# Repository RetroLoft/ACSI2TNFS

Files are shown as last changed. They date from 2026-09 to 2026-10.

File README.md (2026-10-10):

# ACSI2TNFS

A Raspberry Pi Pico 2 W on the **ACSI** (hard disk) port of an Atari ST, STE, Mega ST
or TT. To the Atari it is a hard disk; behind it is Wi-Fi.

- **Drive C:** a small hard disk (about 1 MB) in the Pico's flash. The Atari can boot
  from it.
- **Network drives:** up to three folders on a **TNFS** server (a PC, a NAS or the
  internet) show up as normal drives, readable and writable.
- **Clock:** the Pico gets the time from the internet and sets the Atari's clock at
  start-up.
- **Internet:** with the STinG TCP/IP stack the Atari gets its own IP address on your
  Wi-Fi network: ping, FTP, web pages.

No software to install for the disk part: the adapter brings its own driver. A GEM
program, **ACSITNFS.PRG**, sets up Wi-Fi, network drives, clock and the ACSI id.

> Status: working on real hardware (ST with TOS 1.02/1.04 and EmuTOS). The network
> function (STinG) is new and still being refined.

## What you need

- The ACSI2TNFS board with a **Raspberry Pi Pico 2 W**: `v2` plugs straight into the
  Atari, `v2-cable` connects with a flat cable to a Lotharek DB19 adapter and has a
  pass-through connector. See [hardware/README.md](hardware/README.md).
- An Atari with an ACSI port and **TOS 1.02 or later**, or EmuTOS. TOS 1.0 does not
  see the adapter.
- A 2.4 GHz Wi-Fi network.
- A USB cable for the Pico: it powers the adapter and gives a console on your PC.

## Getting started

1. **Firmware.** Hold the Pico's BOOTSEL button while you plug it into a PC, and copy
   `acsi2tnfs.uf2` onto the drive that appears (build it yourself: see
   [docs/DEVELOPMENT.md](docs/DEVELOPMENT.md)). The Pico restarts and prepares drive C:.
2. **Connect** the adapter to the Atari's ACSI port and power the Pico over USB.
   Switch the Atari on. You see `ACSI2TNFS v…` and `[OK] Drives installed: C:`.
3. **Show C: on the desktop.** Select the floppy A: icon, *Options → Install Disk Drive*,
   letter `C`, *Install*, then *Options → Save Desktop*. C: holds `README.TXT` and the
   programs below.
4. **Set up Wi-Fi and network drives.** Start `C:\ACSITNFS.PRG`: *Config* for Wi-Fi
   (network name, password, country) with *More* for the clock and the ACSI id, and the
   drive list for the TNFS drives (server, folder, drive letter). *Save*; the Pico
   restarts and the Atari with it.

From then on the Atari boots with C:, the network drives and the right time.

### Good to know

- **ACSI id.** A new adapter uses ACSI id **6**, so it does not clash with a hard disk on
  id 0. Every device on the ACSI bus needs its own id.
- **Drive letters** for network drives: D: to P: (TOS knows 16 drives).
- **TOS 1.x with several drives:** put `FOLDR100.PRG` (from Atari's AHDI) in `C:\AUTO`,
  or TOS runs out of folder memory ("use FOLDR100.PRG").
- **Read-only files on C:** `README.TXT`, `ACSITNFS.PRG` and `ACSI_NET.STX` come with
  the firmware. Your own files (DESKTOP.INF, an AUTO folder, …)
  stay when you update the firmware.

More: [docs/ADAPTER.md](docs/ADAPTER.md) (USB console, ACSI id, hidden mode, C:,
troubleshooting) and [docs/TNFS.md](docs/TNFS.md) (network drives, running a TNFS server).

## Internet on the Atari (STinG)

The adapter passes network traffic between the Atari and your Wi-Fi network. The Atari
runs the [STinG](https://github.com/th-otto/STinG) TCP/IP stack (free, for TOS); the
driver `ACSI_NET.STX` on C: connects STinG to the adapter.

**You need:** STinG 1.26 and XControl 1.31 (both free):

| | Download |
|---|---|
| STinG 1.26 | [sting126.lzh](https://chebucto.ns.ca/Services/PDA/sting126.lzh) ([page](https://chebucto.ns.ca/Services/PDA/AtariSTComm.shtml)) |
| XControl 1.31 (control panel for the CPX modules) | [xctl131.zip](https://chebucto.ns.ca/Services/PDA/xctl131.zip) |
| `ACSI_NET.STX` | on C: of the adapter |

**In short:**

1. Install STinG: `STING.PRG` and `STING.INF` in `C:\AUTO`, the `STING` folder with
   `TCP.STX`, `UDP.STX`, `RESOLVE.STX`, `DEFAULT.CFG` and `ROUTE.TAB`.
2. Copy `C:\ACSI_NET.STX` into the `STING` folder.
3. Install XControl (`XCONTROL.ACC` in the root of C:, the STinG CPX modules in `C:\CPX`)
   and restart.
4. *Desk → Control Panel → STinG Port Setup*: port **ACSI2TNFS**, a **free IP address**
   of your network, the subnet mask, **Active**, *Save*.
5. Tell STinG where packets go and who looks up names. With a home network
   `192.168.178.x` and the router on `192.168.178.1` (use your own numbers; on a PC
   `ipconfig` shows them as *Default Gateway* and *Subnet Mask*):
   - `C:\STING\ROUTE.TAB`, instead of the example line (fields separated by tabs):
     ```text
     192.168.178.0	255.255.255.0	ACSI2TNFS	0.0.0.0
     0.0.0.0		0.0.0.0		ACSI2TNFS	192.168.178.1
     ```
     Line 1: your own network, directly. Line 2: everything else via the router.
   - `C:\STING\DEFAULT.CFG`: `NAMESERVER  = 192.168.178.1` (your router).

Test with `PING.PRG` (STinG tools) to your router. Small STinG programs, e.g. a web
page viewer: [Network tools for the Atari ST](https://github.com/RetroLoft/atari-net-tools).

Step by step, with example files and troubleshooting: [docs/NETWORK.md](docs/NETWORK.md).

## Documentation

| | |
|---|---|
| [docs/NETWORK.md](docs/NETWORK.md) | Internet with STinG: installation, IP address, ROUTE.TAB, programs, limits |
| [docs/TNFS.md](docs/TNFS.md) | Network drives: TNFS servers, writing, what to keep in mind |
| [docs/ADAPTER.md](docs/ADAPTER.md) | ACSI id, USB console, system files on C:, TOS versions, troubleshooting |
| [docs/DEVELOPMENT.md](docs/DEVELOPMENT.md) | Building, repository layout, ACSI protocol, test tools |
| `ACSI_NET-ontwerp.md`, `project-notities.md` | Design and project notes (Dutch) |

## Credits

- Configuration program: the ACSI build of
  [SideTNFS-Config](https://github.com/RetroLoft/SideTNFS-Config).
- `ACSI_NET.STX` follows the structure of
  [USB_NET.STX (usbsting)](https://github.com/czietz/usbsting) by Roger Burrows and
  Christian Zietz (GPL-2+), and the frame bridge follows
  [PicoWifi](https://github.com/czietz/picowifi).
- STinG by Peter Rottengatter and Ronald Andersson.

## License

Copyright (C) 2025-2026 Frank Beentjes.

GNU General Public License, version 3 or (at your option) any later version: see
[LICENSE](LICENSE).

- `atari/sting/` (`ACSI_NET.STX`) contains code after USB_NET.STX and is GPL-2.0-or-later
  (`atari/sting/LICENSE`); `atari/sting/include/` holds headers from the STinG developer kit.
- The firmware is built with the Raspberry Pi Pico SDK (BSD-3-Clause), lwIP (BSD) and the
  `cyw43-driver` for the Wi-Fi chip, which Raspberry Pi licenses for use with its own
  microcontrollers only (`lib/cyw43-driver/LICENSE.RP` in the SDK).

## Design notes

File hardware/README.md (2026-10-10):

# ACSI2TNFS hardware

Two boards with the same circuit, so one firmware fits both. Only the connection to the
Atari's ACSI port differs:

| | `v2` | `v2-cable` |
|---|---|---|
| Connection | the board plugs straight into the ACSI port | a 20-wire flat cable to a Lotharek DB19 adapter in the ACSI port |
| Extra parts | 19 special pins for the DB19 | the Lotharek adapter and a flat cable |
| Pass-through | no | yes: a second header for another ACSI device |

> **Firmware:** the current firmware still uses the pin map of the earlier development
> board. A board setting for `v2` / `v2-cable` (different GPIOs, see the pin map below)
> is still to come.

## v2: straight into the ACSI port

The DB19 is part of the board: 19 loose pins soldered into the board take the place of
a DB19 plug (footprint `ACSI_DB19_Male_WAGO_243-131`). The board sits on the back of the
Atari without a cable.

- **Pro:** no adapter and no cable needed.
- **Con:** you need the special pins, e.g. from RS:
  <https://nl.rs-online.com/web/p/terminal-block-accessories/2885173>

## v2-cable: with a Lotharek adapter

The board lies loose behind the Atari and hangs on a Lotharek DB19 adapter through a
20-wire flat cable. That adapter comes with Lotharek's
[UltraSatan](https://lotharek.pl/products.php?id=15): if you already have one, this is the
easiest way.

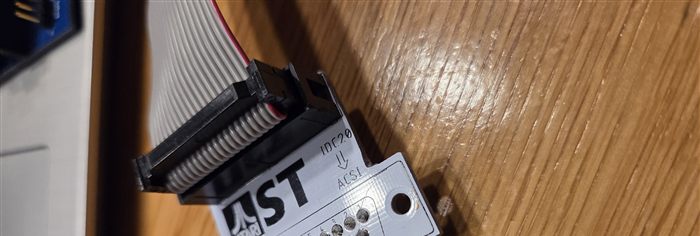
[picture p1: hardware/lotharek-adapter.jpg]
Lotharek DB19 adapter with flat cable


- **J1 "To ACSI"** takes the cable from the adapter. **J2 "ACSI pass-through"** carries
  the same signals on, e.g. to the UltraSatan, which then shares the bus with its own
  ACSI id.
- J1 and J2 are keyed box headers. Their pins are numbered **per row**: 1-10 along the
  row on the side of the key, 11-20 along the other row (footprint
  `IDC-Header_2x10_P2.54mm_Vertical_NR_PER_ROW`).
- So **pin n on the board is ACSI pin n**, because the adapter puts DB19 pins 1-10 on one
  row of its header and 11-19 on the other. This is **not** the usual IDC numbering
  (1 and 2 opposite each other): a standard 2x10 footprint would mix up the signals.
- The cable is a straight 20-wire flat cable with an IDC socket at each end, keyed the
  same way at both ends.

| Pin | Signal | Pin | Signal |
|---|---|---|---|
| 1-8 | DATA0-DATA7 | 11, 13, 15, 17 | GND |
| 9 | /CS | 12 | /RESET |
| 10 | /IRQ | 14 | /ACK |
| | | 16 | A1 |
| | | 18 | R/W |
| | | 19 | /DRQ |
| | | 20 | not used |

## Both boards

- **Raspberry Pi Pico 2 W** on pin headers. The Pico powers the
  board from USB; the ACSI port has no supply pin.
- **U1** 74LVC245: data bus D0-D7, direction (DIR) and enable (/OE) from the Pico.
  **U2** 74LVC245: /CS, /RESET, /ACK, A1 and R/W to the Pico, fixed direction.
  **U3** 74LS07: /IRQ and /DRQ as open-collector outputs.
- **SW1:** button (hidden mode on/off). **J3:** optional micro SD card (3.3 V module).
- **Leds:** D1/D2 are 0805 SMD. `v2-cable` also has D3/D4, the same leds as 3 mm
  through-hole parts on the same resistor: fit **either** D1 **or** D3 (and D2 or D4),
  not both.

### Design rules learnt the hard way

The Atari's floppy controller shares the ACSI data bus and the /IRQ line, so the board
must keep off them when it is not talking:

- **No pull-ups on /IRQ and /DRQ** to the board's own supply: without USB that supply is
  0 V and the resistors pull the lines low, which upsets the floppy drive. The Atari has
  its own pull-ups.
- **10k pull-up on /OE of U1** (R5): the data bus buffer stays off while the Pico is not
  running (power-up, reset, BOOTSEL).
- **10k pull-ups on the 74LS07 inputs** (R6, R7): a Pico in reset pulls its pins low,
  which would otherwise assert /IRQ and /DRQ.

### Pin map (v2 and v2-cable)

| Pico | Signal | Pico | Signal |
|---|---|---|---|
| GP0 | power led | GP16 | /CS |
| GP2-GP5 | SD card: CLK, MOSI, MISO, CS | GP17 | /RESET |
| GP6-GP13 | DATA7 ... DATA0 (reversed order) | GP18 | /ACK |
| GP14 | DIR of U1 | GP19 | A1 |
| GP15 | /OE of U1 | GP20 | R/W |
| GP26 | button | GP21 | /IRQ (via U3, low = active) |
| GP28 | status led | GP22 | /DRQ (via U3, low = active) |

## Files

Each folder is a KiCad 9 project with `schema.pdf`. The project's own footprints are in
`footprints.pretty`; `fp-lib-table` points KiCad to it, so keep it with the project.
There are no Gerber files yet: make them in KiCad (*File > Fabrication Outputs*) from
the version you want to order.

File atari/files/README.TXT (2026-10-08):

ACSI2TNFS - FLASH HARD DISK
===========================

You are reading this file from a Raspberry Pi Pico that acts as
a hard disk on the ACSI port of your Atari.

What is on this disk?
  README.TXT   this file
  ACSITNFS.PRG configuration program (GEM): Wi-Fi, TNFS drives,
               clock and ACSI device ID
  ACSI_NET.STX STinG driver: internet on the Atari (see below)

How does it work?
  - The Pico answers ACSI commands on its own device ID
    (a new adapter: ID 6, see "Changing the ACSI ID").
  - The disk (about 1 MB) lives in the flash memory of the Pico.
  - Sector 0 holds a boot loader. TOS runs it at start-up; it
    loads a small driver that installs the GEM partition as
    drive C: and the TNFS drives after it.
  - Writing works too: the Pico erases and programs flash in
    blocks of 4 KB.

Showing drive C: on the desktop
  Select the icon of floppy A:, choose Options / Install Disk
  Drive, change the letter to C and click Install.
  Then use Options / Save Desktop if you like.

Changing the ACSI ID
  Give every device on the ACSI bus its own ID. If two devices
  share an ID they answer at the same time and neither works;
  ACSITNFS.PRG cannot reach the adapter then either.
  - ACSITNFS.PRG: Config > More > ACSI device ID (after Save
    and a restart).
  - USB console of the Pico: keys 0 to 7. Always works, also
    during a conflict: connect the Pico to a PC over USB and
    open its serial port in a terminal program.

The files above are read-only. Deleted one anyway, or new ones
  missing after a firmware update? Key R on the USB console puts
  them on C:; your own files stay. No reset needed: the driver
  tells TOS that C: changed.

USB console of the Pico (any baud rate, it is USB):
  0-7 = ACSI ID           H = hide/show           K = clock on/off
  R = restore system files on C:                  F = rewrite C:
  i = info                n = network status      B = BOOTSEL

BOOTSEL button on the Pico: short press = hide/show (like H). While
hidden the Pico's led blinks slowly. Reset the Atari after pressing it.

With a Pico W / Pico 2 W: set up Wi-Fi, the TNFS drives and the
clock with ACSITNFS.PRG.

Drive letters and TOS versions
  - TOS knows 16 drives: TNFS drives get a letter from D: to P:.
  - TOS 1.x with several drives: put FOLDR100.PRG (AHDI) in
    C:\AUTO, or GEMDOS runs out of folder memory.
  - EmuTOS mounts the drives itself as C:, D:, E:, ...; the
    chosen letters and the network clock do not apply there.
  - TOS 1.0 does not see the adapter.

Internet with STinG
  ACSI_NET.STX gives the Atari its own IP address on your Wi-Fi
  network, through the Pico. You need STinG 1.26 and a control
  panel (XControl) to set it up:
  1. Copy ACSI_NET.STX into your STING folder.
  2. STNGPORT.CPX: port ACSI2TNFS, a free IP address of your
     network (not one your router hands out), the subnet mask,
     tick Active, Save.
  3. ROUTE.TAB: your network and a default route via your
     router through the port ACSI2TNFS.
  Step by step: docs/NETWORK.md, github.com/RetroLoft/ACSI2TNFS

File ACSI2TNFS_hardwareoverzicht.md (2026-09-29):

# ACSI2TNFS – hardwarebrief voor Claude

**Bron en reikwijdte:** dit overzicht is uit de meegeleverde KiCad 9-bestanden `acsi2tnfs(1).kicad_sch` en `acsi2tnfs.kicad_pcb` afgeleid. Pin-/nettoewijzingen hieronder zijn gecontroleerd op de **PCB-padnetten**. Dit beschrijft de **oorspronkelijke Raspberry Pi Pico W-variant**; niet de afzonderlijk besproken ESP32-S3/FPGA-universele adapter of de floppy-emulator. Er is geen firmware meegeleverd, dus softwaregedrag en werkelijke ACSI-timing mogen niet uit de hardware worden afgeleid. PCB-nettoewijzingen alleen bewijzen evenmin dat elke verbinding fysiek doorgemeten is.

## 1. Wat de hardware moet doen

Een externe Atari ACSI/DMA-peripheral met een Raspberry Pi Pico W als controller, 8-bit bidirectionele ACSI-databus via een SN74LVC245A, vijf host-naar-Pico-controlsignalen via een tweede SN74LVC245A, twee actief-laag interrupt-/DMA-handshake-uitgangen via NPN open-collectorachtige schakelingen, en een SPI-header voor externe 3,3V-SD-kaartmodule. Pico W heeft eigen Wi-Fi en USB. J2 brengt de ACSI-signalen naar een 20-polige header voor een kabel/adapter naar de 19-polige Atari ACSI D-sub. J4 is een tweede parallel aangesloten 20-polige debugheader.

### Spanningsdomeinen
- ACSI-zijde: 5V TTL-compatibel; Pico W GPIO: 3,3V (niet rechtstreeks 5V-tolerant).
- U1 en U2: SN74LVC245A gevoed uit Pico's 3,3V-uitgang. Hun inputs accepteren volgens TI tot 5,5V; 3,3V-uitgangen sturen TTL-compatibele ACSI-ingangen.
- `+5V` is op dit ontwerp gekoppeld aan Pico W pin 40 (`VBUS`) en voedt de lokale pull-ups/C5. **De ACSI-poort levert geen voedingsspanning.** De 5V komen dus niet van J2.
- Pico W pin 36 (`3V3_OUT`) voedt `+3.3V`, de beide transceivers, SD-header en leds.

## 2. Exacte Pico W GPIO-indeling (PCB A1)

| Pico GPIO | Pico fysieke pin | PCB-net | Functie / signaalpad |
|---|---:|---|---|
| GP0 | 1 | `UART0_TX` | Debug-J1 pin 1, UART0 TX |
| GP1 | 2 | `UART0_RX` | Debug-J1 pin 2, UART0 RX |
| GP2 | 4 | `CLK` | SD-J3 pin 4, SPI0 SCK |
| GP3 | 5 | `MOSI` | SD-J3 pin 3, SPI0 TX/MOSI |
| GP4 | 6 | `MISO` | SD-J3 pin 5, SPI0 RX/MISO |
| GP5 | 7 | `CS` | SD-J3 pin 2, SPI0 chip-select |
| GP6 | 9 | `/OE` | U1 pin 19, active-low enable van bidirectionele databuffer |
| GP7 | 10 | `DIR` | U1 pin 1, richting databuffer |
| GP8 | 11 | `DATA0_3V3` | U1 pin 18, ACSI D0 |
| GP9 | 12 | `DATA1_3V3` | U1 pin 17, ACSI D1 |
| GP10 | 14 | `DATA2_3V3` | U1 pin 16, ACSI D2 |
| GP11 | 15 | `DATA3_3V3` | U1 pin 15, ACSI D3 |
| GP12 | 16 | `DATA4_3V3` | U1 pin 14, ACSI D4 |
| GP13 | 17 | `DATA5_3V3` | U1 pin 13, ACSI D5 |
| GP14 | 19 | `DATA6_3V3` | U1 pin 12, ACSI D6 |
| GP15 | 20 | `DATA7_3V3` | U1 pin 11, ACSI D7 |
| GP16 | 21 | `/CS_3V3` | Host `/CS` via U2 |
| GP17 | 22 | `/RESET_3V3` | Host `/RESET` via U2; R7 100k naar GND |
| GP18 | 24 | `/ACK_3V3` | Host ACK via U2 (netnaam op PCB `/ACK`) |
| GP19 | 25 | `A1_3V3` | Host A1 via U2 |
| GP20 | 26 | `R/W_3V3` | Host R/W via U2 |
| GP21 | 27 | `Net-(A1-GPIO21)` | Via R5 4k7 naar basis Q1 (BC547); hoog = `/IRQ` laag |
| GP22 | 29 | `Net-(A1-GPIO22)` | Via R2 4k7 naar basis Q2 (BC547); hoog = `/DRQ` laag |
| GP28 | 34 | `STATUS_LED` | Via R4 330Ω naar D2 led, vervolgens GND; hoog = aan |

**Overige aansluitingen A1:** fysieke pinnen 3/8/13/18/23/28/33/38 = GND; 36 = `+3.3V` (`3V3_OUT`); 40 = `+5V` (`VBUS`). Fysieke pinnen 30 (RUN), 31 (GP26), 32 (GP27), 35 (ADC_VREF), 37 (3V3_EN), 39 (VSYS) zijn in de PCB als niet aangesloten aangegeven. GP23–GP25 van de Pico W zijn geen vrije gewone header-I/O voor dit ontwerp; bouw de firmware op bovenstaande fysieke aansluitingen.

## 3. ACSI D-sub 19 pinout en J2/J4-koppeling

De PCB gebruikt **twee 2x10 headers J2 en J4 met parallelle netten**. Beiden hebben pinnen 1–19 met onderstaande ACSI-pinnummers, en pin 20 = niet aangesloten. J2 heet `To ACSI`, J4 `Debug Header`. De PCB zelf bevat **geen DB-19 D-sub-footprint**. Controleer de fysieke oriëntatie van de custom 2x10-footprint en de kabel naar een Atari-connector: een 1-op-1 genummerde netlijst is NIET hetzelfde als gegarandeerd correcte flatcable-/IDC-oriëntatie.

| ACSI pin = J2/J4 pin | Signaal | Richting t.o.v. Atari host | Betekenis |
|---:|---|---|---|
| 1 | D0 | bidirectioneel | Data bit 0 |
| 2 | D1 | bidirectioneel | Data bit 1 |
| 3 | D2 | bidirectioneel | Data bit 2 |
| 4 | D3 | bidirectioneel | Data bit 3 |
| 5 | D4 | bidirectioneel | Data bit 4 |
| 6 | D5 | bidirectioneel | Data bit 5 |
| 7 | D6 | bidirectioneel | Data bit 6 |
| 8 | D7 | bidirectioneel | Data bit 7 |
| 9 | `/CS` | Atari → device | Active-low chip select / software handshake |
| 10 | `/IRQ` | device → Atari | Active-low interrupt/status request; uitgang Q1 |
| 11 | GND | — | Massa |
| 12 | `/RESET` | Atari → device | Active-low hardware-reset |
| 13 | GND | — | Massa |
| 14 | `ACK` (PCB-net `/ACK`) | Atari → device | DMA acknowledge, handshakesignaal |
| 15 | GND | — | Massa |
| 16 | A1 | Atari → device | Adres-/selectiesignaal |
| 17 | GND | — | Massa |
| 18 | R/W | Atari → device | Transferrichting |
| 19 | `/DRQ` | device → Atari | Active-low DMA data request; uitgang Q2 |
| 20 | NC (alleen header) | — | Niet aanwezig op de 19-polige ACSI-poort |

**Signaalnaam-opmerking:** De PCB heeft `/ACK` als netnaam waar externe documentatie vaak `ACK` schrijft. Gebruik de daadwerkelijke hardware- en timingdefinitie, niet alleen een slash in een KiCad-label, om logische polariteit te bepalen. De pinbenaming `R{slash}W` in KiCad wordt hier als R/W weergegeven.

## 4. Componenten (waardes en footprint uit de meegeleverde KiCad-bestanden)

| Ref. | Component / waarde | Footprint | Aansluiting en bedoeling |
|---|---|---|---|
| A1 | Raspberry Pi Pico W | `Module:RaspberryPi_Pico_Common_THT` | Hoofdcontroller + Wi-Fi + USB |
| U1 | `SN74LVC245APW` *schemawaarde* | `Package_SO:SOIC-20W_7.5x15.4mm_P1.27mm` | Bidirectionele ACSI D0–D7 ↔ GP8–15; VCC 3,3V, DIR=GP7, /OE=GP6 |
| U2 | `SN74LVC245APW` *schemawaarde* | dezelfde SOIC-20W | Vaste A→B-richting: /CS, /RESET, /ACK, A1, R/W → GP16–20. DIR (pin 1) aan 3,3V; /OE (pin 19) aan GND. De drie ongebruikte kanaalparen zijn aan GND geknoopt. |
| Q1 | BC547 NPN | `Package_TO_SOT_THT:TO-92_Inline` | Collector `/IRQ`, basis via R5 vanaf GP21, emitter GND |
| Q2 | BC547 NPN | zelfde TO-92 | Collector `/DRQ`, basis via R2 vanaf GP22, emitter GND |
| R1 | 3k3 | 0805 | `/IRQ` pull-up naar +5V |
| R2 | 4k7 | 0805 | GP22 → Q2-basis |
| R3 | 330Ω | 0805 | +3,3V → D1 (power-led) |
| R4 | 330Ω | 0805 | GP28 → D2 (status-led) |
| R5 | 4k7 | 0805 | GP21 → Q1-basis |
| R6 | 3k3 | 0805 | `/DRQ` pull-up naar +5V |
| R7 | 100k | 0805 | `/RESET_3V3` pulldown naar GND |
| R8 | 100k | 0805 | U1 `/OE` pulldown naar GND |
| R9 | 100k | 0805 | U1 `DIR` pull-up naar +5V (TI bevestigt 5,5V inputtolerantie; blijft een controlepunt) |
| C1 | 10µF | 0805 | +3,3V naar GND |
| C2, C3, C4 | 100nF elk | 0805 | +3,3V naar GND, ontkoppeling |
| C5 | 10µF | 0805 | +5V naar GND |
| D1 | LED | `LED_0805_2012Metric` | 3,3V power-led, via R3 aan +3,3V, kathode GND |
| D2 | LED | `LED_0805_2012Metric` | Status-led via R4/GP28, kathode GND |
| J1 | Debug 1x3 | 2,54mm THT pinheader | Pin 1 TX, pin 2 RX, pin 3 GND |
| J2 | To ACSI 2x10 | custom `Library:PinHeader_2x10_P2.54mm_Vertical_NR_PER_ROW` | ACSI pin 1–19 + NC20 |
| J3 | To SD card 1x6 | 2,54mm THT pinheader | 1=3,3V; 2=CS; 3=MOSI; 4=CLK; 5=MISO; 6=GND |
| J4 | Debug Header 2x10 | zelfde custom footprint als J2 | 100% dezelfde ACSI-signalen als J2 |

**LET OP: U1/U2 partnummer/footprint-inconsistentie:** de schemawaarde eindigt op `PW` (TSSOP-20-variant), maar de werkelijk getekende PCB-footprint is een grote SOIC-20W met 1,27mm pitch. Kies voor assemblage een elektrisch equivalente, bij die SOIC-footprint passende exacte bestelvariant en wijzig de BOM/schemawaarde. Plaats geen PW/TSSOP op deze SOIC-pads. Het is kennelijk een latere aanpassing voor gemakkelijker handsolderen.

### Gedrag van de twee transceivers
- U1 A-kant (pinnen 2–9) = ACSI `DATA0..7` en B-kant (pinnen 18–11) = Pico `DATA0..7_3V3`.
- TI-functietabel: `OE=1` = beide zijden high-Z; bij `OE=0, DIR=1` gaat A→B (Atari→Pico); bij `OE=0, DIR=0` gaat B→A (Pico→Atari).
- U1 `/OE` heeft **R8 pulldown**: standaard enabled, niet automatisch high-Z tijdens de Pico-boot. U1 `DIR` heeft R9 pull-up: standaard A→B. Voor veilig loskoppelen tijdens reset/boot of multi-devicebus, dit expliciet meenemen in de firmware en eventueel hardware aanpassen. TI adviseert /OE normaal pull-up voor high-Z bij power-up/down.
- U2 is permanent enabled A→B: /CS, /RESET, /ACK, A1 en R/W worden als 3,3V-inputsignalen aangeboden aan de Pico. U2 wordt nooit naar B→A geschakeld.
- Q1/Q2 zijn low-side-schakelaars: GP21/22 hoog zet de betreffende `/IRQ`/`/DRQ`-lijn laag, GPIO laag laat de externe pull-up hem hoog maken. Houd deze GPIO's tijdens boot standaard laag/input totdat firmware de bus werkelijk mag bedienen. De pinnen `/IRQ` en `/DRQ` zijn geen 3,3V push-pull-Pico-uitgangen.

## 5. Wat Claude over Atari ACSI moet weten

- **ACSI = Atari Computer System Interface**, de externe 19-polige D-sub DMA-randapparatuurpoort van de Atari ST-familie (ST/STE/Mega/Mega STE/TT met ACSI). De Falcon heeft géén gelijkwaardige externe ACSI-poort; verwar die niet met Falcon SCSI/IDE.
- ACSI is een **8-bit, TTL-signaalbus**, SCSI-/SASI-achtig op commandoniveau, maar geen gewone 50-pins SCSI-bus. De **Atari is de initiator/host** die de transactie bestuurt; een ACSI-doelapparaat reageert. Geen SCSI Message Phase of normale SCSI bus arbitration.
- ACSI heeft twee handshakevarianten: CPU-gestuurde command-/statusbytecommunicatie via host `/CS` en device `/IRQ`, en DMA-dataoverdracht met device `/DRQ` en host `ACK`. Richting en adresselectie via `R/W` en `A1`. Gebruik de officiële timingdiagrammen voor precieze flanken; niet alleen aannames op basis van signaalnamen.
- Een standaard ACSI-commandoblok is historisch **6 bytes**; de hoogste 3 bits van byte 0 bevatten de ACSI controller-ID (0–7). Device-/logical-unit-adressering zit in de overige commandovelden; precieze opcodes/uitbreidingen zijn driverafhankelijk. Dataoverdracht is vaak in blokken van 512 bytes.
- Er zijn maximaal 8 logische controller-ID's; volgens Atari's Integration Guide is maximaal 4 fysieke controllers daisy-chainen aan te houden voor betrouwbaarheid. De ACSI-poort heeft **geen +5V-voedingspin**.
- **ACSI elektrisch niet als SCSI termineren** enkel omdat de namen op elkaar lijken: original ACSI gebruikt TTL-/CMOS-businterfacing, geen standaard passieve SCSI 220/330Ω terminatienetwerken. Houd de kabel kort en controleer grounding.
- Timing is krap. Wi-Fi/TNFS/SD mag real-time DRQ↔ACK-handshake niet blokkeren. Denk aan PIO/DMA/interrupt-architectuur, expliciete direction/OE en een buffer tussen trage backend en timingkritische Atari-interface. Houd multi-target / gedeelde bus in gedachten.
- P. Putnik publiceerde praktijkmetingen: ongeveer 2MB/s piek tijdens sector-DMA mogelijk op geteste Atari's, tegenover de vaak geciteerde 1–1,25MB/s in documentatie; dit is een **ervarings-/meetresultaat**, geen universele garantie. Hij waarschuwt ook voor timingproblemen bij de laatste bytes van een sector bij zijn CF-adapter. Baseer firmware op de officiële timing én metingen aan het eigen board.

## 6. Uitdrukkelijke reviewpunten voor Claude

1. Gebruik de meegeleverde KiCad-schema- en PCB-netten als single source of truth voor dit concrete board; wijzig ze niet stilzwijgend naar een andere GPIO-map uit een ouder Pico-project of naar de ESP32/FPGA-boardarchitectuur.
2. Controleer de echte ACSI D-sub-connectororiëntatie/kabel naar J2, en de custom 'NR_PER_ROW' nummering; pin20 is NC.
3. Verifieer U1/U2 **SOIC-footprint versus `...PW` TSSOP-componentnaam** en selecteer passend bestelnummer.
4. Beoordeel power-up failsafe: U1 `/OE` heeft default LOW, dus geen automatische high-Z; DIR default HIGH. U2 is altijd enabled. Denk na over gelijktijdig actieve ACSI-devices en ongewenst bus-driving.
5. Verifieer polariteit/actieve flank van ACK: KiCad gebruikt `/ACK`, referenties soms `ACK`; volg Atari timinggids en meet.
6. Check BC547 C/B/E in de specifieke gekozen fabrikant/TO-92-montage; gebruik geen ongecontroleerd 'standaard SOT-23'-pinout.
7. ACSI biedt géén voeding: USB/Pico VBUS moet +5V voor pull-ups leveren. Valideer elektrisch gedrag bij Atari aan, Pico uit en omgekeerd.
8. Firmware mag `/IRQ` en `/DRQ` slechts via GP21/GP22 en Q1/Q2 aansturen; maak ze bij init inactief.
9. Bevestig dat SD-module **3,3V** werkt en niet een module met vereist 5V-ingang gebruikt. J3 bevat geen extra SD-levelshifter/regulator.
10. Firmware, timing en ondersteunde commandoset zijn **niet** onderdeel van deze meegeleverde bestanden; speculeer er niet over alsof ze al geïmplementeerd zijn.

## 7. Mee te geven documentatie (directe URLs)

Verplichte gebruikerslinks:

1. Praktijkervaring en correcties, P. Putnik: https://atari.8bitchip.info/AcsiDmaExD.html
2. Atari ACSI/DMA pinout: https://allpinouts.org/pinouts/connectors/parallel/atari-acsi-dma/
3. AtariForumWiki, ACSI en Atari hardware specification: https://temlib.org/AtariForumWiki/index.php/ACSI

Aanvullend teruggevonden originele documenten:

4. **ATARI ACSI/DMA Integration Guide, 28 juni 1991 – originele handleiding, 48 pagina's, timingdiagrammen, software/DMA-handshake en connectoren:** https://archive.org/download/ACSI_DMA_Guide_6-28-1991/ACSI_DMA_Guide_6-28-1991.pdf
5. Internet Archive-item: https://archive.org/details/ACSI_DMA_Guide_6-28-1991
6. **Application Notes on the Atari Computer System Interface (ACSI), 27 september 1985:** https://www.bitsavers.org/pdf/atari/ST/Atari_ST_GEM_Programming_1986/GEM_0942.pdf
7. **Atari ST ProfiBuch** (de uitgave uit 1987 wordt specifiek aangehaald op Putniks pagina; een latere herziene ST/STE/TT-PDF is online): https://julian-reschke.de/ATARI%20Profibuch%20ST-STE-TT.pdf
8. TI SN74LVC245A-datasheet (function table, 5,5V input, power-up high-Z-advies): https://www.ti.com/lit/ds/symlink/sn74lvc245a.pdf

**Verzoek aan Claude:** lees eerst de KiCad-bestanden en de officiële 1991 ACSI/DMA Integration Guide. Geef een ontwerp-/firmwarereview die elektrische veiligheid, hardwarehandshake, direction/high-Z, multi-devicebus en real-time verwerking expliciet afdekt. Scheid geverifieerde boardfeiten van aannames of verbetervoorstellen.

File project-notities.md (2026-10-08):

# ACSI2TNFS – projectnotities

## Hardware: /DRQ (Q2, BC547) laat te traag los

Probleem: na het loslaten blijft /DRQ ongeveer 1 µs laag, omdat de BC547 verzadigd is. De firmware vangt het op, maar elektrisch valt het buiten de specificatie.

Mogelijke wijzigingen, in volgorde van voorkeur:

1. **100 pF parallel aan R2** (4k7 naar de basis van Q2). Eventueel tot 220 pF; een 0805 kan bovenop R2.
2. **Schottky-diode** (BAT85/BAT43): anode aan de basis, kathode aan de collector van Q2. Doet hetzelfde, nog robuuster.
3. **Volgende PCB:** een open-drain buffer (74LVC1G07 / 74LS07) in plaats van de transistoren. **v1 testen?** (v1 heeft al een 74LS07)

Niet doen: de BC547 vervangen door een ander bipolair type (zelfde probleem) of door een 2N7000/BS170 (drempel te hoog voor 3,3 V).

R5 (IRQ) hoeft niet; daar is de timing ruim.

**Controle na de wijziging:** in de Pico-log geeft een read nu `acks=514`. Na een geslaagde wijziging moet dat `acks=512` zijn.

## Hardware: U1 (databus) moet uit staan zolang de Pico niet draait (R7, R8, R9)

In het schema (`hardware/dev`) zitten drie weerstanden van 100 kΩ, die op de huidige print niet geplaatst zijn:

| | Net | Naar | Bedoeling |
|---|---|---|---|
| R7 | /RESET_3V3 (U2 → GP17) | GND | /RESET gedefinieerd houden |
| R8 | /OE van U1, de databus (GP6) | GND | U1 aan tijdens het opstarten van de Pico |
| R9 | DIR van U1 (GP7) | +5V | richting Atari → Pico tijdens het opstarten |

Ze doen ertoe op het moment dat de Pico **niet** onze firmware draait: bij het aanzetten, bij een reset en in BOOTSEL (flashen). Dan zijn GP6/GP7 ingangen.

**Probleem zonder R8/R9:** de RP2040 en RP2350 zetten na een reset een **interne pull-down** (~50 kΩ) op hun GPIO's. Dan is /OE laag (U1 aan) en DIR laag (richting **Pico → Atari**). U1 drijft dan de ACSI-datalijnen van de Atari laag zolang de Pico in reset of BOOTSEL staat. Valt er op dat moment een ACSI-overdracht (de DMA-chip stuurt een commando, een andere schijf antwoordt), dan vechten twee uitgangen tegen elkaar. Dat het bij het vele flashen met de Atari aan goed ging, komt doordat de Atari toen zelden de bus gebruikte.

**R9 naar +5 V is geen goede oplossing:**

1. **Te zwak:** 100 kΩ tegen de interne pull-down van ~50 kΩ geeft ~1,7–2,2 V op DIR, net geen geldige "hoog" voor de LVC245.
2. **Verkeerde spanning:** DIR hangt ook aan GP7. 5 V via een weerstand op een GPIO is op de RP2040 buiten de specificatie (stroom met 100 kΩ heel klein, maar niet netjes), en staat er ook als de Atari aan is en de Pico niet.

**Advies voor de print:**

- **R8 als pull-up van 10 kΩ naar +3,3 V** (in plaats van een pull-down naar GND). Zolang de Pico niet draait staat U1 dan **uit**: de bus van de Atari is niet aangesloten, in welke stand dan ook. De firmware zet U1 bij het opstarten zelf aan (/OE laag, DIR hoog), daar verandert niets aan.
- **R9 vervalt** zodra /OE gegarandeerd uit staat: de richting doet er dan niet toe. Houd je hem toch, dan 10 kΩ naar **+3,3 V**.
- **R7 mag weg:** U2 staat altijd aan en drijft /RESET op GP17 zodra de 3,3 V er is.

**Op de huidige print:** een 10 kΩ van GP6 (/OE, U1 pin 19) naar 3,3 V is de belangrijkste. R7 en R9 leeg laten.

## Hardware: storing op de diskettedrive (8 oktober 2026)

**Klacht:** met de dev-print aan de ST gaat de diskettedrive mis: een lege desktop, of bestandsnamen met vreemde tekens. Het gebeurt ook als de adapter hidden staat, en ook als de print helemaal uit staat (geen USB).

**Waarom de diskette:** in de ST delen de diskettecontroller (WD1772) en de ACSI-poort dezelfde databus D0–D7 aan de DMA-chip. De interrupt van de ACSI-poort (/IRQ, pin 10) en die van de diskettecontroller komen samen op MFP GPIP5; daarmee ziet TOS dat een diskettebewerking klaar is. Wat deze lijnen belast, raakt dus ook de diskette. Hidden helpt niet: dat verandert alleen de firmware, de print blijft elektrisch op de bus. De firmware zet /IRQ alleen bij een commando aan het eigen ID (hidden: alleen $11) en reageert niet op diskettetoegang.

**Hoofdverdachte (print uit):** R1 en R6, de pull-ups van 3k3 op /IRQ en /DRQ, gaan naar de +5V van de print zelf (VBUS van de Pico). Zonder USB is die rail 0 V, en trekken ze de lijnen omlaag in plaats van omhoog. Een lage /IRQ ziet TOS als "diskette klaar". Bovendien kan de ST via deze weerstanden een beetje stroom de print in duwen en de Pico en U1 half voeden.

**Regels voor elke print:**
- **/IRQ en /DRQ:** zonder voeding hoogohmig; met voeding alleen naar massa trekken tijdens ons eigen commando. Geen pull-ups naar de eigen 5V (of 3,3V) van de print.
- **Datalijnen:** naar de ST toe altijd ingang (U1 richting ST → Pico) of hoogohmig (U1 uit). Alleen tijdens de leesdata en de statusbyte van ons eigen commando stuurt U1 de bus.
- **U1:** /OE met een pull-up naar 3,3V, zodat hij uit staat zolang de Pico niet draait. Zonder voeding schakelt de LVC245 zijn uitgangen uit (partial power-down, I_off).

**v2-schema (`hardware/v2`), gecontroleerd met de netlist:**

| Onderdeel | In v2 | Oordeel |
|---|---|---|
| R1 (/IRQ) en R2 (/DRQ) naar +5V | NC, niet geplaatst | goed, niet plaatsen |
| R5 10k, /OE van U1 (GP15) naar 3,3V | geplaatst | goed |
| U3 74LS07 op +5V | open collector op /IRQ en /DRQ; zonder voeding hoogohmig | goed |
| R6/R7 10k naar 3,3V op de LS07-ingangen | geplaatst | nodig: bij v2 betekent een lage GPIO "aan" |
| U1/U2 74LVC245 op 3,3V | zonder voeding uitgangen uit | goed |
| U2 | /OE aan GND, DIR hoog: alleen ST → Pico | goed |
| DIR van U1 (GP14) | geen pull | niet nodig, R5 houdt U1 uit |

Open punt: v2 rekent erop dat de ST zelf pull-ups heeft op /IRQ en /DRQ. Dat bevestigt de meting hieronder.

**Plan voor de dev-print:**
1. **10k van GP6 (U1 pin 19, /OE) naar 3,3V.** Let op: niet op de pads van R8 zelf, die gaan naar GND (pull-down).
2. **Meten op de ST, print los, ST aan,** ten opzichte van GND:
   - pin 10 (/IRQ) en pin 19 (/DRQ): verwacht ongeveer 5 V (pull-ups in de ST);
   - een paar datalijnen (pin 1–8): mogen zweven.
3. Geven pin 10 en 19 ongeveer 5 V: **R1 en R6 (3k3) eraf halen.** Zweven ze of zijn ze laag, dan zijn pull-ups wel nodig, maar niet naar de 5V van de print; dan opnieuw bekijken.
4. Ter controle met de print aangesloten en zonder USB: pin 10 en 19 weer meten, en Pico pin 36 (3V3) moet 0 V zijn (geen terugvoeding).
5. Diskettetest: print los / aangesloten zonder USB / aan / aan en hidden. Voor "aan" ook met een losse USB-lader in plaats van de laptop (massastoring).
6. Stoort hij aan en hidden nog steeds, dan zit de oorzaak ergens anders (massa via USB, bus of kabellengte). Dan kijkt de Pico-console mee (verbose) tijdens een diskettetest.
7. Optioneel: het ST-schema erbij voor de pull-ups op HDINT/HDRQ en GPIP5.

**Uitkomst (8 oktober 2026):** de storing met de print **aan** kwam niet van de hardware maar van ACSI_NET.STX. Zonder STinG (STING.PRG hernoemd) werkte de diskette goed, en met hidden bij het opstarten ook (dan laadt er niets van C:). De Pico-log liet afgebroken NET_RX-commando's zien (`acks=28`, `TIMEOUT`, `PROTOCOL`): de STX nam de DMA-chip over midden in een diskettebewerking. De STX nam flock met `TAS`, en dat test alleen de hoogste bit van het woord. STX 00.07 neemt flock alleen als het hele woord 0 is, met de interrupts uit. Getest: diskette werkt met STinG aan, geen TIMEOUT/PROTOCOL meer, en `URLVIEW -o B:` (300.000 bytes van de laptop naar RadioFloppy op B:, tegelijk diskette en netwerk) gaf een identiek bestand (MD5). Traag, omdat de STX netjes wacht zolang TOS de diskette gebruikt.

De storing met de print **uit** kwam wel van de hardware: R1 en R6 (3k3 naar de eigen 5V) zijn eraf, en daarmee is die weg.

**v1-print testen (met de 74LS07):** v1 heeft al de open-collector LS07 die v2 ook gebruikt, en is dus een goede proef voor de v2-aanpak. Netlist van `hardware/v1`, verschillen met de dev-print en v2:

| | dev-print (huidige firmware) | v1 | v2 |
|---|---|---|---|
| D0..D7 | GP8..GP15 | GP6..GP13 | GP13..GP6 (omgekeerd) |
| DIR / /OE van U1 | GP7 / GP6 | GP14 / GP15 | GP14 / GP15 |
| /CS, /RESET, /ACK, A1, R/W | GP16..GP20 | gelijk | gelijk |
| /IRQ, /DRQ (GP21/22) | BC547: hoog = aan | LS07: **laag = aan** | LS07: laag = aan |
| pull-up op /OE | geen (R8 is pull-down) | **geen** | R5 10k |
| pull-ups op LS07-ingangen | n.v.t. | **geen** | R6/R7 10k |
| R1/R2 pull-ups 3k3 naar eigen +5V | R1/R6 geplaatst | **geplaatst** | NC |

Nodig voor de test:
1. **Firmware met een bordinstelling** (stond al op de lijst): pinmap en polariteit van /IRQ en /DRQ per print. Let op: op v1 en v2 liggen de datalijnen en de stuurlijnen niet aaneengesloten (GP14/15 ertussen), en op v2 is de databus omgekeerd. Dat vraagt aanpassingen in de PIO-programma's (bijvoorbeeld 15 bits samplen; omkeren kan in PIO met `mov` en `::`).
2. **10k pull-ups naar 3,3V op GP21 en GP22** (LS07-ingangen). Zonder die weerstanden zet de interne pull-down van de Pico in reset of BOOTSEL de LS07-ingangen laag, en trekt de LS07 /IRQ en /DRQ laag zolang de print voeding heeft. Dat stoort de diskette ook.
3. **10k van GP15 (/OE, U1 pin 19) naar 3,3V**, net als R5 op v2.
4. **R1 en R2 (3k3) eraf**, als de meting op de ST (stap 2 hierboven) ongeveer 5 V geeft.
5. Dan dezelfde tests als op de dev-print: diskette met de print los / uit / aan / hidden, schijf en netwerk, en de /DRQ-loslaattijd (in de log `acks=512` in plaats van 514).

## ACSI_NET fase 1: testverslag (4 oktober 2026)

Ontwerp: `ACSI_NET-ontwerp.md`. Getest op de ST (TOS 1.04) met `NETTEST.TTP` van een TNFS-drive (log in `NETTEST.LOG`) en de Pico-log, adapter op ACSI-ID 6.

| Test | Resultaat |
|---|---|
| Oude firmware (zonder netwerkfunctie) | NET_INFO → status 2 → "Network function not supported" |
| NET_INFO | protocol 1, MAC, IP/masker/gateway van de Pico, Wi-Fi-status kloppen |
| **Korte DMA-read**: Atari programmeert 3 sectoren, Pico stuurt er 1, 2 of 3 | 2300 rondes per grootte (6900 commando's): 0 fouten, DMA-status steeds ok, niets geschreven voorbij de data |
| Sector 0 lezen tussen elke ronde (diskpad) | 2300 keer, 0 fouten |
| NET_CTRL aan (192.168.178.50/24) | opgeslagen, zichtbaar in NET_INFO en console `w` |
| NET_CTRL met het IP van de Pico | geweigerd (status 2, sense $24, resultaat 4); vorige instelling blijft |
| Onbekende sub $2E | geweigerd (status 2, sense $20) |
| NET_CTRL uit | opgeslagen |

Duur per commando (Atari, inclusief Supexec; Pico-kant tussen haakjes): 1 sector ~0,74 ms (0,50 ms), 2 sectoren ~1,13 ms (0,83 ms), 3 sectoren ~1,50 ms (1,18 ms). De Pico telde steeds 2 /ACK's meer dan bytes (n×512+2), hetzelfde als bij disk-reads (trage /DRQ, BC547).

**Conclusie:** de korte DMA-read is betrouwbaar. NET_RX kan dus zoals ontworpen: de Atari vraagt altijd 3 sectoren, en een lege poll kost 1 sector (~0,75 ms). Een aparte NET_POLL is niet nodig.

## ACSI_NET fase 2: testverslag (4 oktober 2026)

Frame-brug op de Pico (filter op `netif->input`, RX-ring 8, TX-ring 4, TX via een worker in de cyw43-context). Getest met `NETTEST A/L/R/D`, tussendoor steeds 16 KB-reads van `C:\ACSITNFS.PRG` en `F:\GAMES\BIG.BI4` (TNFS), vergeleken met een referentie.

| Test | Resultaat |
|---|---|
| `NETTEST A`: ARP-request vanaf de Atari naar de router | antwoord van 192.168.178.1 na 255 ms; 31 NET_RX-polls, 0 fouten |
| `NETTEST L`: ARP van de laptop voor 192.168.178.50 | 9 requests ontvangen en beantwoord; daarna 14 ICMP-echo's van de laptop ontvangen |
| NET_TX | 18 frames verzonden, 0 BUSY, 0 geweigerd, 0 zendfouten |
| NET_RX | 411 polls, 0 fouten; 0,47–1,1 ms per poll |
| Bestand-reads tijdens A en L | C: 97, F: 96, 0 fouten |
| Brug aan, niemand pollt (kopieertest) | ring vol → 147 frames gecontroleerd gedropt, geen invloed op disk/TNFS |
| `NETTEST D` | brug uit, filter weg, performance-mode uit |

**Gevonden en opgelost tijdens fase 2 (bestaand leespad, niet het netwerk):** de Pico zette na /ACK te snel de volgende byte op de bus; de DMA-chip las dan af en toe die volgende byte. NETTEST zelf laadde zo beschadigd (`LINK A6,#$ffec` → `#$ecec`, bommen). Hold na /ACK van ~50 ns naar ~130 ns (`acsi_bus.pio`). Daarna `NETTEST R`: 5984 KB, 0 fouten; in totaal 1538 reads zonder één /ACK-afwijking; snelheid gelijk (16 KB van C: in 11,4 ms).

**Gevonden, nog open (TNFS-schrijven, niet het netwerk):** bij het kopiëren van GAMES naar `F:\WRITE` duurde de sync van een bestand van 405 KB 9,65 s. Een read van de TNFS-drive die in die tijd binnenkwam, wachtte op core0 en gaf na 9 s een leesfout → het kopiëren brak af (`DATA_002.DEL` e.v. ontbreken). Gekopieerde bestanden zijn wel correct. Oplossing: de sync laat tussendoor wachtende reads voor gaan, of wordt in stukjes gedaan.

## ACSI_NET fase 3: testverslag (4 oktober 2026)

`ACSI_NET.STX` (skelet, 2,9 KB) onder STinG 1.26 met XControl 1.31; STinG-map op de TNFS-drive (`F:\STING`), `STING.PRG`/`STING.INF` in `C:\AUTO`.

| Test | Resultaat |
|---|---|
| Laden | adapter gevonden (sub 8), NET_INFO ok, poort ACSI2TNFS geïnstalleerd |
| Poort actief in STNGPORT.CPX (192.168.178.50/24) | NET_CTRL → Pico: bridge on, filter, performance-mode |
| Pollen vanuit de STinG-thread | duizenden NET_RX-polls, 0 fouten |
| Kopiëren met actieve poort: `C:\AUTO` en `F:\GAMES` naar `F:\WRITE` | alles identiek (16/16 + AUTO); 361 reads, 127 writes, 0 fouten; syncs van 42 s en 28 s ondertussen |
| Crystal Castles starten | drie bommen met STinG + XControl geladen, ook met de poort uit én zonder `ACSI_NET.STX`; zonder STinG/XControl start het. Oorzaak dus STinG/XControl (geheugen of vectoren), niet ACSI_NET |

Opgevallen: STinG roept de receive-routine vaker aan dan verwacht (~80–150×/s in plaats van 20×/s bij THREADING 10). Elke lege poll kost ~0,75 ms. Uitzoeken in fase 4.

## ACSI_NET fase 4: testverslag (4 oktober 2026) - eerste PING

`ACSI_NET.STX` 00.04 (5 KB): ARP-cache, ARP-antwoorden, ARP-vragen voor de next hop (hooguit 1×/s per adres, wachtrij tot het antwoord), IP-datagrammen ↔ Ethernet-frames, maximaal 4 frames in en 4 datagrammen uit per STinG-aanroep.

| Test | Resultaat |
|---|---|
| Laptop pingt de Atari (192.168.178.50) | 10/10 antwoorden, 66–102 ms (eerste 446 ms incl. ARP); ARP-tabel laptop: .50 en .103 beide `2c:cf:67:c8:e6:ba` |
| PING.PRG op de Atari naar de router (192.168.178.1) | 50 verzonden, 50 ontvangen, 0 verloren |
| Pico-teller | 63 frames naar de Atari, 63 verstuurd; 0 gedropt, 0 BUSY, 0 geweigerd, 0 zendfouten |
| Diskverkeer in de tussentijd | 119 reads, 0 fouten |

Let op: `THREADING` in STinGs `DEFAULT.CFG` is in **milliseconden** (STinG deelt door 5). 50 = elke 50 ms pollen (standaard); 10 gaf ~100 polls/s (de "te vaak pollen" uit fase 3). Een lege poll kost ~0,75 ms, bij 50 ms dus ~1,5 % CPU.

Bekende beperking: de Atari kan het eigen IP van de Pico (192.168.178.103) niet pingen; de brug laat zulke frames bewust vallen (zie ontwerp, risico 6). PING.PRG gebruikt standaard 127.0.0.1 (loopback in STinG zelf).

## ACSI_NET fase 5: testverslag (5 oktober 2026) - UDP, TCP, DNS

Client: gapFTP 0.88 (17 KB TTP, commandoregel, STinG). Server: Python `pyftpdlib` op de laptop (poort 2121).

| Test | Resultaat |
|---|---|
| FTP naar de laptop, download naar F: (TNFS) | HELLO.TXT, BIG.BIN (300 KB, 12 s), MEG.BIN (1 MB, 43 s): **alle drie identiek**; ~24 KB/s; ondertussen 954 reads en 2095 writes zonder fout, TNFS-syncs liepen ertussendoor |
| `open ftp.funet.fi` (DNS via de router, internet) | werkt |
| Download BIG.BIN naar C: | 27–30 s (~11 KB/s), identiek |
| Pico-tellers over alle tests | 0 frames gedropt, 0 BUSY, 0 zendfouten |

Wat er misging en waarom (geen netwerkfout):
- Eerste download naar C: liep vast: C: was vol. MEG.BIN (1 MB) paste niet; na de reset bleven ~700 KB aan **verloren clusters** in de FAT staan (bestand nooit gesloten), zodat ook na weggooien 0 bytes vrij bleef en gapFTP bij het eerste stuk data bleef hangen (TCP-venster dicht). Opgelost met console `F` (C: opnieuw) en de backup terugzetten.
- Naar C: is de helft zo snel als naar F:: gapFTP schrijft per 512 bytes, en elke schrijfopdracht naar C: kost een volledige flash-wis van 4 KB (~42 ms). Ook onnodige slijtage.

Verbeterpunten (los van ACSI_NET):
1. Console-commando "C: controleren": verloren clusters vinden en (na bevestiging) vrijgeven, zoals CHKDSK.
2. Schrijven naar C: bufferen: meerdere writes naar hetzelfde 4 KB-blok samen wegschrijven.

## Nog testen: ACSI2SD achter de adapter (doorlusconnector)

De dev-print heeft twee 20-polige connectoren die alle signalen doorverbinden, zoals bij Lotharek's ACSI2SD. Een tweede apparaat hangt dan gewoon parallel op de bus, met een eigen ACSI-ID. Nog niet getest: de ACSI2SD is hier niet aanwezig.

Wat er al voor gedaan is:

- **Bootdrive:** TOS voert de bootsector van elk ACSI-ID uit, van 0 naar 7 (`dmaboot` in `bios/startup.S` van TOS 1.x). Staat de ACSI2SD op een lager ID dan wij, dan heeft zijn driver C: al genomen. Onze driver zet de bootdrive (en de reset-hook) nu alleen nog als onze flash-disk C: krijgt; anders blijft de bootdrive van de andere driver staan. Zonder ACSI2SD getest: de ST start van onze C: zoals voorheen.

Testplan als de ACSI2SD er is:

1. **Pull-up op GP6 eerst** (zie hierboven): anders drijft U1 tijdens reset of BOOTSEL van de Pico de bus, ook voor de ACSI2SD.
2. ACSI2SD op ID 0, wij op 6. Koude start: de ACSI2SD krijgt C: en de ST start daarvan; onze drives krijgen de volgende vrije letters ("[OK] Drives installed: ...").
3. **Dubbel aankoppelen nagaan:**
   - HDDRIVER scant alleen de ID's die in HDDRUTIL aanstaan; ID 6 daar uitzetten.
   - AHDI scant alle ID's en koppelt onze partities dan ook aan, naast onze driver. Dezelfde schijf onder twee letters gaat bij schrijven mis. Oplossing (nog te bouwen): onze driver kijkt via `pun_ptr` of onze partities al aangekoppeld zijn en slaat ze dan over. Tot die tijd: verborgen modus (`H`) of HDDRIVER.
4. Lezen en schrijven op beide apparaten door elkaar, en een Pico-flash terwijl de Atari van de ACSI2SD leest (controle van de pull-up).
5. Kabellengte: de hele keten kort houden; bij haperingen eerst daar kijken.

## Eerst nagaan (voor optie 3: virtuele FAT)

Twee dingen moeten op de echte hardware bevestigd worden voordat hierop gebouwd wordt:

1. **Scant AHDI op de Mega STE ook andere ID's dan 0?** Verwacht: ja, maar niet getest. Test met de sniffer-modus: aanzetten en kijken naar welke ID's AHDI commando's stuurt.
2. **Scant HDDRIVER het ID van de Pico?** HDDRIVER scant alleen de ID's die in de HDDRUTIL-instellingen aanstaan. Het ID van de Pico moet daar dus bij staan.

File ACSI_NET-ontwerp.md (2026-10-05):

# ACSI_NET – STinG-netwerk via ACSI2TNFS (onderzoek en ontwerp)

Status: onderzoek en ontwerp, nog geen code. Datum: 4 oktober 2026.

Doel: een STinG-netwerkinterface via de ACSI-poort, als uitbreiding naast de bestaande disk- en TNFS-functie. Eerste mijlpaal: **PING vanaf een gewone ST via STinG → ACSI_NET.STX → ACSI2TNFS → Wi-Fi.**

```text
Atari-applicatie (PING, Litchi, CAB, ...)
  ↓
STinG (IP, ICMP, UDP, TCP, DNS)
  ↓
ACSI_NET.STX   ← nieuw: Ethernet-frames + ARP, praat ACSI
  ↓  vendor-commando's 0x11 'A' 'T' 0x2x
ACSI2TNFS firmware (core1: ACSI, core0: Wi-Fi/lwIP)   ← nieuw: frame-brug
  ↓
Wi-Fi (CYW43) → LAN / internet
```

Kernbeslissingen in één oogopslag:

1. **Frames, geen sockets.** De Pico doet geen TCP/IP namens de Atari. Hij brugt Ethernet-frames, net als PicoWifi. STinG doet IP, TCP en UDP, en de STX doet ARP, net als bij usbsting en EtherNEA.
2. **Eén MAC, twee IP's.** De Atari gebruikt het MAC-adres van de Pico. De Pico verdeelt binnenkomende frames op IP-adres: frames voor het IP van de Atari gaan naar de Atari, de rest naar lwIP (TNFS, NTP, DHCP).
3. **Transport via het bestaande vendor-commando** `[0x11|id<<5, 'A', 'T', sub, arg, 0]` met nieuwe subs 0x20–0x23. De disk-commando's veranderen niet.
4. **Core1 wacht nooit op core0.** Er komen wachtrijen voor RX en TX. Netwerkcommando's zijn even snel als de bestaande vendor-commando's (~0,5–1,5 ms) en raken het diskpad niet.
5. **De STX polt vanuit de STinG-thread en neemt de bus alleen met `tas flock`.** Is de bus bezet, dan slaat hij die beurt over, net als EtherNEA.

---

## A. Bevindingen over de huidige ACSI2TNFS-code

### A.1 Indeling over de cores

| Waar | Wat | Bestand |
|---|---|---|
| core1 | Realtime ACSI-target: commando ontvangen, uitvoeren, DMA, status | `acsi_core1.c`, `acsi_bus.pio` |
| core0 | USB-console, instellingen, Wi-Fi, lwIP, TNFS, NTP, configuratie-RPC, sysfiles | `acsi2tnfs.c`, `net.c`, `config.c`, `sysfiles.c` |
| Atari | Bootsector, residente driver (hdv_bpb/rw/mediach), ACSITNFS.PRG | `atari/boot.s`, `atari/driver.s`, `atari/acsi.inc` |

lwIP draait als `pico_cyw43_arch_lwip_threadsafe_background`. De cyw43-driver en lwIP worden dus vanuit een async context (IRQ-gestuurd, op core0) bediend, los van de hoofdlus van core0.

### A.2 Afhandeling van ACSI-commando's (core1)

- `target_loop` wacht op /CS met A1=0 (eerste commandobyte) en filtert op het eigen ID. In verborgen modus (`g_cfg.hidden`) en bij `mute_until_reset` gaat **alleen opcode 0x11** door. Netwerkcommando's als 0x11-sub werken dus ook als de adapter verborgen is.
- `handle_command` leest de CDB (6 bytes; ICD-uitgebreid 0x1F → 10/12 bytes). Na elke byte volgt /IRQ, dan `exec_cmd()`, dan `status_phase()`.
- `exec_cmd` verdeelt per opcode: TEST UNIT READY, REQUEST SENSE, INQUIRY, MODE SENSE/SELECT, READ CAPACITY, READ/WRITE(6) en (ICD) READ/WRITE(10), en **0x11 vendor**:

| sub | Richting | Inhoud |
|---|---|---|
| 5 | Atari → Pico, 512 B | configuratieverzoek (ACSITNFS.PRG) |
| 6 | Pico → Atari, 512 B | configuratieantwoord |
| 8 | Pico → Atari, 512 B | `ATL` gewenste driveletters |
| 9 | Pico → Atari, 512 B | `ATC` netwerktijd |
| 10 | Pico → Atari, 512 B | `ATG` media-change-tellers |
| anders | – | status 0x02, sense "invalid command" |

  Een onbekende sub geeft dus netjes CHECK CONDITION. Daarop rust de achterwaartse compatibiliteit (zie D.6).
- **DMA naar de Atari:** `dma_out2(a, alen, b, blen)` stroomt één of twee buffers zonder gat via RP-DMA naar de DOUT-statemachine. Dat is nodig vanwege de trage /DRQ (BC547) en de "volgende byte"-timing, gefikst met 50 ns hold.
- **DMA van de Atari:** `dma_in(buf, len)` start eerst RP-DMA en dan de DIN-SM. De hele overdracht gaat naar RAM.
- **Buffers:** `wbuf` (256 sectoren = 128 KB, voor disk-I/O), `reply[1024]` (vendor- en kleine antwoorden), `rxcopy`.
- **Logging:** elk commando gaat naar `g_cmd_log`. Met `verbose` gaat er ook een regel naar de console. Bij 20 netwerkpolls per seconde zou dat de console overspoelen; zie E.
- **TNFS-lezen en -schrijven** gaan nu via een handshake: core1 zet `vreq_*`, core0 (`net_poll`) doet het netwerkwerk, core1 wacht maximaal 9 s. Netwerkframes moeten **niet** op deze manier, anders wacht core1 op core0, die misschien seconden in een TNFS-sync zit.

### A.3 Netwerk op de Pico (core0)

- `net.c`: Wi-Fi-join (`wifi_connect`), DHCP of statisch, DNS, NTP via een eigen UDP-pcb, TNFS via eigen UDP/TCP-pcb's. De TNFS-requests lopen synchroon in de hoofdlus met `sleep_ms`-polls.
- Het CYW43-MAC is het enige MAC dat de Pico als Wi-Fi-station mag gebruiken (zie B.2).
- lwIP-opties (`lwipopts.h`): `MEM_SIZE 8000`, `PBUF_POOL_SIZE 24`, `LWIP_RAW 1`.
- **RAM:** ~432 KB van de 520 KB in gebruik. Grote debugbuffers: `la_buf` 32 KB, `ackcap` 33 KB, `ev_buf` 32 KB. Ruimte voor netwerkwachtrijen is er (~18 KB nodig), en die debugbuffers kunnen later kleiner.

### A.4 Atari-kant

- `atari/acsi.inc` `acsi_cmd`: zet `flock` (`st`), programmeert de DMA, stuurt 6 CDB-bytes met /IRQ-wacht (100 ms per byte, 10 s na de laatste) en leest de status. Daarna DMA-mode `$80` en `flock` vrij. Draait in supervisor-modus en gebruikt `_hz_200` voor timeouts.
- `driver.s` gebruikt dit voor disk-I/O en voor sub 8/9/10. `flock` wordt dus netjes gezet tijdens elk ACSI-commando. Precies wat een netwerkdriver nodig heeft om de bus veilig te delen.

---

## B. Bevindingen uit de referentieprojecten

### B.1 STinG 1.26 (th-otto/STinG)

- **Portdrivers werken op IP-niveau.** STinG zet uitgaande `IP_DGRAM`'s in `port->send` en roept `driver->send(port)` aan. De driver zet ontvangen datagrammen in `port->receive` (via `KRmalloc`). Een Ethernet-driver moet zelf **ARP** en de Ethernet-header doen. `IP_DGRAM` levert `hdr`, `options` en `pkt_data` los aan, plus `ip_gateway` (next hop).
- **Polling vanuit een interrupt.** `my_200_Hz` (`sting/thread.s`) telt `fraction` ticks af (standaard 10 → **elke 50 ms**; DEFAULT.CFG `THREADING` in milliseconden, STinG deelt door 5). Daarna draait `poll_ports` **in supervisor-modus, op het interruptniveau van de onderbroken code**, en alleen als die onder IPL 4 zat. `poll_ports` roept per poort `driver->receive` en daarna het verzenden aan. Gevolgen:
  - De STX kan midden in een diskcommando van GEMDOS terechtkomen. Hij **moet** `flock` controleren.
  - Tijdens de poll loopt `_hz_200` door (Timer C, IPL 6), dus timeouts op `_hz_200` werken.
  - Elke milliseconde in de poll is CPU-tijd die de voorgrond mist. Werk per poll begrenzen.
- Er is geen DHCP. IP, masker, gateway (ROUTE.TAB) en DNS stel je zelf in (STNGPORT.CPX, STNGPROT.CPX).

### B.2 PicoWifi (czietz/picowifi) – Pico-kant

- **Geen lwIP op de Pico.** De firmware overschrijft `cyw43_cb_process_ethernet` en zet elk binnenkomend frame in een wachtrij naar USB (16 × 1600 B). Uitgaande frames gaan rechtstreeks via `cyw43_send_ethernet()`.
- **De Atari gebruikt het MAC-adres van de Pico** (doorgegeven als USB-serienummer). Een Wi-Fi-station kan geen vreemde MAC's versturen (3-adresmodus). MAC-delen is dus de enige brug zonder NAT, en het werkt.
- `cyw43_wifi_pm(CYW43_PERFORMANCE_PM)`: geen energiebesparing, dus lage latentie. Dat is belangrijk voor ping en TCP.
- Wachtrijen tussen de cores met `pico/util/queue`; frame-overloop wordt stil gedropt.
- **Verschil met ons:** bij PicoWifi is de Atari de enige IP-gebruiker van het MAC. Bij ons heeft de Pico zelf ook een IP (TNFS/NTP). Daarom is er een **IP-filter** nodig (C.3).

### B.3 USBSTinG (czietz/usbsting, `USB_NET.STX`) – Atari-kant

- Een nette, moderne Ethernet-portdriver in C (m68k-atari-mint-gcc, `-mshort`, `-nostartfiles`). Hij stamt af van Roger Burrows' SCSILINK-driver (DaynaPort). **GPL-2 of later.**
- **Lagen:** `usbsting.c` (STinG-koppeling, `send_dgrams`/`receive_dgrams`, ARP, opbouw van `IP_DGRAM`) + `arpcache.c`. Alle hardware zit achter **twee functies**: `write_device(buf, len)` en `read_device(ENET_PACKET*)`. Dat is precies het punt waar ACSI in kan.
- `send_dgrams`: bouwt per datagram een volledig Ethernet-frame in een statische buffer (`ENET_PACKET op`) en verstuurt. Zonder ARP-antwoord komt het datagram in een `arpwait`-rij.
- `receive_dgrams`: `while (read_device() > 0)`, dan IP → `process_ip` (KRmalloc + kopie), ARP → `process_arp`. IP-broadcastframes worden genegeerd.
- Grootte: `USB_NET.STX` ≈ 12,7 KB.
- Let op: `allocmem` gebruikt `Mxalloc(…, 3)` (bij voorkeur TT-RAM). Voor ACSI-DMA moet het **ST-RAM** zijn (modus 0).

### B.4 EtherNEA / EtherNEC (Thomas Redelberger)

- Een NE2000 aan de ACSI-bus, maar **zonder DMA**: registertoegang via losse ACSI-bytes. Ook polling, ook vanuit de STinG-thread.
- **Busarbitrage (BUSENEAF.I):** `tas flock` en `tas flock+1`; is de bus bezet, dan **doet de driver deze beurt niets** en probeert het bij de volgende poll opnieuw. Na afloop `clr.w flock` en DMA-mode `$80`. Het advies uit ARCHITEC.TXT geldt ook voor ons: de harddiskdriver moet `flock` netjes gebruiken, anders dreigt dataverlies.
- Geen interrupt: de MFP-ingang voor ACSI-/IRQ is flankgevoelig en wordt gedeeld met de disk, dus interrupts zijn onpraktisch. Polling is de juiste keus.
- Over DMA: "transfers in veelvouden van 512 bytes (512/1024/1536)". Dat bevestigt de keuze voor 3 sectoren per frame. Bij STinG is dubbel bufferen nodig, omdat het datagram niet aaneengesloten is (header, options en data los).
- ARP in de STX (`ENESTNG.C`), cache van 32 entries; dezelfde opzet als bij usbsting.
- ENEAF.STX ≈ 6 KB (assembler). Een C-STX op basis van usbsting wordt ~10–12 KB.

### B.5 DaynaPort SCSI/Link (commandoset)

- Read(08): het antwoord begint met **lengte (2 B) + vlag (4 B, "meer pakketten")**, daarna het frame. Write(0A): één frame. Aparte commando's voor MAC, statistieken en aan/uit.
- Dit model nemen we over: **één frame per commando, met een "er wacht nog meer"-teller in de header**, zodat de driver in één poll kan doorlezen.

### B.6 Nieuwere TCP.STX en de 1040STf

- PicoWifi raadt het bijgewerkte `TCP.STX` van chzsoft aan (compatibiliteitsprobleem met sommige hosts). Dat geldt voor ons net zo.
- Op een 1 MB 1040STf werkt STinG 1.26 als je ongebruikte STX'en weglaat en `ALLOCMEM` verlaagt (50–60 KB). Onze STX kost ~12 KB code + ~4 KB buffers, en dat past.

---

## C. Voorgestelde architectuur

### C.1 Vergelijking van de opties voor de Pico-kant

| Optie | Hoe | Plus | Min |
|---|---|---|---|
| **1. Frame-brug, gedeeld MAC, IP-filter** (voorstel) | Atari krijgt eigen IP op het Pico-MAC; Pico verdeelt frames op IP | Atari volwaardig in het LAN (inkomende verbindingen, FTP-server); STX = beproefd usbsting-model; Pico doet weinig | Twee IP's op één MAC; IP van de Atari vast instellen (later DHCP) |
| 2. NAT/router op de Pico | Atari in een virtueel subnet, Pico routeert/NAT | Geen IP in het LAN nodig | lwIP heeft geen NAT; inkomend verkeer vraagt portforwarding; veel code |
| 3. Socket-proxy (Pico doet TCP) | STX vertaalt STinG-calls naar Pico-sockets | Atari ontlast | Gaat tegen de eis in (STinG doet TCP/IP); grote, foutgevoelige laag |
| 4. IP-niveau (Pico doet ARP) | STX stuurt kale IP-datagrammen; Pico maakt Ethernet | Kleinere STX | Pico moet proxy-ARP en next-hop doen; afwijkend van alle referenties |

**Keuze: optie 1.** Die sluit aan bij PicoWifi (Pico) en usbsting/EtherNEA (Atari), en de Pico hoeft niets van TCP/IP te weten behalve een filter.

### C.2 Datastromen

```text
Wi-Fi RX:  CYW43 → cyw43_cb_process_ethernet → pbuf → netif->input
                                                         │
                                         net_input_filter (nieuw)
                         ┌───────────────┬───────────────┴──────────────┐
                    voor Atari      voor beide (ARP-reply,        voor Pico
                         │           ARP-broadcast?)                    │
                  RX-ring (core0 → core1)                       ethernet_input (lwIP)
                         │
            core1: NET_RX → DMA → Atari → ACSI_NET.STX → STinG

Atari TX:  STinG → ACSI_NET.STX → NET_TX → core1: DMA in → TX-ring (core1 → core0)
                         │
          async-worker op core0 (lwIP-context) → cyw43_send_ethernet()
```

### C.3 Filterregels (Pico, `net_input_filter`)

Alleen actief als de Atari het netwerk heeft aangezet (NET_CTRL enable, met zijn IP). Anders gaat alles ongewijzigd naar lwIP: **zonder STX is er geen gedragsverandering.**

| Binnenkomend frame | Naar |
|---|---|
| IPv4, doel-IP = IP van de Atari | Atari |
| ARP, doel-IP (TPA) = IP van de Atari | Atari |
| ARP-reply aan ons MAC, TPA = IP van de Pico | lwIP |
| ARP-request (broadcast) voor een ander IP | lwIP (de Atari hoeft dat niet te weten) |
| IPv4-broadcast/multicast | lwIP (usbsting negeert IP-broadcast toch) |
| Overig (IPv6, …) | lwIP |

**Uitgaand van de Atari:** het bron-MAC moet ons MAC zijn (de Pico controleert dat). Frames naar het **eigen IP van de Pico** kunnen niet via Wi-Fi terugkomen. In fase 1 worden ze genegeerd; later eventueel via een lokale lus naar lwIP (zie E).

### C.4 Pico: wachtrijen en threads

- **RX-ring** (core0 vult, core1 leegt): 8 × 1536 B = 12 KB, lock-free single-producer/single-consumer met geheugenbarrières. Vol → frame droppen, teller ophogen.
- **TX-ring** (core1 vult, core0 leegt): 4 × 1536 B = 6 KB. Vol → NET_TX geeft status BUSY (0x08), de STX houdt het datagram vast.
- **TX-verzending** door een `async_when_pending_worker` in de cyw43-async context: core1 roept `async_context_set_work_pending()` aan. De worker draait in de lwIP/cyw43-context (lock wordt vastgehouden) en roept `cyw43_send_ethernet()`. Daardoor gaat TX ook door als de hoofdlus van core0 seconden in een TNFS-sync zit.
- **core1** handelt NET_RX/NET_TX volledig zelf af: geen `vreq`-handshake, geen wachten op core0. De duur van het commando is alleen de ACSI-overdracht.
- **Bij /RESET** (bestaande handler op core1): netwerkbrug uit, ringen leeg. De Atari is weg, dus frames voor zijn IP worden niet meer opgespaard; lwIP krijgt weer alles.
- `cyw43_wifi_pm(CYW43_PERFORMANCE_PM)` zodra de brug aanstaat (of altijd), voor lage latentie.

### C.5 Atari: ACSI_NET.STX

- Gebaseerd op **usbsting** (`usbsting.c`, `arpcache.c`, STinG-headers), met de USB-laag vervangen door `acsinet.c` / `acsinet.S`:
  - `write_device(buf,len)` → NET_TX
  - `read_device(pkt)` → NET_RX
  - `open_device` → NET_INFO + NET_CTRL enable (IP en masker van de poort)
  - `close_device` → NET_CTRL disable
- **Busarbitrage per poll:** `tas flock` (en `flock+1`, zoals EtherNEA). Bezet → deze poll niets doen. Na afloop DMA-mode `$80` en `flock` vrij, net als `acsi_cmd`.
- **Werk per poll begrensd:** maximaal bijvoorbeeld 4 frames RX en 4 TX, en stoppen als de pending-teller 0 is.
- **Korte timeouts** (bijv. 20 ms per commandobyte, 100 ms totaal). Bij een timeout: poort-statistiek ophogen, deze poll stoppen, `flock` vrijgeven.
- **Buffers in ST-RAM** (`Mxalloc(…, 0)`, of BSS op een ST): TX-frame 1536 B, RX-frame 1536 B, op een even adres.
- MAC = MAC van de Pico (uit NET_INFO). `CTL_ETHER_SET_MAC` wordt geweigerd.
- Poortnaam bijvoorbeeld **"ACSI2TNFS"**. Detectie: zoek het ACSI-ID via de `_bootdev`/driver-data of probeer ID 0–7 met NET_INFO.

---

## D. Voorgesteld ACSI-netwerkprotocol (versie 1)

### D.1 Waarom het bestaande vendor-commando

- Opcode 0x11 met `'A' 'T'` is al ons herkenbare "protocol-ID". Het komt door de verborgen modus heen, en een onbekende sub geeft netjes CHECK CONDITION.
- De disk-opcodes (READ/WRITE(6/10)) blijven onaangeroerd: geen kans dat een netwerkframe als sector wordt gezien.
- Een uitgebreid ICD-commando (0x1F) is niet nodig: 6 bytes CDB is genoeg, en niet elke host-DMA-routine kan ICD.
- Versie en capabilities staan in het NET_INFO-antwoord (magic `ATN` + versie). Zo kunnen STX en firmware los van elkaar evolueren.

### D.2 CDB

```text
byte 0: 0x11 | (id << 5)
byte 1: 'A'
byte 2: 'T'
byte 3: sub            0x20..0x2F = netwerk
byte 4: arg            aantal sectoren (TX), maximum aantal sectoren (RX)
byte 5: 0              (gereserveerd, later vlaggen)
```

### D.3 Commando's

| sub | Naam | Richting, sectoren | Inhoud |
|---|---|---|---|
| 0x20 | NET_INFO | Pico → Atari, 1 | `"ATN"`, protocolversie (1), capabilities, toestand (Wi-Fi, brug aan), MAC[6], IP Pico, IP/masker van de Atari (zoals ingesteld), MTU (1500), maximaal aantal sectoren RX/TX, ringgroottes, tellers (rx/tx/drop), firmwareversie-string |
| 0x21 | NET_CTRL | Atari → Pico, 1 | `"ATN"`, versie, opdracht: 1 = brug aan (IP, masker), 0 = uit. Status 0 = ok; 0x02 + sense bij een fout (bijv. IP gelijk aan dat van de Pico, geen Wi-Fi) |
| 0x22 | NET_TX | Atari → Pico, `arg` = 1..3 | Header + frame (D.4). Status 0 = aangenomen, **0x08 BUSY** = TX-ring vol (later opnieuw), 0x02 = fout (lengte) |
| 0x23 | NET_RX | Pico → Atari, `arg` = maximum (3) | Header + 0 of 1 frame. **De Pico stuurt zo weinig sectoren als nodig:** 1 als er niets is, anders ⌈(8+len)/512⌉ |

### D.4 Frameformaat (in de DMA-buffer, big-endian zoals de 68000)

```text
offset 0  u16  frame_len       0 = geen frame (alleen bij RX)
offset 2  u16  pending         RX: frames die daarna nog wachten; TX: 0
offset 4  u16  dropped         RX: teller (laagste 16 bits) gedropte frames
offset 6  u16  flags           0 (gereserveerd: checksum, batch)
offset 8  ..   Ethernet-frame  dest MAC, src MAC, type, payload (zonder FCS)
```

8 + 1514 = 1522 B past in **3 sectoren (1536 B)**. De rest van de laatste sector is opvulling. Altijd hele sectoren: de DMA-chip van de ST werkt met een FIFO van 16 bytes, dus een halve sector kan in de FIFO blijven hangen.

### D.5 Ruimte voor later (capabilities)

- **Batching:** meerdere kleine frames (ARP, TCP-ACK) in één NET_RX/NET_TX van 1–N sectoren. Header per frame, een `nframes`-veld in `flags`. Dat scheelt commando-overhead bij veel kleine pakketten.
- **Checksum** over header en frame (16 bit) als vlag. IP/ICMP/UDP/TCP hebben al end-to-end-checksums, dus voor fase 1 niet nodig.
- **DHCP namens de Atari** (NET_INFO levert dan IP, masker, gateway en DNS).

### D.6 Achterwaartse compatibiliteit

| Combinatie | Gedrag |
|---|---|
| Nieuwe firmware, geen STX | Brug staat uit; filter geeft alles aan lwIP; er verandert niets |
| Nieuwe firmware, oude driver/ACSITNFS.PRG | Die kennen sub 0x2x niet en gebruiken ze ook niet; er verandert niets |
| Oude firmware, nieuwe STX | NET_INFO → status 0x02 → STX meldt "ACSI2TNFS zonder netwerkfunctie" en installeert zich niet |
| Andere protocolversie | STX controleert versie en capabilities in NET_INFO; onbekende hogere versie: alleen v1-functies gebruiken |

---

## E. Risico's en mogelijke problemen

| # | Risico | Gevolg | Aanpak |
|---|---|---|---|
| 1 | **flock-discipline van andere drivers** | Een driver die `flock` niet zet, kan midden in een STX-poll de DMA overnemen → corrupte disk-I/O | Onze driver, AHDI en HDDRIVER zetten `flock`. Documenteren (zoals EtherNEA). STX alleen met `tas` |
| 2 | **Poll in interruptcontext** | Lange ACSI-commando's houden de voorgrond vast | Werk per poll begrenzen; korte timeouts; geen BIOS/GEMDOS in de poll |
| 3 | **Korte DMA-read** (1 sector sturen terwijl de Atari er 3 programmeerde) | Werkt naar verwachting (hele sectoren, status beëindigt), maar **nog niet getest** | Als eerste testen in fase 1. Valt het tegen: NET_RX altijd 3 sectoren, of eerst een statusvraag |
| 4 | **Twee IP's op één MAC** | Sommige routers/AP's (ARP-spoofing-bescherming, mesh, client isolation) vinden dat raar | Gebruikelijke en legitieme situatie (IP-aliassen). Testen op het eigen netwerk; documenteren |
| 5 | **DHCP voor de Atari** | STinG heeft geen DHCP; IP handmatig, conflict met het DHCP-bereik mogelijk | Fase 1: vast IP buiten het DHCP-bereik. Later: Pico vraagt een lease aan met een eigen client-ID |
| 6 | **Atari → IP van de Pico** | Komt niet terug via Wi-Fi | Fase 1: niet ondersteund (gedocumenteerd). Later: lokale lus in het filter |
| 7 | **Wi-Fi-energiebesparing** | Ping-RTT 100+ ms, trage TCP | `CYW43_PERFORMANCE_PM` |
| 8 | **Console-logging** | 20 polls/s overspoelen USB en `ev_buf` | Net-subs niet loggen in verbose; aparte teller en console-toets voor netstatistiek |
| 9 | **RAM op de Pico** | ~88 KB vrij; ringen ~18 KB | Past. Eventueel `la_buf`/`ackcap`/`ev_buf` verkleinen (stond al op de lijst) |
| 10 | **TNFS-verkeer en netwerk tegelijk** | Wi-Fi-airtime wordt gedeeld; een TNFS-sync blokkeert de hoofdlus van core0 | RX/TX via de async context, los van de hoofdlus. Netwerkthroughput daalt tijdens een grote sync, maar loopt niet vast |
| 11 | **ACSI-datafouten** | Geen FCS over ACSI | IP-/ICMP-/UDP-/TCP-checksums vangen het op; later optionele checksum (D.5) |
| 12 | **TT (68030-cache, TT-RAM)** | DMA-buffer in TT-RAM onmogelijk; verouderde cache na DMA-read | Buffers met `Mxalloc(…, 0)`; op de TT cache leegmaken na NET_RX. Doel is eerst de gewone ST |
| 13 | **Licentie** | usbsting en EtherNEA zijn GPL | ACSI_NET.STX als GPL-2+-programma (eigen map, eigen LICENSE). De firmware blijft los |
| 14 | **TCP.STX-bug** | Sommige servers geven problemen | Bijgewerkte TCP.STX van chzsoft aanbevelen |
| 15 | **Atari-reset met STinG actief** | Ringen houden oude frames | Brug uit en ringen leeg bij /RESET (core1) |

Throughput, ruwe schatting: een NET_RX/NET_TX van 3 sectoren kost ~1,2–1,5 ms ACSI (gemeten: 4 KB in 2,8 ms). Het plafond is ruim 500 KB/s, maar in de praktijk begrenst STinG op een 8 MHz 68000 het tot enkele tientallen KB/s, en de pollinterval (50 ms standaard, 10 ms met THREADING = 10) bepaalt de latentie. Elke lege poll kost ~0,5 ms, dus ~1 % CPU bij 50 ms.

---

## F. Gefaseerd implementatieplan

Aangepast ten opzichte van het voorstel: RX en TX worden samen getest (een frame versturen zonder iets terug te ontvangen is lastig te controleren), en er komt een klein testprogramma **vóór** STinG, zodat transportproblemen niet verward raken met STinG-configuratie.

| Fase | Inhoud | Klaar als |
|---|---|---|
| **1. Transport en detectie** | Firmware: NET_INFO + NET_CTRL (alleen opslaan, nog geen filter), netstatistiek op de console, net-subs niet in verbose. Atari: `NETTEST.TTP` (C, m68k-atari-mint-gcc) die het adapter-ID vindt, NET_INFO toont en de korte DMA-read test (risico 3) | NETTEST toont MAC, IP van de Pico en versie; oude firmware geeft een nette melding |
| **2. Frame-brug op de Pico** | Filter in `netif->input`, RX- en TX-ring, async-worker voor TX, NET_TX/NET_RX op core1, reset-afhandeling, `PERFORMANCE_PM`. NETTEST: ARP-request naar de router sturen en het ARP-antwoord ontvangen; een ARP-request van de laptop (`arping`) zien binnenkomen | ARP heen en terug; TNFS-drives werken ongestoord (kopieertest zoals eerder) |
| **3. ACSI_NET.STX-skelet** | usbsting-structuur overnemen, USB eruit, `acsinet.S` (ACSI met `tas flock`, korte timeouts), installeren in STinG, poort "ACSI2TNFS" zichtbaar in STNGPORT.CPX, aan/uit → NET_CTRL | Poort zichtbaar en activeerbaar; geen invloed op disk-I/O (kopiëren tijdens actieve STinG) |
| **4. ARP en ICMP: eerste PING** | `send_dgrams`/`receive_dgrams` + ARP-cache actief; ROUTE.TAB | `ping <atari-ip>` vanaf de laptop werkt; PING.PRG op de Atari naar de router werkt |
| **5. UDP en TCP** | DNS via RESOLVE.STX, een FTP-client (Litchi) of CAB; bijgewerkte TCP.STX; stresstest met gelijktijdige disk- en TNFS-I/O | Bestand downloaden en tegelijk van C: en een TNFS-drive lezen zonder fouten |
| **6. Verfijning** | Batching (D.5), THREADING-advies, gebruik op een 1 MB 1040STf, IP van de Atari instellen via ACSITNFS.PRG of DHCP namens de Atari, ACSI_NET.STX als systeembestand, documentatie | Gebruiksklaar voor anderen |

Elke fase laat de bestaande functie intact: zonder actieve STX is alleen de netstatistiek op de console nieuw.

---

## G. Bestanden die er uiteindelijk bij komen of veranderen

### Firmware (Pico)

| Bestand | Wijziging |
|---|---|
| `netbridge.c` (nieuw) | RX/TX-ringen, `net_input_filter`, TX-worker, enable/disable, statistiek |
| `acsi_core1.c` | `case 0x20..0x23` in de bestaande `0x11`-switch; ring legen bij /RESET; net-subs niet in verbose-log |
| `net.c` | Na de Wi-Fi-join het filter installeren (`netif->input` omleiden), MAC/IP beschikbaar maken voor NET_INFO, eventueel `cyw43_wifi_pm` |
| `acsi.h` | Prototypes en statistiekstruct |
| `acsi2tnfs.c` | Console-toets voor netstatistiek (bijv. `w`) |
| `CMakeLists.txt` | `netbridge.c` toevoegen |
| `lwipopts.h` | Waarschijnlijk niets; eventueel `PBUF_POOL_SIZE` |
| `config.c` | Pas in fase 6: IP van de Atari instelbaar via ACSITNFS.PRG |

### Atari

| Bestand | Inhoud |
|---|---|
| `atari/sting/` (nieuw, GPL-2+) | `acsi_net.c` (op basis van `usbsting.c`), `arpcache.c/.h` (usbsting), `acsinet.S` (ACSI-commando met `tas flock`, afgeleid van `atari/acsi.inc`), `include/port.h`, `include/transprt.h`, `Makefile` (m68k-atari-mint-gcc `-mshort`), `LICENSE` |
| `atari/tools/nettest.c` (nieuw) | Testprogramma voor fase 1–2 |
| `atari/files/` | Later `ACSI_NET.STX` als systeembestand op C: (fase 6) |
| `atari/driver.s`, `atari/acsi.inc` | Geen wijziging nodig: zetten `flock` al |

### Documentatie

| Bestand | Wijziging |
|---|---|
| `README.md`, `atari/files/README.TXT` | Netwerkfunctie, STinG-installatie, ROUTE.TAB-voorbeeld, beperkingen |
| `project-notities.md` | Testresultaten per fase |
| Dit document | Bijwerken als ontwerpkeuzes veranderen |

---

## Referenties

- STinG 1.26: https://github.com/th-otto/STinG (`sting/thread.s`: 200 Hz-thread; `sting/kernel.c`: `poll_ports`)
- PicoWifi: https://github.com/czietz/picowifi (`picowifi.c`)
- USBSTinG: https://github.com/czietz/usbsting (`driver/usbsting.c`, `driver/arpcache.c`)
- EtherNEA/EtherNEC: https://web222.webclient5.de/prj/atari/etherne/index.htm (`SRC/ARCHITEC.TXT`, `SRC/ENESTNG.C`, `SRC/BUSENEAF.I`)
- DaynaPort SCSI/Link: https://github.com/piscsi/piscsi/wiki/Dayna-Port-Command-Set
- Bijgewerkte TCP.STX: https://www.chzsoft.de/storage/TCP.STX
- STinG op een 1040STf: https://chebucto.ns.ca/Services/PDA/stfsting.txt

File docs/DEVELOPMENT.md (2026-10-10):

# Development

## Building

**Firmware:** Pico SDK 2.2.0, CMake and Ninja, board `pico2_w` (the tested board).

```text
cmake -G Ninja -B build-pico2w -DPICO_BOARD=pico2_w
ninja -C build-pico2w            # build-pico2w/acsi2tnfs.uf2
```

The version number lives in `version.txt` only. CMake passes it to the firmware, and
`ninja` runs `atari/mkdisk.py` whenever `version.txt`, an Atari source or a file in
`atari/files/` changes (after adding a file to `atari/files/`, run `cmake` once more).
`mkdisk.py` writes `atari/version.inc`, assembles the boot code and the driver with
[vasm](http://sun.hasenbraten.de/vasm/) (`vasmm68k_mot`, or set `VASM`) and writes the
disk image and `disk_seed.h`:

```text
cd atari
python mkdisk.py          # out/BOOT.BIN, DRV.BIN, disk.img, ../disk_seed.h
```

**Atari programs** (m68k-atari-mint-gcc, e.g. in WSL):

| | |
|---|---|
| `atari/sting/` | `make`: `ACSI_NET.STX` (STinG driver); `-mshort`, no C library |
| `atari/tools/` | `make`: `NETTEST.TTP`, the test tool for the network protocol |
| `ACSITNFS.PRG` | [SideTNFS-Config](https://github.com/RetroLoft/SideTNFS-Config), branch `acsi-transport`, `make acsi` |

Copy new builds of `ACSI_NET.STX` and `ACSITNFS.PRG` into `atari/files/`:
everything there becomes a read-only system file on C:.

## Repository layout

| Path | Contents |
|---|---|
| `acsi2tnfs.c` | core0: USB console, sniffer decoder, settings, disk seeding |
| `acsi_core1.c` | core1: real-time ACSI target, flash disk, command dispatch |
| `acsi_bus.pio` | PIO programs: /CS and /ACK capture, DMA in/out, logic analyser |
| `net.c` | Wi-Fi, NTP clock, TNFS drives (virtual FAT, writing and sync) |
| `netbridge.c` | network function for STinG: frame bridge between ACSI and Wi-Fi |
| `config.c` | configuration protocol for ACSITNFS.PRG |
| `sysfiles.c` | keeps the system files on C: up to date |
| `acsi.h`, `settings.h` | pin map, flash layout, shared types |
| `atari/` | boot code, resident driver (68000 assembler), `mkdisk.py`, `files/` for C: |
| `atari/sting/`, `atari/tools/` | STinG driver, NETTEST |
| `hardware/` | KiCad projects: `v2` (DB19 on the board), `v2-cable` (flat cable, pass-through); see its README |

## ACSI vendor commands

The adapter answers the standard commands (TEST UNIT READY, INQUIRY, READ/WRITE(6),
ICD READ/WRITE(10), …) and one vendor command:

```text
$11|id<<5, 'A', 'T', sub, arg, 0
```

| sub | Direction | |
|---|---|---|
| 5 / 6 | to / from the adapter, 512 bytes | configuration protocol (ACSITNFS.PRG) |
| 8 | from, 512 | drive letters for the driver (`ATL`) |
| 9 | from, 512 | network time (`ATC`) |
| 10 | from, 512 | media change counters (`ATG`) |
| `$20` NET_INFO | from, 512 | network function: version, MAC, IP addresses, counters (`ATN`) |
| `$21` NET_CTRL | to, 512 | bridge on (Atari IP and mask) / off |
| `$22` NET_TX | to, `arg` = 1–3 sectors | one Ethernet frame (8-byte header + frame); status 8 = busy |
| `$23` NET_RX | from, up to `arg` sectors | the next frame for the Atari; one sector when empty |
| `$2F` NET_TEST | from, `arg` sectors | test pattern (short DMA read test) |

An unknown sub gives CHECK CONDITION; that is how programs recognise older firmware. The
design of the network function, with the reasoning and the test reports, is in
`ACSI_NET-ontwerp.md` and `project-notities.md` (Dutch).

## Test and debug tools

- **NETTEST.TTP** (`atari/tools`): finds the adapter, `NET_INFO`, short DMA read test
  (`S`), bridge tests with ARP (`A`, `L`), read test of C: and a network drive (`R`).
  Writes everything also to `NETTEST.LOG` in its folder.
- **USB console:** `v` logs every command with a byte-by-byte /ACK cross-check on reads;
  `L`/`l` arm and dump the built-in PIO logic analyser (16 ns); `s` is a passive ACSI
  bus monitor (sniffer).

## Hardware notes

- The design rules for the boards (no pull-ups on /IRQ and /DRQ, pull-up on /OE, pull-ups
  on the 74LS07 inputs) are in [hardware/README.md](../hardware/README.md).
- The firmware still uses the pin map of the earlier development board (no longer in the
  repo: data on GP8-GP15, /OE GP6, DIR GP7, /IRQ and /DRQ through BC547s, high = active).
  Its BC547 releases /DRQ about 1 µs late; the firmware copes with it, `v2` and `v2-cable`
  use a 74LS07.
- Reads hold each byte about 130 ns after /ACK rises; with less the DMA chip now and then
  latched the next byte.

## References

- Atari ACSI/DMA Integration Guide, 28 June 1991
- P. Putnik, ACSI/DMA experiences: https://atari.8bitchip.info/AcsiDmaExD.html
- TOS 1.x source: https://github.com/th-otto/tos1x
- STinG source: https://github.com/th-otto/STinG

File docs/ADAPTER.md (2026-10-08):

# The adapter in detail

## ACSI id

Every device on the ACSI bus needs its own id (0–7); two devices on one id answer at the
same time and neither works. A new adapter uses **id 6**, as an internal Mega ST disk, a
Megafile or an UltraSatan usually sits on 0.

To change it:

- `ACSITNFS.PRG` → *Config → More → ACSI device ID*, then *Save* and restart.
- USB console: keys `0`–`7`. This always works, also during an id clash when the Atari
  cannot reach the adapter.

## Booting

The adapter's boot sector loads a small resident driver. It installs C: and the network
drives, sets the clock and makes C: the boot drive, so the AUTO folder and the desktop
come from C:.

- Another hard disk on a **lower** ACSI id boots first and keeps C: and the boot drive;
  the adapter's drives get the next free letters.
- **AHDI** scans every id and would also mount the adapter's partitions; use the adapter
  next to HDDRIVER with the adapter's id switched off in HDDRUTIL, or hide the adapter
  (below).
- **EmuTOS** mounts the partitions with its own ACSI driver as C:, D:, E:, …; the chosen
  letters and the network clock do not apply there.
- **TOS 1.0** does not see the adapter; TOS 1.02 and later do.

## USB console

Connect the Pico to a PC and open its serial port in a terminal program (any speed).

| Key | |
|---|---|
| `i` | information: mode, id, command counters |
| `n` / `N` | network status / reconnect and re-read the TNFS drives |
| `w` | Atari network (STinG bridge): state, IP address, frame counters |
| `0`–`7` | ACSI id |
| `H` | hide / show the adapter (see below) |
| `K` | network clock on / off |
| `R` | put the system files back on C: (also new ones after a firmware update) |
| `F` | write C: anew: **all your files on C: are lost** |
| `B` | restart the Pico in BOOTSEL mode (for a firmware update) |
| `v` | verbose: log every ACSI command |
| `s` / `t` | sniffer mode (passive bus monitor) / target mode (normal) |
| `h` | help |

After `R` or `F` the driver tells GEMDOS that C: changed; no Atari reset needed.

## Hidden mode

With `H` the adapter ignores everything except its own configuration commands until it is
switched on again. The Atari then boots as if there were no adapter (e.g. a game that
must boot from floppy, or another hard disk driver). `ACSITNFS.PRG` still works.

Without a PC: a short press on the Pico's **BOOTSEL** button switches hidden mode on or
off. While the adapter is hidden, the Pico's own led blinks slowly (once Wi-Fi has
started). The change counts from the next Atari reset: press the button, reset the
Atari, and the game on the floppy starts by itself.

## System files on C:

`README.TXT`, `ACSITNFS.PRG` and `ACSI_NET.STX` come with the firmware and are
read-only. A new firmware updates them at start-up and keeps every other file on C:.
A system file that was deleted, or one that is new in the firmware, comes on C: with `R`.

## Troubleshooting

| Symptom | What to do |
|---|---|
| Atari does not see the adapter | ACSI cable, Pico powered, id clash (console `0`–`7`), TOS 1.0 |
| *Disk not usable, driver not loaded* | Console `R`; if C: is damaged, back up and `F` |
| C: full although files were deleted | A reset during a write can leave lost clusters on C:. Copy your files elsewhere, `F`, copy them back |
| "use FOLDR100.PRG" / folders do not open | TOS 1.x: `FOLDR100.PRG` in `C:\AUTO` |
| Drive letter not as configured | Letters above P: are not possible; a taken letter gives the next free one |
| Clock not set | Network clock on (`K`, ACSITNFS.PRG), Wi-Fi connected; ESC skips the wait at start-up |
| Network drive shows only `NET_ERR.TXT` | The reason is in the file (Show). Fix it, then console `N` or restart |
| Network drive empty | Still connecting at start-up, or console `n`: server reachable? folder correct? |

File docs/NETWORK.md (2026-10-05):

# Internet on the Atari with STinG

The adapter's Pico is on your Wi-Fi network. With the STinG TCP/IP stack and the driver
`ACSI_NET.STX` the Atari gets its own IP address there: it can ping, use FTP, fetch web
pages and be reached from other computers.

```text
program (PING, gapFTP, CAB, ...)
  -> STinG (IP, TCP, UDP, DNS)
  -> ACSI_NET.STX (Ethernet frames, ARP)
  -> ACSI -> Pico -> Wi-Fi -> your router -> internet
```

The disk functions keep working at the same time: C: and the network drives.

## 1. What you need

| | Where |
|---|---|
| STinG 1.26 | [sting126.lzh](https://chebucto.ns.ca/Services/PDA/sting126.lzh) from the [Chebucto Atari page](https://chebucto.ns.ca/Services/PDA/AtariSTComm.shtml) |
| XControl 1.31 | [xctl131.zip](https://chebucto.ns.ca/Services/PDA/xctl131.zip) (same page) |
| `ACSI_NET.STX` | on drive C: of the adapter (read-only system file) |
| Firmware with the network function | 0.4.0 or later from the `acsi-net` branch |

`.lzh` archives can be unpacked on the Atari with LHarc, or on a PC with 7-Zip.

Older firmware: `ACSI_NET.STX` says *firmware without network function, not installed*
at start-up. After a firmware update the new files may be missing on C:: press `R` on
the USB console (see [ADAPTER.md](ADAPTER.md)).

## 2. Choose an IP address for the Atari

The Atari uses the **same MAC address as the Pico** but its **own IP address**. STinG has
no DHCP, so you pick one yourself:

- It must be **free**: no other device may use it.
- Take one **outside the range your router hands out** (DHCP). A FRITZ!Box hands out
  `.20`–`.200` by default, so for `192.168.178.x` pick e.g. `192.168.178.210`.
- Not the Pico's own address (the USB console shows it with `n`).

### The four addresses you need

| | What it is | Example | Where to find it |
|---|---|---|---|
| **Atari IP address** | the Atari's own address | `192.168.178.210` | you choose it (above) |
| **Subnet mask** | which part of an address says "same network" | `255.255.255.0` | PC: `ipconfig` (Windows) or the network settings, *Subnet Mask* |
| **Router** (gateway) | the way to the internet; also your name server | `192.168.178.1` | PC: `ipconfig`, *Default Gateway* |
| **Network address** | the name of your whole network, not a device | `192.168.178.0` | your IP address with the last number set to `0` (with mask `255.255.255.0`) |

Most home networks use mask `255.255.255.0`: all devices share the first three numbers
(`192.168.178.`), only the last one differs. The network address is then those three
numbers with `.0`: for `192.168.1.x` it is `192.168.1.0`, for `10.0.0.x` it is `10.0.0.0`.

The examples below use these values. Use your own.

## 3. Install STinG

From the STinG archive:

| File | Goes to |
|---|---|
| `AUTO\STING.PRG`, `AUTO\STING.INF` | `C:\AUTO` |
| `STING\TCP.STX`, `UDP.STX`, `RESOLVE.STX`, `DEFAULT.CFG`, `ROUTE.TAB`, `CACHE.DNS` | a folder `C:\STING` |
| `C:\ACSI_NET.STX` (from the adapter) | `C:\STING` as well |
| `TOOLS\PING.PRG`, `PING.RSC` | anywhere, e.g. `C:\STING\TOOLS` |

`STING.INF` contains the path of the STING folder (`C:\STING\`). The folder may also be
on a network drive (e.g. `F:\STING\`): the adapter's drives are there before the AUTO
folder runs. Leave out `SERIAL.STX` unless you use a modem.

## 4. Install XControl

- `XCONTROL.ACC` in the **root** of C: (accessories load from there only).
- The CPX modules in `C:\CPX`: from XControl at least `CONFIG.CPX`, from STinG
  `STING.CPX`, `STNGPORT.CPX` and `STNGPROT.CPX`.

Restart. At start-up STinG loads its modules; you should see

```text
ACSI_NET.STX 00.04: port ACSI2TNFS installed
```

## 5. Configure

**Port.** *Desk → Control Panel → STinG Port Setup*:

- port **ACSI2TNFS**
- IP address: your free address (`192.168.178.210`)
- subnet mask: `255.255.255.0`
- **Active** ticked, *Save*

When the port becomes active, the Pico switches its bridge on (USB console `w`:
*bridge on*).

**Routes.** `C:\STING\ROUTE.TAB` is STinG's signpost: for every packet it looks up
which way it has to go. Each line is *network, mask, port, gateway*, separated by tabs;
lines starting with `#` are comments. Replace the example line from the archive
(`... Modem 1 ...`) by these two:

```text
192.168.178.0	255.255.255.0	ACSI2TNFS	0.0.0.0
0.0.0.0		0.0.0.0		ACSI2TNFS	192.168.178.1
```

- **Line 1, your own network:** every address that starts with `192.168.178.` (your PC,
  the router, a NAS) is sent **directly**; gateway `0.0.0.0` means "no stop in between".
  Fill in your network address and subnet mask.
- **Line 2, everything else** (the internet): network `0.0.0.0` with mask `0.0.0.0`
  matches any address. It goes **via your router**: fill in the router's address as
  the gateway.

The order matters: STinG takes the first line that matches, so the general line comes
last.

**Name server.** The name server turns names like `info.cern.ch` into IP addresses
(DNS). At home that is almost always your router. In `C:\STING\DEFAULT.CFG`:

```text
NAMESERVER  = 192.168.178.1
THREADING   = 50
```

`THREADING` is in milliseconds: how often STinG polls the adapter. 50 is STinG's default
and costs about 1.5 % of the CPU; smaller values give a quicker response and cost more.

Restart once more, or use *STinG Port Setup* to activate the port.

## 6. Try it

- **Ping the router:** `PING.PRG`, host `192.168.178.1` (the default `127.0.0.1` is the
  Atari itself and does not use the network).
- **Ping the Atari from a PC:** `ping 192.168.178.210`. STinG answers by itself.
- **A web page:** URLVIEW from [Network tools for the Atari ST](https://github.com/RetroLoft/atari-net-tools).
- **FTP:** e.g. [gapFTP](https://atariuptodate.de/en/905/gapftp) (17 KB, command line):
  `GAPFTP.TTP ftp.funet.fi`.

## Speed and limits

- Measured over the local network: about **57 KB/s** with STinG's own `TCP.STX` 1.35
  and **69 KB/s** with the newer `TCP.STX` 1.41 by chzsoft
  ([github.com/chzsoft/sting](https://github.com/chzsoft/sting)); just replace
  `C:\STING\TCP.STX` with it. Recommended. The limit is how often STinG fetches the
  frames (every 50 ms), not the adapter.
- Saving is slower: with FTP about **24 KB/s** into a network drive and **11 KB/s**
  onto C: (C: is flash: every small write erases a 4 KB block).
- The Atari **cannot reach the Pico's own IP address** (the bridge drops such frames:
  they could not come back over Wi-Fi). Everything else on the network and the internet
  works.
- Some routers or mesh systems may not like two IP addresses on one MAC address. Home
  routers normally have no problem with it.
- STinG and XControl take memory and a timer interrupt. Some games do not start with
  them loaded (seen with Crystal Castles, also without `ACSI_NET.STX`): start those
  without STinG.

## Troubleshooting

| Symptom | Check |
|---|---|
| *no ACSI2TNFS found* at start-up | Adapter on, ACSI cable, ACSI id clash (see [ADAPTER.md](ADAPTER.md)) |
| *firmware without network function* | Firmware too old |
| *cannot pass frames (no Wi-Fi?)* | Wi-Fi not set up or not connected: `ACSITNFS.PRG`, console `n` |
| Port cannot be activated | IP address equal to the Pico's, or not a valid address/mask |
| Ping to the router fails | `ROUTE.TAB`, port active, console `w` (frames counted?) |
| Names do not resolve | `NAMESERVER` in `DEFAULT.CFG`, ping the router first |
| Download hangs at once | The target drive is full (Show Info on the drive) |

The USB console key `w` shows the bridge: on/off, the Atari's IP address and counters of
frames to and from the Atari (dropped, busy, errors).

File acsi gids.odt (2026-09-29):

ACSI-bussignalen en -beschrijvingen

Data (D0-D7)

Deze 8 actieve hoge signalen zijn de databits.

Data Request (_DRQ)

Wordt door het randapparaat gebruikt om een DMA-datatransfer aan te vragen. Deze lijn wordt gebruikt om een byte aan data aan te vragen tijdens de DMA-datatransfer. De richting van de transfer wordt

geïdentificeerd door het R/_W-signaal, dat wordt aangestuurd door de

DMA Read/Write-bit in het DMA Mode Control

Register. _DRQ wordt aangestuurd door het randapparaat met een

open collector-uitgang. Alleen randapparaten die

door het host-randapparaat zijn aangestuurd, mogen _IRQ, _DRQ of de databus aansturen. Een randapparaat mag niet

spontaan de aandacht van de host trekken.

Chip Select (_CS)

De Atari ST schrijft een commando- of databyte naar het

randapparaat, of leest een handshake- of statusbyte

van het randapparaat. Wanneer A1 en R/_W laag zijn,

waarschuwt het activeren van CS (laag) alle ACSI-randapparaten

dat de eerste byte van een commandopakket naar

de bus wordt gestuurd. De eerste byte bevat de bedieningscode van het apparaat

en het ACSI-apparaatnummer. _CS (laag),

R/_W (laag) met A1 hoog, wordt vervolgens geactiveerd voor elk van

de resterende commandobytes. Na voltooiing van een

commando (meestal gesignaleerd door ontvangst van een andere

interrupt van het apparaat) wordt de apparaatstatus (meestal

1 byte) door de Atari ST gelezen door _CS te activeren terwijl A1 hoog is. De meeste standaardcommando's zijn zes

bytes lang, maar alleen de commando's Inquiry, Read en Test Unit Ready hoeven zes bytes te zijn,

om consistentie te behouden bij de identificatie van

en het "opstarten" van verschillende typen apparaten.

Perifere bevestiging (_IRQ)

Dit actieve-lage signaal wordt door het doelperifere apparaat aangestuurd

om aan te geven of (a) het klaar is om een volgende

commandobyte te accepteren, of (b) er een byte beschikbaar is om te worden

gelezen. Alle perifere apparaten moeten _IRQ zo snel mogelijk deactiveren

binnen maximaal 20 microseconden

na de volgende dalende flank van _CS (en idealiter binnen 500 ns).

Adres 1 (A1)

Wanneer dit signaal laag is tijdens een _CS-schrijfbewerking, geeft dit aan dat

de eerste byte van een nieuw commando (dat de

apparaatselectie-ID bevat) door de Atari ST wordt aangeboden.

Bij alle andere lees- en schrijfbewerkingen in de stijl van _CS moet A1

hoog zijn.

Lezen/_Schrijven (R/_W)

Wordt gebruikt om de richting van de gegevensoverdracht over de

ACSI-bus te bepalen. Laag betekent dat de gegevensstroom van de Atari ST naar het

perifere apparaat gaat, d.w.z. schrijven. Hoog betekent dat er gegevens van het randapparaat naar de Atari ST worden verzonden, oftewel gelezen.

Host Acknowledge (_ACK)

De Atari ST gebruikt dit signaal om het randapparaat te laten weten

dat de Atari ST een DMA-databyte heeft ontvangen, of

dat er gegevens voor het randapparaat worden aangeboden. Dit is

een door de host aangestuurde reactie op het _DRQ-signaal dat door het randapparaat wordt gegenereerd.

Het signaal wordt door de Atari ST gebruikt om (a) aan een randapparaat te laten weten dat er een byte

DMA-data is ontvangen, of (b) om te reageren

op de _DRQ van het apparaat, waarmee wordt aangegeven dat de hostcomputer

DMA-data aanbiedt.

Reset (_RST)

Reset alle randapparaten. Reset de ACSI-bus en wist

alle lopende of in behandeling zijnde bewerkingen. Dit signaal heeft de

hoogste busprioriteit (heeft voorrang op alle andere

bussignalen) en is het systeemwijde resetsignaal.

Het resetsignaal mag alleen als ingang voor randapparaten worden gebruikt.

Opmerking:
Alleen randapparatuur die door de host is geselecteerd en een commando heeft verzonden, mag _IRQ, _DRQ of de databus aansturen. Een randapparaat mag niet spontaan de aandacht van de host trekken.

ACSI en SCSI - De verschillen

Enkele belangrijke verschillen tussen ACSI en SCSI:

Fysieke kabelverbinding - ACSI gebruikt een afgeschermde kabel met 19 pinnen, in tegenstelling tot de platte lintkabel met 50 pinnen die door SCSI wordt gebruikt.

De master/slave-relatie - Deze definieert wie de controle heeft over de busbewerkingen tussen de computer en de randapparatuur. De ACSI-bus specificeert dat de hostcomputer altijd de controle over de bus heeft, in tegenstelling tot SCSI, waarbij zowel computers als randapparatuur de controle over de bus kunnen initiëren.

Maximale kabellengte - ACSI staat een maximale afstand van 60 cm tussen apparaten toe, met een

totale toegestane lengte van 223 cm. De totale kabellengte moet echter tot een minimum beperkt worden in het belang van de signaalbetrouwbaarheid. SCSI heeft een totale toegestane lengte van ongeveer 5,5 meter.

Maximaal aantal apparaten - Voor de betrouwbaarheid van het systeem mogen niet meer dan vier

ACSI-perifere controllers in serie geschakeld worden op een Atari ST.

Gebruik van de SCSI-berichtfase (uitgebreide status) - SCSI staat dit toe, ACSI niet.

Verbinden en loskoppelen - de mogelijkheid voor een apparaat om los te koppelen na ontvangst van een

commando en alleen verbinding te maken wanneer er gegevens moeten worden overgedragen. ACSI maakt hier geen gebruik van, SCSI wel.

Busafsluiting - SCSI gebruikt open-collector busdrivers met afsluitweerstanden van 220/330 ohm. ACSI gebruikt CMOS- of LSTTL-interface zonder afsluitweerstanden.

Verzoek/Bevestiging - Er is een belangrijk conceptueel verschil tussen ACSI

en SCSI met betrekking tot het verzoek/de bevestiging. Handshaking. SCSI gebruikt een eenvoudige

REQ/ACK-procedure, terwijl ACSI CS/IRQ- en DRQ/ACK-procedures heeft. Zie "Command/Status/Data Transfers" hieronder voor een gedetailleerde uitleg van dit verschil.

Maximaal aantal commando's - Omdat het ACSI-controllerapparaatnummer

gecodeerd is in de drie meest significante bits van de commandobyte, kan het apparaat alleen commando's gebruiken in het bereik $00-$1F.

Command/Status/Data Transfers - SCSI draagt alle commando's, status- of data-informatie

over met behulp van de REQ/ACK (Request/Acknowledge) handshake. Of dit

in een "DMA"-modus gebeurt of met byte-voor-byte-overdrachten via de controllerprocessor,

is afhankelijk van de gebruikte SCSI-controller. ACSI biedt twee methoden voor het overdragen van informatie tussen de hostprocessor en het randapparaat:

1. Software-handshake-methode waarbij elke byte onder processorcontrole wordt overgedragen.

Deze methode gebruikt de CS- en IRQ-signalen. De processor activeert

CS om een byte over te dragen en Het randapparaat activeert _IRQ om de processor te laten weten dat het klaar is om de byte te ontvangen of te verzenden. De richting van de overdracht wordt

bepaald door het R/_W-signaal. Deze handshake-sequentie wordt altijd gebruikt voor

het verzenden van commando's en het ontvangen van de enkele statusbyte die wordt uitgegeven bij een fout of

voltooiing van een commando. Deze methode mag niet worden gebruikt voor gegevensoverdracht.

2. DMA-methode waarbij de processor een commando geeft (met behulp van de hierboven beschreven software-handshake-methode) waarin het randapparaat dat bij de gegevensoverdracht betrokken is, het type commando en het maximale aantal over te dragen blokken (512 bytes) worden gespecificeerd. Merk op dat DMA de bus deelt met de processor - de bus wordt alleen gebruikt wanneer de FIFO's gevuld/geleegd moeten worden. De FIFO's minimaliseren de overhead die gepaard gaat met het verkrijgen en vrijgeven van de bus. De overdracht wordt als voltooid beschouwd wanneer alle bytes zijn overgedragen (d.w.z. het DMA-tellerregister == 0) of wanneer er een fout optreedt. Deze methode maakt gebruik van de DRQ/ACK-handshake voor elke byte die onder DMA-controle wordt overgedragen. Dit is een zeer snelle hardware-handshake die plaatsvindt zonder enige tussenkomst van de processor. ACK is een reactie op het door het randapparaat gegenereerde DRQ-signaal en geeft aan dat de host een byte heeft ontvangen of klaar heeft om te verzenden. DRQ wordt geactiveerd door het randapparaat wanneer het klaar is om een byte te verzenden of te ontvangen.

Hardwareoverzicht - DMA

Er is een direct hoofdgeheugentoegangskanaal beschikbaar ter ondersteuning van 8-bits apparaatcontrollers. Het basisadres voor de DMA-lees- of -schrijfoperatie wordt geladen in de DMA-basisadresregisters.

Er is slechts één kanaal beschikbaar, waardoor er slechts één DMA-bewerking tegelijk kan worden uitgevoerd.

De daadwerkelijke DMA-bewerking wordt uitgevoerd via twee FIFO-buffers van 16 bytes. De DMA-controller wordt geprogrammeerd via het DMA-moduscontroleregister (16-bits woordbreed, alleen schrijven, niet gereset door systeemreset) en het DMA-sectortellerregister (16-bits woordbreed, waarvan momenteel alleen de minst significante byte is geïmplementeerd). Het succes of falen van een DMA-bewerking kan worden gerapporteerd via het DMA-statusregister (16-bits woordbreed, alleen lezen). (Dit register wordt echter zelden gebruikt; meestal geeft een perifeer apparaat een interrupt om de voltooiing aan te geven.) Het wijzigen van de status van DMAOUT in het DMA-moduscontroleregister reset de DMA-controller.

Hardwareoverzicht - ACSI

De ACSI-commando's lijken sterk op de SCSI-commando's. Elk commando wordt verzonden

als een commandopakket en is doorgaans 6 tot 10 bytes lang. De lengte van het commandopakket

wordt bepaald door de vereisten van de perifere controller. Voor programmeerdoeleinden

in dit document wordt ervan uitgegaan dat ACSI-commando's een lengte hebben van

zes bytes.

OPMERKING: In de praktijk kunnen commando's, met uitzondering van het Inquiry-, Read- of Test Unit Ready-commando

(voor opstartbare apparaten), meer of minder dan zes bytes lang zijn.

Het Inquiry-commando moet altijd zes bytes lang zijn voor consistentie.

Het Read-commando moet, bij gebruik met opstartbare apparaten, zes bytes lang zijn om

compatibel te zijn met de Atari-opstartroutines.

De eerste byte bevat de commando-opcode in de onderste vijf bits en het ACSI-eenheidsnummer

in de bovenste drie bits. Elk van de acht mogelijke apparaten op de ACSI-bus

heeft een eigen uniek apparaatnummer (0-7) dat meestal wordt ingesteld met een dip-schakelaar op de

controllerkaart. Een apparaat mag alleen reageren op commando's die met zijn controllernummer worden verzonden. Om ACSI-protocolschendingen (bijv. het gebruik van gedeeltelijke commando's) te voorkomen, moet een controller een commando herkennen dat naar een ander apparaat wordt verzonden en de bus onmiddellijk vrijgeven en terugkeren naar de inactieve toestand, d.w.z. wachten op een nieuw commando.

De eerste byte van een commandopakket wordt herkend wanneer A1 laag is, R/_W laag is en

_CS laag wordt. CS wordt (automatisch) gegenereerd wanneer de DMA-datapoort wordt gelezen of

beschreven door de Atari ST. A1 is alleen relevant wanneer een _CS optreedt. Alle randapparatuur

moet de bus gedurende deze tijd bewaken. Wanneer een apparaat zijn apparaatnummer herkent

en een geldig commando ontvangt, moet het zijn businterface inschakelen en het interruptsignaal activeren

om aan te geven dat het het commando heeft geaccepteerd en klaar is voor de volgende byte (of een

statusbyte beschikbaar heeft).

De resterende bytes van het commandopakket worden verzonden met A1 hoog, waarbij de Atari ST opnieuw _CS activeert voor elke byte. De gereedheid om de volgende byte te accepteren (en dus

de ontvangst van de vorige byte) wordt bevestigd door het perifere apparaat dat de IRQ activeert.

De interrupt wordt door de Atari ST gewist bij het schrijven van de volgende byte. Dit is de Command-fase.

Nadat het perifere apparaat de laatste byte heeft ontvangen, gaat het verder met de datafase (indien aanwezig) van de opdracht. Na voltooiing van de datafase wordt een statusbyte beschikbaar gesteld en vervolgens wordt de interrupt geactiveerd. Dit is de Statusfase. De Atari ST

wacht op de interrupt en leest vervolgens de statusbyte door CS te activeren (met A1 hoog).

Wanneer de statusbyte is gelezen, moet het perifere apparaat de interrupt wissen en de bus verlaten.

Opmerking:
Bij sommige ACSI-randapparatuur is een vertraging van 20 microseconden vereist tussen

het verzenden van elke commandobyte en het controleren van bit 5 van het GPIP-register

op een interrupt. Houd altijd rekening met een vertraging van 20 microseconden.

Tijdens de data-invoerfase (DMA naar het Atari ST-geheugen) moet het randapparaat

aangeven dat er een byte beschikbaar is door _DRQ te activeren. De Atari ST bevestigt de

acceptatie van een byte door _ACK te activeren. Dit wist de vorige _DRQ, wat op zijn beurt

logisch gezien _ACK wist. In de praktijk wordt _ACK altijd 250 ns geactiveerd.

De Atari ST kan tot 127,5 KB (d.w.z. 255 blokken van 512 bytes) in één bewerking via DMA verwerken. Het is het beste als de DMA-invoer van een randapparaat in veelvouden van zestien bytes plaatsvindt.

Als dat niet het geval is, moeten meerdere commando's worden gegeven (zonder de DMA-controller te resetten) om ervoor te zorgen dat het randapparaat voldoende invoerbytes genereert, zodat ze de

volgende grens van 16 bytes overschrijden, waardoor de FIFO wordt geleegd en naar het Atari ST-geheugen worden geschreven.

Sample bit | GPIO | Signaal | Opmerking
bit0 | 6 | DATA0 | databus
bit1 | 7 | DATA1 | databus
bit2 | 8 | DATA2 | databus
bit3 | 9 | DATA3 | databus
bit4 | 10 | DATA4 | databus
bit5 | 11 | DATA5 | databus
bit6 | 12 | DATA6 | databus
bit7 | 13 | DATA7 | databus
bit8 | 14 | DIR | 245 richting
bit9 | 15 | OE | 245 enable (actief laag)
bit10 | 16 | CS | ACSI /CS
bit11 | 17 | RESET | /RESET
bit12 | 18 | ACK | ACSI ACK
bit13 | 19 | A1 | A1 lijn
bit14 | 20 | R/W | read/write

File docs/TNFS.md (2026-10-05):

# Network drives (TNFS)

[TNFS](https://github.com/spectrumero/tnfsd/blob/master/tnfs-protocol.md) is a small file
protocol made for retro computers. The adapter connects to up to three TNFS folders and
shows each as a normal drive on the Atari.

## Setting up a drive

In `ACSITNFS.PRG` → *Config*, per drive:

- **Server:** host name or IP address of the TNFS server (port 16384 unless set otherwise).
- **Folder:** the folder on the server, e.g. `/` or `/ATARI.ST`.
- **Letter:** D: to P: (TOS knows 16 drives). If the letter is taken, the next free one
  is used and the start-up screen says so.

*Save*; after the restart the drives appear. Install them on the desktop like C:
(*Options → Install Disk Drive*).

## Running a TNFS server

Any TNFS server works. The reference server is
[tnfsd](https://github.com/spectrumero/tnfsd) (Linux, macOS, Windows):

```text
tnfsd /path/to/atari/files          read and write
tnfsd -r /path/to/atari/files       read-only
```

On Windows, build it with MinGW (`make OS=Windows_NT`). Allow it through the firewall for
the private network (UDP and TCP port 16384).

Keep the server folder **out of cloud sync folders** (OneDrive, Dropbox): they may lock
or move files while the adapter writes.

## How it works

The Atari only knows hard disks with sectors and a FAT. The Pico reads the whole folder
tree from the server at start-up and makes a FAT16 partition out of it (up to 16 MB per
drive); file data is fetched from the server when the Atari reads it.

**Writing.** GEMDOS writes sectors: first the data, then the FAT and the directory entry
when the file is closed. The Pico keeps every written sector in a hidden file
`.A2T.TMP` on the server and reads it back from there. About a second after the Atari
stopped writing, the Pico compares the drive with the server and applies new, changed,
renamed and deleted files and folders. A large file can take a while to reach the
server; reads and writes of the Atari go on in between.

## When a drive cannot be used

If there is no Wi-Fi, the server does not answer, its name cannot be found or it refuses
the folder, the drive holds one read-only file, **`NET_ERR.TXT`**. Show it on the
desktop: it gives the reason, the server and the folder. Once the server can be reached,
press `N` on the USB console or restart the adapter: the drive then reads its folders
and the Atari sees them right away.

If the server forgets the adapter's session (tnfsd does that after 10 minutes without
contact, and on a restart), the adapter logs in again by itself.

## What to keep in mind

- **Files added on the server** are seen after the Pico re-reads the tree: at start-up,
  or USB console `N`. Changes made by the Atari itself are seen at once.
- **Names** are shown in 8.3 form: long names on the server are shortened
  (`LONGFILENAME.TXT` → `LONGFILE.TXT`, on a clash `LONGFI~1.TXT`). Names starting with a
  dot are hidden.
- **Size:** at most 16 MB per drive and about 1000 files and folders for all drives
  together; what does not fit is left out (console `n` says "some skipped").
- **Read-only files:** files without write permission on the server show as read-only.
- **`.A2T.TMP`** grows until the Pico restarts. Delete it on the server only while the
  Pico is off.
- **Speed:** writing to the server is slower than reading (every written sector makes two
  trips over the network); copying 300 KB into a network drive takes a few seconds, the
  sync to the server about 7 s more.
- TNFS drives and C: both work while the network function (STinG) is in use.

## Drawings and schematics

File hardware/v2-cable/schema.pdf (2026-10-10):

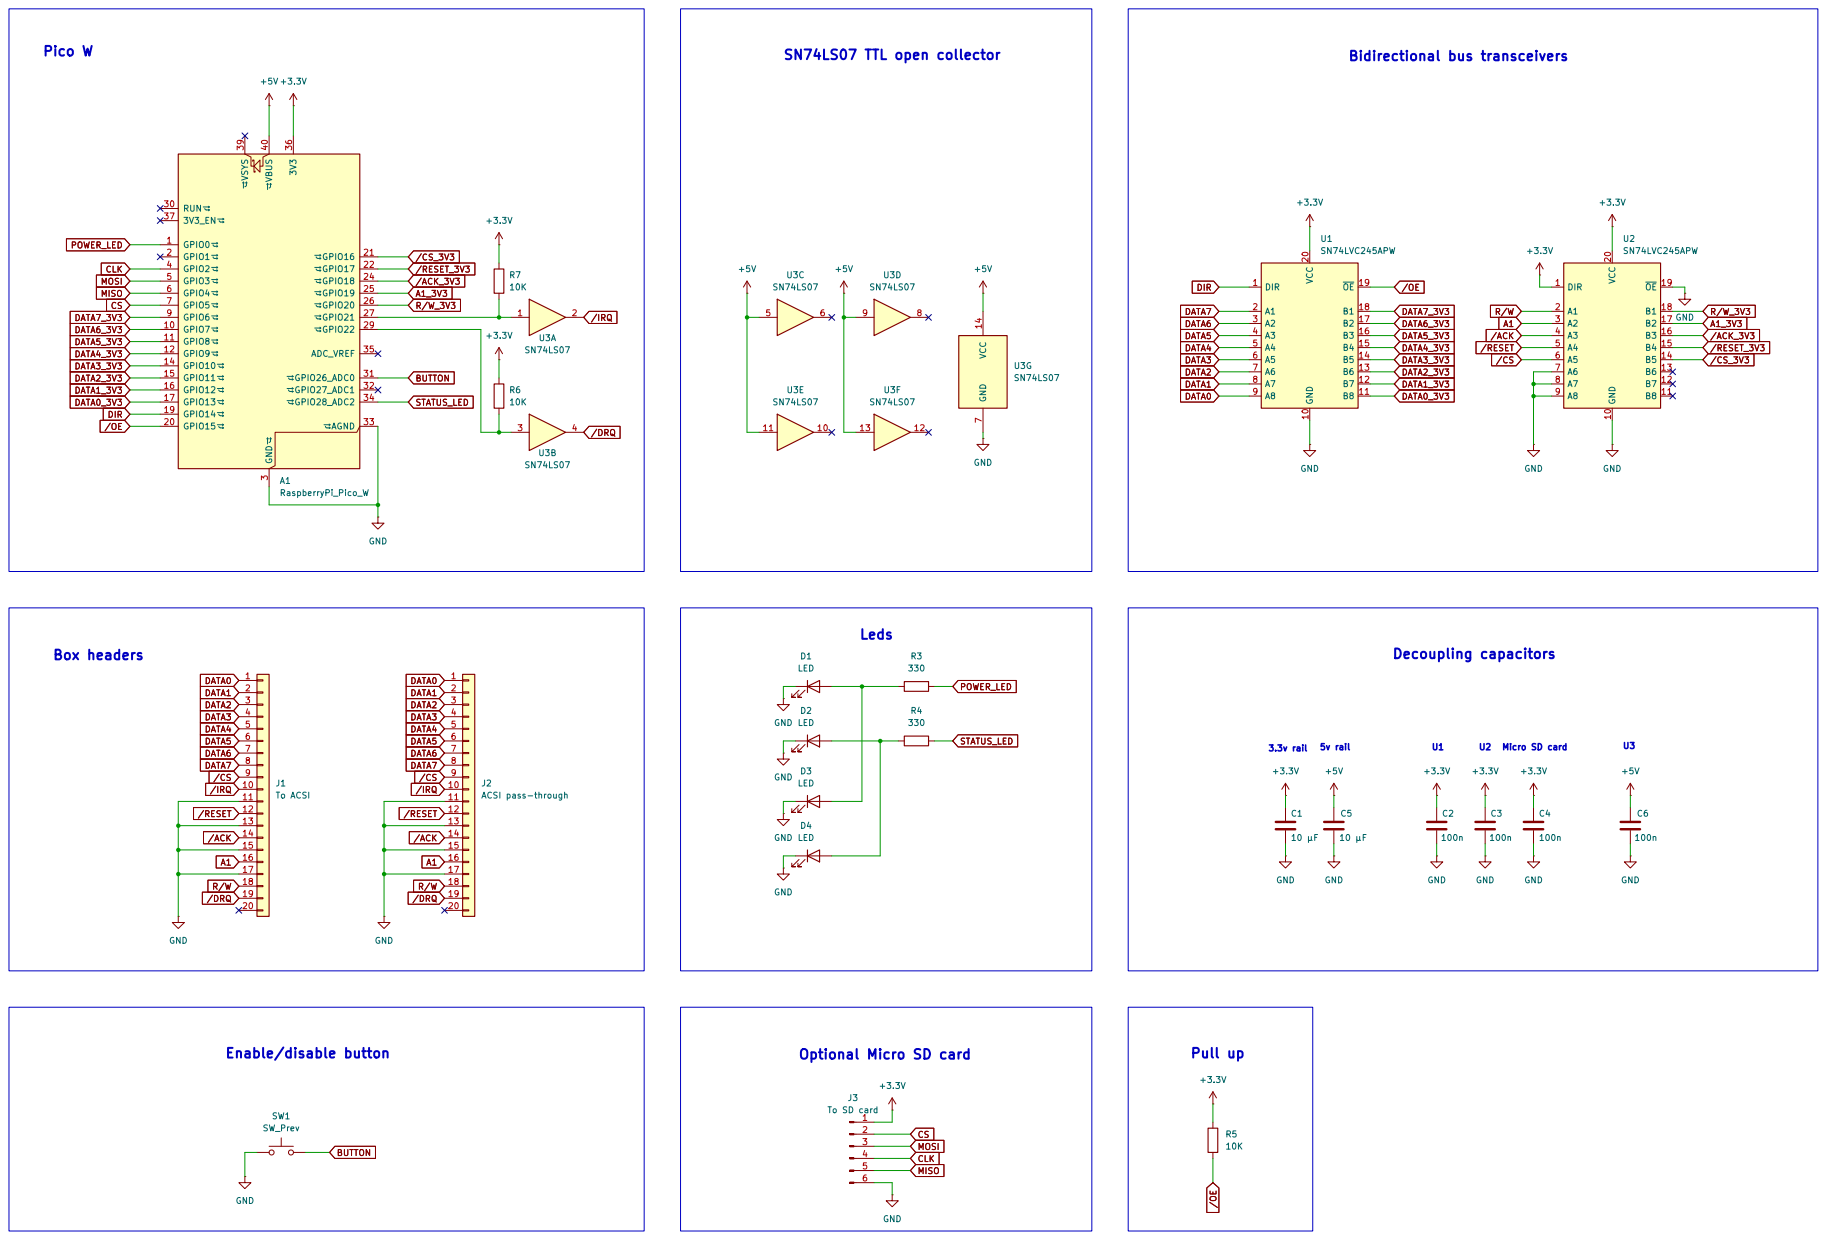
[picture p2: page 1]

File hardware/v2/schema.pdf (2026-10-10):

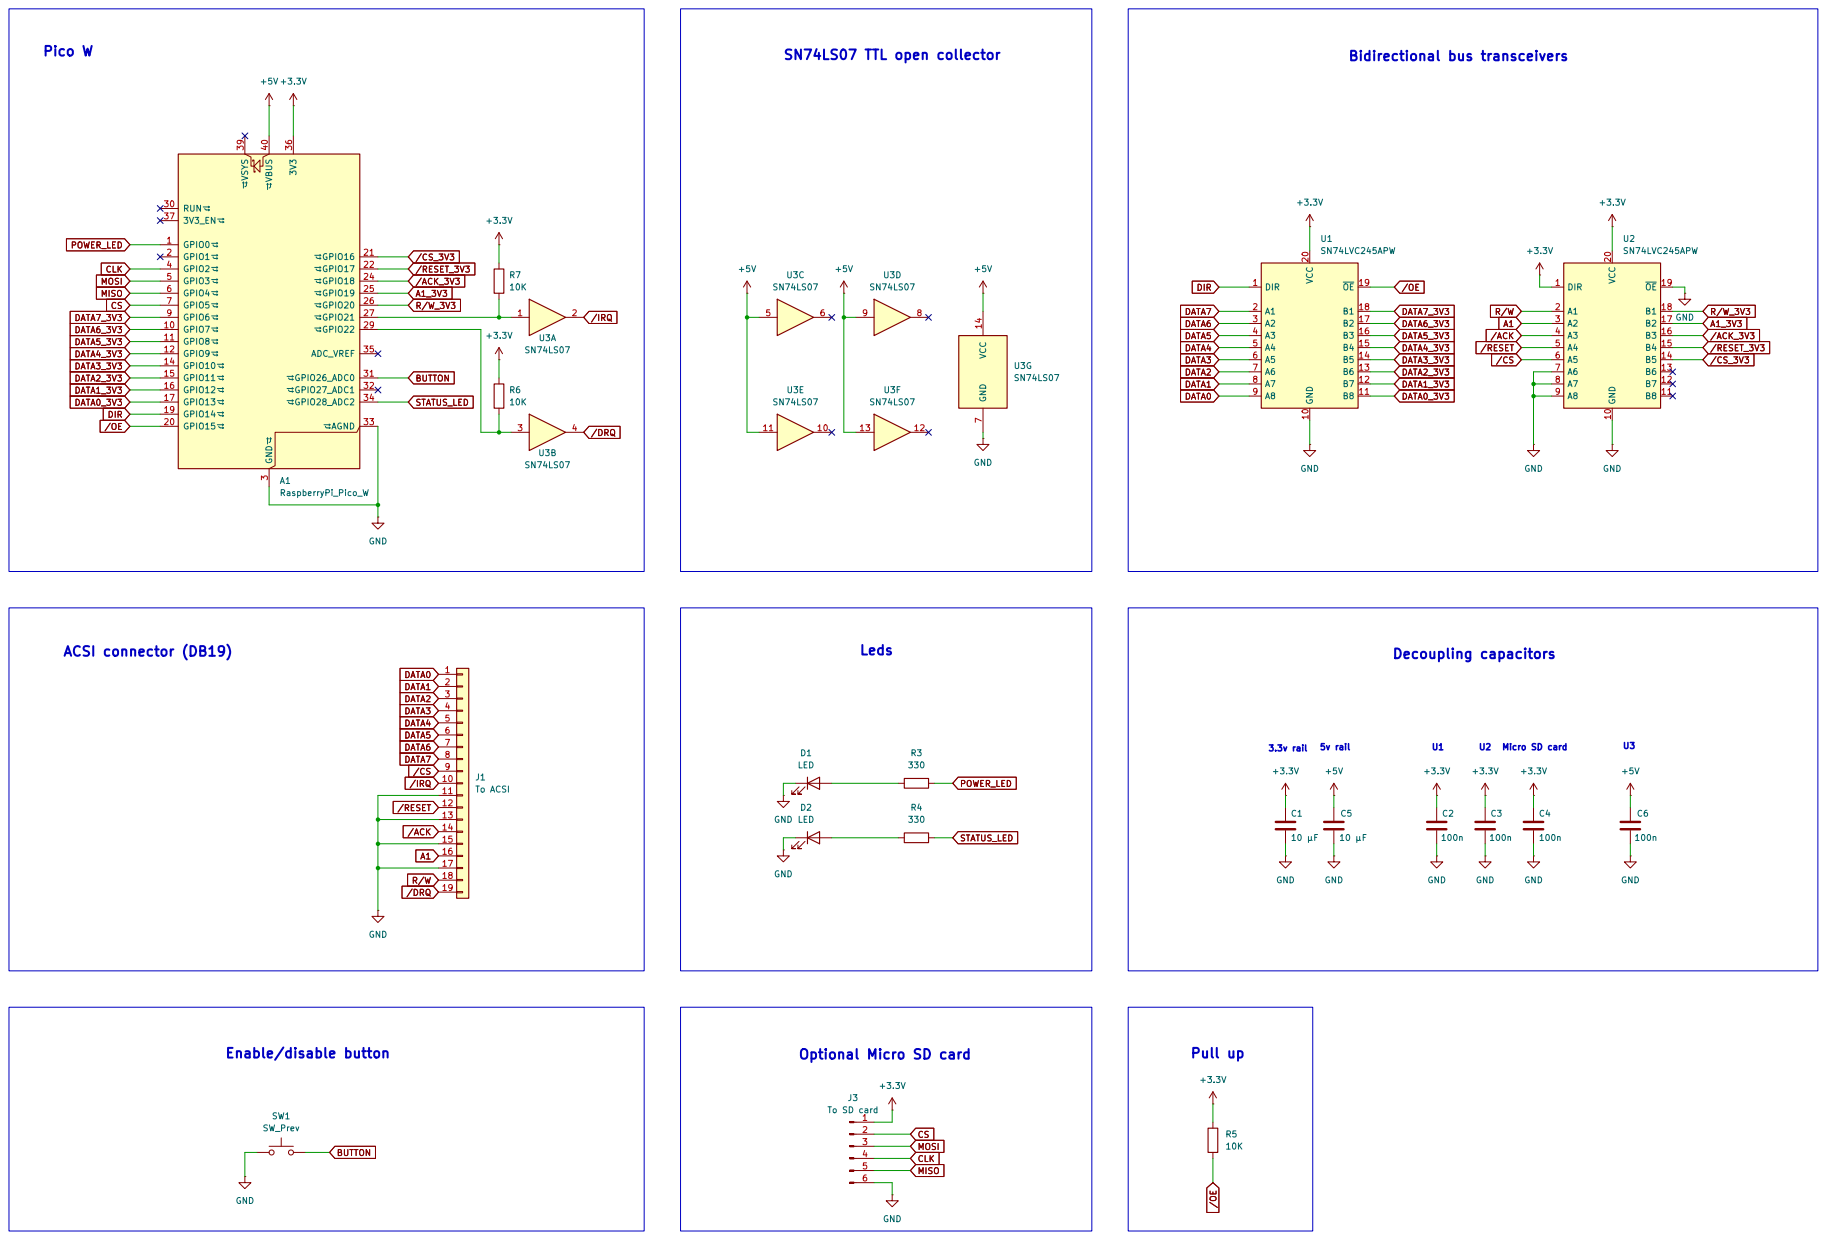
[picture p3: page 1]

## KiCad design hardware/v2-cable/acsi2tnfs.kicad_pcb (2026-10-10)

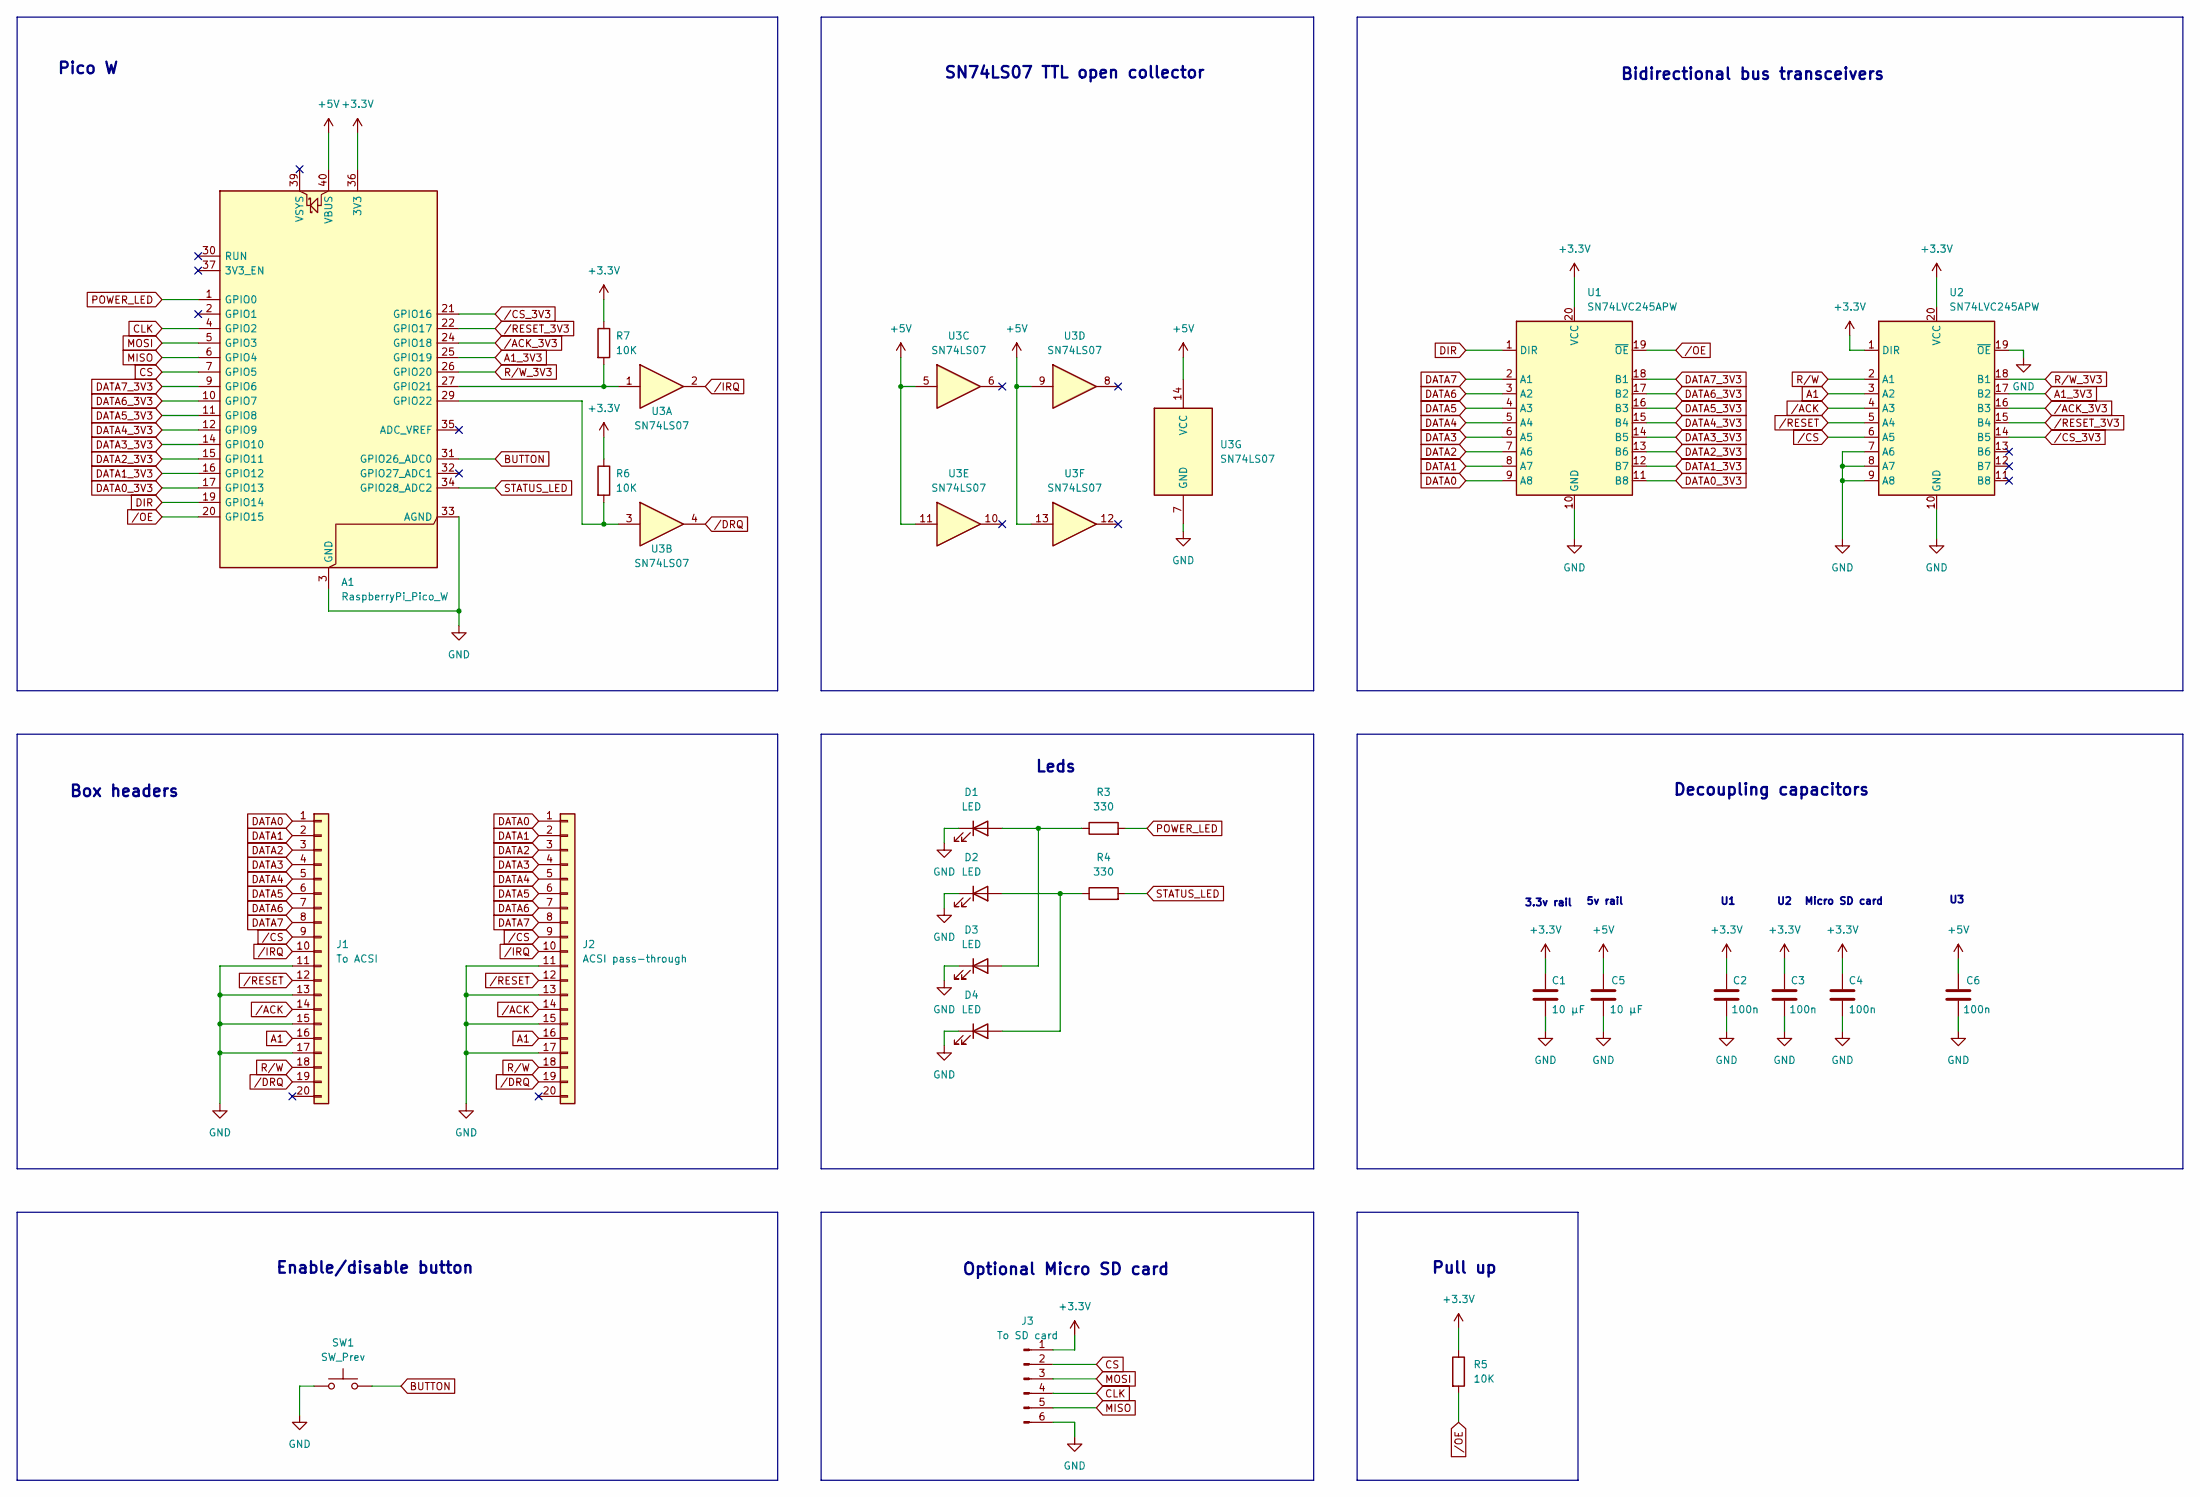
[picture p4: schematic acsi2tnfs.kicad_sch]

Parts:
A1: RaspberryPi_Pico_W; RaspberryPi_Pico_Common_THT
C1, C5: 10 µF; C_0805_2012Metric
C2, C3, C4, C6: 100n; C_0805_2012Metric
D1, D2: LED; LED_0805_2012Metric
D3, D4: LED; LED_D3.0mm
J1: To ACSI; IDC-Header_2x10_P2.54mm_Vertical_NR_PER_ROW
J2: ACSI pass-through; IDC-Header_2x10_P2.54mm_Vertical_NR_PER_ROW
J3: To SD card; PinHeader_1x06_P2.54mm_Vertical
R3, R4: 330; R_0805_2012Metric
R5, R6, R7: 10K; R_0805_2012Metric
SW1: SW_Prev; SW_Tactile_SKHH_Angled
U1, U2: SN74LVC245APW; SOIC-20W_7.5x15.4mm_P1.27mm
U3: SN74LS07; SOIC-14_3.9x8.7mm_P1.27mm

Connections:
+3.3V: A1.36 (3V3), C1.1, C2.1, C3.1, C4.1, J3.1, R5.1, R6.1, R7.1, U1.20 (VCC), U2.1 (DIR), U2.20 (VCC)
+5V: A1.40 (VBUS), C5.1, C6.1, U3.5, U3.9, U3.11, U3.13, U3.14 (VCC)
A1: J1.16, J2.16, U2.3 (A2)
A1_3V3: A1.25 (GPIO19), U2.17 (B2)
BUTTON: A1.31 (GPIO26_ADC0), SW1.2
CLK: A1.4 (GPIO2), J3.4
CS: A1.7 (GPIO5), J3.2
DATA0: J1.1, J2.1, U1.9 (A8)
DATA0_3V3: A1.17 (GPIO13), U1.11 (B8)
DATA1: J1.2, J2.2, U1.8 (A7)
DATA1_3V3: A1.16 (GPIO12), U1.12 (B7)
DATA2: J1.3, J2.3, U1.7 (A6)
DATA2_3V3: A1.15 (GPIO11), U1.13 (B6)
DATA3: J1.4, J2.4, U1.6 (A5)
DATA3_3V3: A1.14 (GPIO10), U1.14 (B5)
DATA4: J1.5, J2.5, U1.5 (A4)
DATA4_3V3: A1.12 (GPIO9), U1.15 (B4)
DATA5: J1.6, J2.6, U1.4 (A3)
DATA5_3V3: A1.11 (GPIO8), U1.16 (B3)
DATA6: J1.7, J2.7, U1.3 (A2)
DATA6_3V3: A1.10 (GPIO7), U1.17 (B2)
DATA7: J1.8, J2.8, U1.2 (A1)
DATA7_3V3: A1.9 (GPIO6), U1.18 (B1)
DIR: A1.19 (GPIO14), U1.1 (DIR)
GND: A1.3 (GND), A1.8 (GND), A1.13 (GND), A1.18 (GND), A1.23 (GND), A1.28 (GND), A1.33 (AGND), A1.38 (GND), C1.2, C2.2, C3.2, C4.2, C5.2, C6.2, D1.1 (K), D2.1 (K), D3.1 (K), D4.1 (K), J1.11, J1.13, J1.15, J1.17, J2.11, J2.13, J2.15, J2.17, J3.6, SW1.1, U1.10 (GND), U2.7 (A6), U2.8 (A7), U2.9 (A8), U2.10 (GND), U2.19 (~OE), U3.7 (GND)
MISO: A1.6 (GPIO4), J3.5
MOSI: A1.5 (GPIO3), J3.3
unnamed: A1.27 (GPIO21), R7.2, U3.1
unnamed: A1.29 (GPIO22), R6.2, U3.3
unnamed: D1.2 (A), D3.2 (A), R3.1
unnamed: D2.2 (A), D4.2 (A), R4.1
POWER_LED: A1.1 (GPIO0), R3.2
R/W: J1.18, J2.18, U2.2 (A1)
R/W_3V3: A1.26 (GPIO20), U2.18 (B1)
STATUS_LED: A1.34 (GPIO28_ADC2), R4.2
/ACK: J1.14, J2.14, U2.4 (A3)
/ACK_3V3: A1.24 (GPIO18), U2.16 (B3)
/CS: J1.9, J2.9, U2.6 (A5)
/CS_3V3: A1.21 (GPIO16), U2.14 (B5)
/DRQ: J1.19, J2.19, U3.4
/IRQ: J1.10, J2.10, U3.2
/OE: A1.20 (GPIO15), R5.2, U1.19 (~OE)
/RESET: J1.12, J2.12, U2.5 (A4)
/RESET_3V3: A1.22 (GPIO17), U2.15 (B4)

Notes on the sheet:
Leds
Decoupling capacitors
Micro SD card
Enable/disable button
Bidirectional bus transceivers
SN74LS07 TTL open collector
Box headers
Pull up
5v rail
3.3v rail
Optional Micro SD card
Pico W

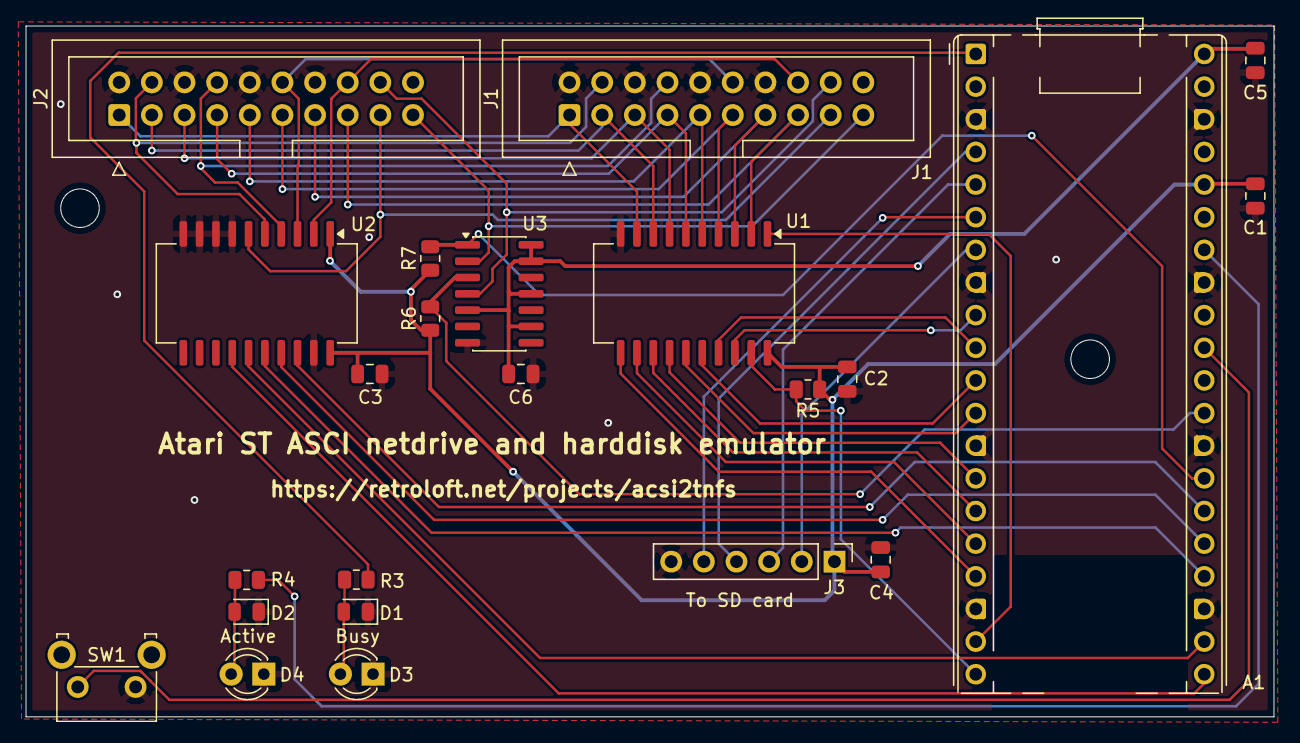
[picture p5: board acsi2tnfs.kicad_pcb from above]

Board: 2 copper layers, 97.1 x 53.8 mm, 23 parts (0 on the bottom side), 44 nets.

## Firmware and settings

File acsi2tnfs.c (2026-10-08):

/*
 * ACSI2TNFS - core0: USB console, sniffer decoder, settings
 *
 * USB serial commands:
 *   s  sniffer mode (passive)        t  target mode (flash hard disk)
 *   0..7 ACSI id                     v  verbose command log on/off
 *   i  info / statistics             B  reboot into BOOTSEL (flashing)
 *   h  help
 */
#include <stdio.h>
#include <string.h>
#include "pico/stdlib.h"
#include "pico/multicore.h"
#include "pico/flash.h"
#include "pico/bootrom.h"
#include "pico/rand.h"
#include "hardware/flash.h"
#include "hardware/watchdog.h"
#include "hardware/clocks.h"
#include "hardware/sync.h"
#include "hardware/structs/ioqspi.h"
#include "hardware/structs/sio.h"
#include "acsi.h"
#include "disk_seed.h"

extern uint32_t la_buf[];
extern volatile bool la_armed, la_done;
#define LA_WORDS 8192

/* defaults for a new adapter (nothing in flash yet): hard disk on ACSI id 6.
   Not 0: an internal Mega ST disk, a Megafile or an UltraSatan usually sits
   there, and two devices on one id answer at the same time. */
acsi_cfg_t g_cfg = { .mode = MODE_TARGET, .acsi_id = ACSI_DEFAULT_ID, .verbose = true };

/* media change counters (see acsi.h); random at start-up, so after a Pico
   restart the driver always sees a change and GEMDOS re-reads everything */
volatile uint8_t g_part_gen[4];

void disk_changed(int part)
{
    g_part_gen[part]++;
    /* C: is writable: keep GEMDOS off it until the driver has seen the
       change. The TNFS drives are read-only: a stale cache cannot hurt them */
    if (part == 0) g_cfg.mute_until_reset = true;
}

/* ---------------------------------------------------------------------------
   Settings in the last flash sector
--------------------------------------------------------------------------- */
#define CFG_MAGIC 0x41435349u   /* "ACSI" */
typedef struct { uint32_t magic; uint8_t mode, id, verbose, hidden; } cfg_flash_t;

/* settings sector layout: [0] cfg_flash_t, [256] network settings (net.c) */
#define CFG_NET_OFFSET 256
#define CFG_BYTES      4096   /* whole settings sector */
const void *net_settings_blob(uint32_t *len);
void net_settings_load(const void *blob);

static void cfg_load(void)
{
    const cfg_flash_t *f = (const cfg_flash_t *)(XIP_BASE + CFG_FLASH_OFFSET);
    net_settings_load((const uint8_t *)f + CFG_NET_OFFSET);   /* defaults when blank */
    if (f->magic != CFG_MAGIC) return;
    if (f->mode <= MODE_TARGET) g_cfg.mode = f->mode;
    if (f->id <= 7) g_cfg.acsi_id = f->id;
    g_cfg.verbose = f->verbose != 0;
    g_cfg.hidden = f->hidden == 1;      /* was padding (0) before */
}

static void cfg_write_cb(void *p)
{
    flash_range_erase(CFG_FLASH_OFFSET, FLASH_SECTOR_SIZE);
    flash_range_program(CFG_FLASH_OFFSET, (const uint8_t *)p, CFG_BYTES);
}

void cfg_save(void)
{
    static uint8_t page[CFG_BYTES];        /* RAM: XIP is off while programming */
    /* the id of the next boot: a change asked for by the configuration
       program is stored now but used only from the next reset */
    cfg_flash_t f = { CFG_MAGIC, g_cfg.mode, (uint8_t)acsi_next_id(), g_cfg.verbose, g_cfg.hidden };
    uint32_t nlen;
    const void *net = net_settings_blob(&nlen);
    memset(page, 0xff, sizeof page);
    memcpy(page, &f, sizeof f);
    memcpy(page + CFG_NET_OFFSET, net, nlen);
    int r = flash_safe_execute(cfg_write_cb, page, 1000);
    if (r != PICO_OK) printf("!! settings not saved (%d)\n", r);
}

/* ---------------------------------------------------------------------------
   Disk seeding: write the built-in disk image (disk_seed.h) into flash
--------------------------------------------------------------------------- */
/* the source must be in RAM: XIP is off while the flash is programmed */
static uint8_t seed_buf[FLASH_SECTOR_SIZE];

static void seed_cb(void *p)
{
    uint32_t blk = (uint32_t)(uintptr_t)p;
    flash_range_erase(DISK_FLASH_OFFSET + blk * FLASH_SECTOR_SIZE, FLASH_SECTOR_SIZE);
    flash_range_program(DISK_FLASH_OFFSET + blk * FLASH_SECTOR_SIZE, seed_buf, FLASH_SECTOR_SIZE);
}

static bool disk_seeded(void)
{
    return memcmp((const void *)(XIP_BASE + DISK_FLASH_OFFSET), disk_seed, 16 * 512) == 0;  /* boot + driver */
}

/* Same partition layout as the built-in image (root sector partition table
   and the C: boot sector's BPB)? Then only boot code and driver changed and
   the files on C: can stay. */
static bool disk_same_layout(void)
{
    const uint8_t *f = (const uint8_t *)(XIP_BASE + DISK_FLASH_OFFSET);
    return memcmp(f + 0x1c2, disk_seed + 0x1c2, 0x1fe - 0x1c2) == 0 &&
           memcmp(f + 16 * 512 + 11, disk_seed + 16 * 512 + 11, 0x3e - 11) == 0;
}

/* all = false: only sectors 0-15 (root sector and driver, flash blocks 0-1) */
static void disk_seed_write_part(bool all)
{
    uint32_t nblk = all ? DISK_SEED_BLOCKS : 2;
    if (all) printf("writing built-in disk image (%lu KB)...\n", (unsigned long)nblk * 4);
    else     printf("updating boot code and driver, files on C: are kept...\n");
    for (uint32_t b = 0; b < nblk; b++) {
        memcpy(seed_buf, disk_seed + b * FLASH_SECTOR_SIZE, FLASH_SECTOR_SIZE);
        int r = flash_safe_execute(seed_cb, (void *)(uintptr_t)b, 1000);
        if (r != PICO_OK) { printf("!! flash write failed at block %lu (%d)\n", (unsigned long)b, r); return; }
    }
    int bad = memcmp((const void *)(XIP_BASE + DISK_FLASH_OFFSET), disk_seed, nblk * FLASH_SECTOR_SIZE);
    printf("disk image %s\n", bad ? "VERIFY FAILED" : "written and verified");
}

static void disk_seed_write(void) { disk_seed_write_part(true); }

/* ---------------------------------------------------------------------------
   Sniffer decoder
--------------------------------------------------------------------------- */
static uint32_t t_origin;
static uint8_t  cmd[16];
static int      cmd_n;
static uint32_t cmd_t;
static uint32_t ack_n, ack_rw;
static uint8_t  ack_first[16];
static uint32_t last_ev_t;

static void ts(uint32_t t)
{
    uint32_t d = t - t_origin;
    printf("[%4lu.%06lu] ", (unsigned long)(d / 1000000), (unsigned long)(d % 1000000));
}

static void flush_acks(void)
{
    if (!ack_n) return;
    printf("               DMA %s %lu bytes:", ack_rw ? "device->ST" : "ST->device",
           (unsigned long)ack_n);
    for (uint32_t i = 0; i < ack_n && i < 16; i++) printf(" %02x", ack_first[i]);
    if (ack_n > 16) printf(" ...");
    printf("\n");
    ack_n = 0;
}

static void flush_cmd(void)
{
    if (!cmd_n) return;
    uint8_t op = cmd[0] & 0x1f;
    ts(cmd_t);
    printf("ID%u %-17s CDB:", cmd[0] >> 5,
           op == 0x1f && cmd_n > 1 ? scsi_opname(cmd[1]) : scsi_opname(op));
    for (int i = 0; i < cmd_n; i++) printf(" %02x", cmd[i]);
    if (op == 0x08 || op == 0x0a) {
        if (cmd_n >= 5)
            printf("  lba=%lu n=%u", (unsigned long)(((cmd[1] & 0x1f) << 16) | (cmd[2] << 8) | cmd[3]), cmd[4]);
    }
    if (cmd_n == 1) printf("  (only 1st byte: no device answered)");
    printf("\n");
    cmd_n = 0;
}

static void sniff_event(const acsi_event_t *e)
{
    uint16_t s = e->sample;
    switch (e->type) {
    case EV_CS:
        if (!(s & S_RW) && !(s & S_A1)) {           /* command start */
            flush_acks();
            flush_cmd();
            cmd[0] = S_DATA(s);
            cmd_n = 1;
            cmd_t = e->t_us;
        } else if (!(s & S_RW)) {                  /* further command byte */
            if (cmd_n && cmd_n < (int)sizeof cmd) cmd[cmd_n++] = S_DATA(s);
            else { ts(e->t_us); printf("CS write A1=1 %02x (no command start)\n", S_DATA(s)); }
        } else {                                   /* status read */
            flush_cmd();
            flush_acks();
            ts(e->t_us);
            printf("               STATUS read: %02x\n", S_DATA(s));
        }
        break;
    case EV_ACK:
        flush_cmd();
        if (ack_n < 16) ack_first[ack_n] = S_DATA(s);
        ack_rw = (s & S_RW) != 0;
        ack_n++;
        break;
    case EV_RESET:
        flush_cmd(); flush_acks();
        ts(e->t_us);
        printf("/RESET %s\n", s ? "released (high)" : "ASSERTED (low)");
        break;
    }
}

/* ---------------------------------------------------------------------------
   Target log
--------------------------------------------------------------------------- */
static void target_event(const acsi_event_t *e)
{
    static const char *resname[] = { "ok", "TIMEOUT", "RESET", "PROTOCOL" };
    if (e->type == EV_RESET) {
        ts(e->t_us);
        printf("/RESET %s\n", e->sample ? "released" : "asserted");
        return;
    }
    if (e->type != EV_CMD) return;
    const cmd_log_t *L = &g_cmd_log[e->idx];
    uint8_t op = L->cdb[0] & 0x1f;
    ts(e->t_us);
    printf("ID%u %-15s", L->cdb[0] >> 5, op == 0x1f ? scsi_opname(L->cdb[1]) : scsi_opname(op));
    for (int i = 0; i < L->cdb_len; i++) printf(" %02x", L->cdb[i]);
    printf(" | st=%02x", L->status);
    if (L->status) printf(" sense=%02x", L->sense);
    if (L->bytes) printf(" data=%lu acks=%lu", (unsigned long)L->bytes, (unsigned long)L->acks);
    printf(" %s %luus\n", resname[L->result & 3], (unsigned long)L->us);
    if (L->bytes && L->cap_n) {
        if (L->mism == 0xffff) printf("      ACK data matches (%u samples); tail got", L->cap_n);
        else printf("      ACK data MISMATCH at byte %u (%u samples); got", L->mism, L->cap_n);
        for (int i = 0; i < 8; i++) printf(" %02x", L->got[i]);
        printf(" exp");
        for (int i = 0; i < 8; i++) printf(" %02x", L->exp[i]);
        printf("\n");
    }
}

/* ---------------------------------------------------------------------------
   Console
--------------------------------------------------------------------------- */
static void help(void)
{
    printf("\nACSI2TNFS console. mode=%s id=%u verbose=%s%s\n",
           g_cfg.mode == MODE_SNIFF ? "SNIFF" : "TARGET", g_cfg.acsi_id, g_cfg.verbose ? "on" : "off",
           g_cfg.hidden ? "  ** HIDDEN from the Atari **" : "");
    printf("  s=sniffer  t=target  0-7=ACSI id  v=verbose  H=hide/show  K=clock  R=restore C: files  w=Atari net  i=info  B=bootsel  h=help\n\n");
}

static void info(void)
{
    printf("mode=%s id=%u cmds=%lu rd=%lu wr=%lu err=%lu resets=%lu ackmismatch=%lu\n",
           g_cfg.mode == MODE_SNIFF ? "SNIFF" : "TARGET", g_cfg.acsi_id,
           (unsigned long)g_stats.commands, (unsigned long)g_stats.sectors_read,
           (unsigned long)g_stats.sectors_written, (unsigned long)g_stats.errors,
           (unsigned long)g_stats.resets, (unsigned long)g_stats.ack_mismatch);
    printf("pins now: CS=%d RST=%d ACK=%d A1=%d RW=%d data=%02lx\n",
           gpio_get(PIN_CS), gpio_get(PIN_RST), gpio_get(PIN_ACK), gpio_get(PIN_A1),
           gpio_get(PIN_RW), (unsigned long)((gpio_get_all() >> PIN_D0) & 0xff));
}

/* console H or the BOOTSEL button */
static void toggle_hidden(void)
{
    g_cfg.hidden = !g_cfg.hidden;
    cfg_save();
    printf(g_cfg.hidden ? "-> HIDDEN: the Atari sees no device on id %u from its next boot, reset it now\n"
                        : "-> VISIBLE again on id %u, reset the Atari to boot from it\n", g_cfg.acsi_id);
}

/* The BOOTSEL button pulls the flash chip select low; it can only be read
   with that pin's output switched off for a moment (pico-examples
   picoboard/button). No code may run from flash meanwhile: core1 is held
   off through flash_safe_execute, interrupts are off here. */
static void __no_inline_not_in_flash_func(bootsel_cb)(void *param)
{
    const uint CS_PIN_INDEX = 1;
    hw_write_masked(&ioqspi_hw->io[CS_PIN_INDEX].ctrl,
                    GPIO_OVERRIDE_LOW << IO_QSPI_GPIO_QSPI_SS_CTRL_OEOVER_LSB,
                    IO_QSPI_GPIO_QSPI_SS_CTRL_OEOVER_BITS);
    for (volatile int i = 0; i < 1000; ++i) ;
#if PICO_RP2040
    *(bool *)param = !(sio_hw->gpio_hi_in & (1u << CS_PIN_INDEX));
#else
    *(bool *)param = !(sio_hw->gpio_hi_in & SIO_GPIO_HI_IN_QSPI_CSN_BITS);
#endif
    hw_write_masked(&ioqspi_hw->io[CS_PIN_INDEX].ctrl,
                    GPIO_OVERRIDE_NORMAL << IO_QSPI_GPIO_QSPI_SS_CTRL_OEOVER_LSB,
                    IO_QSPI_GPIO_QSPI_SS_CTRL_OEOVER_BITS);
}

/* every 100 ms; a press counts once, after two readings in a row */
static void bootsel_poll(uint32_t now)
{
    static uint32_t last;
    static int down;
    bool pressed = false;
    if (now - last < 100000) return;
    last = now;
    if (flash_safe_execute(bootsel_cb, &pressed, 10) != PICO_OK) return;   /* core1 busy: next time */
    if (!pressed) { down = 0; return; }
    if (++down == 2) toggle_hidden();
}

static void console(int ch)
{
    switch (ch) {
    case 's': g_cfg.mode = MODE_SNIFF;  cfg_save(); printf("-> SNIFF mode\n"); break;
    case 't': g_cfg.mode = MODE_TARGET; cfg_save(); printf("-> TARGET mode, id %u\n", g_cfg.acsi_id); break;
    case 'v': g_cfg.verbose = !g_cfg.verbose; cfg_save(); printf("verbose %s\n", g_cfg.verbose ? "on" : "off"); break;
    case 'H': toggle_hidden(); break;
    case 'K':
        net_clock_toggle();
        break;
    case 'i': info(); break;
    case 'n': net_console_status(); break;
    case 'w': net_bridge_console(); break;
    case 'W': net_bridge_trace(); break;
    case 'N': printf("network test requested\n"); net_request_test(); break;
    case 'R':
        /* restore the system files without touching the user's files; the
           Atari must not use C: meanwhile and has the old FAT cached */
        g_cfg.mute_until_reset = true;
        sleep_ms(100);                      /* a running command finishes */
        acsi_stage_invalidate();
        {
            int n = sysfiles_sync(disk_seed, true);
            if (n < 0) printf("!! restoring the system files failed\n");
            else printf("%d system file(s) restored or updated\n", n);
        }
        disk_changed(0);
        printf("C: changed: the driver reports a media change to GEMDOS\n");
        break;
    case 'F':
        /* the Atari still has the old FAT and directories cached: keep it
           off the bus until it resets, or its next write corrupts C: */
        g_cfg.mute_until_reset = true;
        sleep_ms(100);                      /* a running command finishes */
        acsi_stage_invalidate();
        disk_seed_write();
        disk_changed(0);
        printf("C: changed: the driver reports a media change to GEMDOS\n");
        break;
    case 'L': la_done = false; la_armed = true; printf("logic analyser armed (next WRITE)\n"); break;
    case 'l': {
        if (!la_done) { printf("no capture\n"); break; }
        const uint16_t *smp = (const uint16_t *)la_buf;
        uint16_t prev = 0xffff;
        int lines = 0;
        printf("LA t(16ns) D7-0 CS RST ACK A1 RW IRQo DRQo\n");
        for (uint32_t i = 0; i < LA_WORDS * 2 && lines < 4000; i++) {
            uint16_t v = smp[i] & 0x7fff;
            if (v != prev) {
                printf("LA %5lu %02x %d %d %d %d %d %d %d\n", (unsigned long)i, v & 0xff,
                       (v >> 8) & 1, (v >> 9) & 1, (v >> 10) & 1, (v >> 11) & 1, (v >> 12) & 1,
                       (v >> 13) & 1, (v >> 14) & 1);
                prev = v;
                lines++;
            }
        }
        printf("LA end\n");
        break;
    }
    case 'x': {
        static const uint32_t secs[] = { 17, 23, 29, 51, 52 };
        for (int k = 0; k < 5; k++) {
            const uint8_t *p = (const uint8_t *)(XIP_BASE + DISK_FLASH_OFFSET + secs[k] * 512u);
            printf("== sector %lu", (unsigned long)secs[k]);
            for (int i = 0; i < 512; i++) {
                if (i % 32 == 0) printf("\n%03x:", i);
                printf(" %02x", p[i]);
            }
            printf("\n");
        }
        break;
    }
    case 'd': {
        static const uint32_t secs[] = { 0, 1, 16 };
        for (int k = 0; k < 3; k++) {
            const uint8_t *p = (const uint8_t *)(XIP_BASE + DISK_FLASH_OFFSET + secs[k] * 512u);
            printf("sector %lu @%08lx:", (unsigned long)secs[k], (unsigned long)(uintptr_t)p);
            for (int i = 0; i < 16; i++) printf(" %02x", p[i]);
            printf(" ...");
            for (int i = 496; i < 512; i++) printf(" %02x", p[i]);
            printf("\n");
        }
        break;
    }
    case 'B': printf("rebooting to BOOTSEL\n"); sleep_ms(100); reset_usb_boot(0, 0); break;
    case 'h': case '?': help(); break;
    default:
        if (ch >= '0' && ch <= '7') {
            g_cfg.acsi_id = (uint8_t)(ch - '0');
            cfg_save();
            printf("ACSI id = %u\n", g_cfg.acsi_id);
        }
    }
}

int main(void)
{
#if PICO_RP2350
    /* the PIO timing was validated on the Atari at 125 MHz (RP2040 default) */
    set_sys_clock_khz(125000, true);
#endif
    stdio_init_all();
    cfg_load();
    acsi_hw_init();
    net_init();

    gpio_init(PIN_LED_PICO);
    gpio_set_dir(PIN_LED_PICO, GPIO_OUT);

    flash_safe_execute_core_init();
    multicore_launch_core1(core1_main);
    t_origin = time_us_32();
    sleep_ms(50);                       /* core1 registers as flash lockout victim */
    uint32_t r = get_rand_32();
    for (int k = 0; k < 4; k++) g_part_gen[k] = (uint8_t)(r >> (8 * k));
    bool need_seed = !disk_seeded();
    bool full_seed = need_seed && !disk_same_layout();
    if (need_seed) disk_seed_write_part(full_seed);
    /* new firmware: bring README.TXT / ACSITNFS.PRG on C: up to date, keep
       the user's own files (a deleted system file is only restored with R) */
    if (!full_seed && sysfiles_sync(disk_seed, false) > 0)
        disk_changed(0);                    /* a running Atari has the old FAT cached */

    uint32_t last_hb = 0;
    bool was_connected = false;
    for (;;) {
        acsi_event_t e;
        int budget = 256;
        while (budget-- && ev_pop(&e)) {
            last_ev_t = time_us_32();
            if (e.type == EV_DROP) { printf("!! %u events dropped\n", e.sample); continue; }
            if (e.type == EV_MODE) {
                flush_cmd(); flush_acks();
                printf("== mode %s, ACSI id %u ==\n", e.sample ? "TARGET" : "SNIFF", g_cfg.acsi_id);
                continue;
            }
            if (g_cfg.mode == MODE_SNIFF) sniff_event(&e);
            else target_event(&e);
        }
        uint32_t now = time_us_32();
        if ((cmd_n || ack_n) && now - last_ev_t > 20000) { flush_cmd(); flush_acks(); }

        bool conn = stdio_usb_connected();
        if (conn && !was_connected) {
            sleep_ms(50);
            help();
            if (need_seed) { printf("(disk image was missing and has been written at startup)\n"); need_seed = false; }
        }
        was_connected = conn;

        net_poll();
        cfgrpc_poll();

        int ch = getchar_timeout_us(0);
        if (ch >= 0) console(ch);

        if (g_cfg.save_req) { g_cfg.save_req = false; cfg_save(); }
        if (!BOARD_HAS_WIFI && now - last_hb > 500000) {  /* W: led shared with core1 */
            last_hb = now;
            gpio_put(PIN_LED_PICO, g_cfg.mode == MODE_TARGET ? 1 : !gpio_get(PIN_LED_PICO));
        }
        bootsel_poll(now);
        if (BOARD_HAS_WIFI) {               /* hidden: the Pico's own led blinks slowly */
            static int led = -1;
            int want = g_cfg.hidden && (now / 1000000) % 2;
            if (want != led) { led = want; net_led(want); }
        }
    }
}

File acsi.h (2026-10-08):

#pragma once
#include <stdint.h>
#include <stdbool.h>
#include "hardware/pio.h"

/* ---------------------------------------------------------------------------
   Pin map: verified PCB nets (ACSI2TNFS_hardwareoverzicht.md, section 2)
--------------------------------------------------------------------------- */
#define PIN_OE      6   /* U1 /OE, low = databuffer enabled                  */
#define PIN_DIR     7   /* U1 DIR, 1 = Atari -> Pico, 0 = Pico -> Atari      */
#define PIN_D0      8   /* D0..D7 = GP8..GP15                                */
#define PIN_CS      16
#define PIN_RST     17
#define PIN_ACK     18
#define PIN_A1      19
#define PIN_RW      20
#define PIN_IRQ     21  /* high = /IRQ asserted (Q1)                          */
#define PIN_DRQ     22  /* high = /DRQ asserted (Q2)                          */
#define PIN_LED     28  /* PCB status led                                     */
#ifdef CYW43_WL_GPIO_LED_PIN
/* Pico W / Pico 2 W: the onboard led hangs on the Wi-Fi chip and GP25 is its
   SPI chip select, so never touch GP25 there; use the PCB status led. */
#define PIN_LED_PICO PIN_LED
#define BOARD_HAS_WIFI 1
#else
#define PIN_LED_PICO 25 /* onboard led of the Pico (non-W)                    */
#define BOARD_HAS_WIFI 0
#endif

/* bits in a 13-bit PIO sample (GP8..GP20) */
#define S_DATA(s)   ((uint8_t)((s) & 0xff))
#define S_CS        (1u << 8)
#define S_RST       (1u << 9)
#define S_ACK       (1u << 10)
#define S_A1        (1u << 11)
#define S_RW        (1u << 12)

#define ACSI_PIO    pio0
#define SM_CS       0
#define SM_ACK      1
#define SM_DOUT     2
#define SM_DIN      3

/* ---------------------------------------------------------------------------
   Flash layout (Pico: 2 MB)
     0x000000 .. 0x0FFFFF  firmware (incl. the built-in disk image)
     0x100000 .. 0x1FEFFF  disk image (512-byte sectors)
     0x1FF000 .. 0x1FFFFF  settings
--------------------------------------------------------------------------- */
#define DISK_FLASH_OFFSET   0x100000u
#define DISK_SECTORS        2040u
#define CFG_FLASH_OFFSET    0x1FF000u

/* Virtual FAT16 partition backed by the TNFS server (Wi-Fi boards only).
   16 MB: TOS 1.x Rwabs sector numbers are signed 16-bit (512-byte sectors). */
#define VFAT_START          4096u
#define VFAT_SECTORS        32760u
/* One partition per TNFS drive, every VFAT_STRIDE sectors from VFAT_START.
   The root sector has 4 entries: C: plus up to 3 TNFS drives. */
#define VFAT_STRIDE         32768u
#define VDRIVES_MAX         3

/* Root sector: byte holding the ACSI id (patched by the firmware at runtime) */
#define ROOT_ID_OFFSET      2

/* FW_VERSION_STR comes from version.txt (set by CMakeLists.txt) */
#ifndef FW_VERSION_STR
#error "FW_VERSION_STR not set: build with CMake (version.txt)"
#endif

enum { MODE_SNIFF = 0, MODE_TARGET = 1 };

#define ACSI_DEFAULT_ID     6           /* id of a new adapter, see acsi2tnfs.c */

typedef struct {
    volatile uint8_t mode;       /* requested mode                        */
    volatile uint8_t acsi_id;    /* our ACSI controller number (0..7)     */
    volatile bool    verbose;    /* log every command in target mode      */
    volatile bool    save_req;   /* core1 asks core0 to store settings    */
    volatile bool    hidden;     /* act as if unplugged: answer only our own
                                    vendor command ($11 'AT'), nothing else */
    volatile bool    mute_until_reset; /* C: was rewritten under a running Atari:
                                    answer only our vendor command until the
                                    driver has seen the media change (sub 10)
                                    or the Atari resets, so GEMDOS cannot
                                    write with its stale FAT */
} acsi_cfg_t;

extern acsi_cfg_t g_cfg;

/* ---------------------------------------------------------------------------
   Event ring core1 -> core0
--------------------------------------------------------------------------- */
enum {
    EV_CS = 0,      /* sample = /CS sample                                   */
    EV_ACK,         /* sample = /ACK sample                                  */
    EV_RESET,       /* sample = 0 reset asserted, 1 released                 */
    EV_CMD,         /* target: finished command, see cmd_log                 */
    EV_DROP,        /* sample = number of dropped events                     */
    EV_MODE,        /* sample = new mode                                     */
};

typedef struct {
    uint32_t t_us;
    uint16_t sample;
    uint8_t  type;
    uint8_t  idx;   /* EV_CMD: index into cmd_log                            */
} acsi_event_t;

typedef struct {
    uint8_t  cdb[12];
    uint8_t  cdb_len;
    uint8_t  status;
    uint8_t  sense;
    uint8_t  result;    /* 0 ok, 1 timeout, 2 reset, 3 host protocol error */
    uint32_t bytes;     /* data bytes moved                                */
    uint32_t acks;      /* /ACK pulses counted during data phase           */
    uint32_t us;        /* duration                                        */
    uint16_t cap_n;     /* /ACK samples captured (first 1024)              */
    uint16_t mism;      /* first byte where ACK data != sent data, or 0xffff */
    uint8_t  got[8], exp[8];
} cmd_log_t;

#define CMD_LOG_N 32
extern cmd_log_t g_cmd_log[CMD_LOG_N];

void ev_push(uint8_t type, uint16_t sample, uint8_t idx);
bool ev_pop(acsi_event_t *e);

/* statistics */
typedef struct {
    volatile uint32_t commands;
    volatile uint32_t sectors_read;
    volatile uint32_t sectors_written;
    volatile uint32_t errors;
    volatile uint32_t resets;
    volatile uint32_t ack_mismatch;
} acsi_stats_t;
extern acsi_stats_t g_stats;

void acsi_hw_init(void);

/* network (net.c) - only functional on boards with Wi-Fi */
void net_init(void);                                   /* core0, at start      */
void net_poll(void);                                   /* core0, main loop     */
void net_led(bool on);                                 /* core0: the Pico's own led (W) */
void net_request_test(void);                           /* console N: reconnect */
uint32_t net_status_text(char *p, uint32_t max);       /* console n            */
uint32_t net_vdrives(void);                            /* TNFS partitions (fixed after start-up) */
uint8_t net_vdrive_letter(uint32_t k);                 /* wanted letter of partition k, 0 = any */
void net_clock(uint8_t *out);                          /* core1: vendor sub 9 (network time) */
uint32_t net_clock_sync_state(void);                   /* 0 off, 1 synchronised, 2 not yet */
void net_clock_keep(void);                             /* before a watchdog reboot */
void net_clock_toggle(void);                           /* console K */
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

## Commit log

2026-09-29 ACSI2TNFS: sniffer and flash-backed ACSI hard disk on a Raspberry Pi Pico
    - Passive ACSI sniffer mode with command/DMA/status decoding over USB serial
    - Target mode: ACSI hard disk in the Pico flash, PIO + DMA based bus handling
    that copes with the slow /DRQ release of the BC547 on the dev board
    - Atari side: root-sector boot code, small resident driver, CONFIG.TOS
    - Vendor command $11 'A' 'T' (info, led, ACSI id)
    - Diagnostics: /ACK cross-check, PIO logic analyser, sector dumps
    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
    [acsi2tnfs-B_Cu.gbr, acsi2tnfs-B_Mask.gbr, acsi2tnfs-B_Paste.gbr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]
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2026-09-30 Virtual FAT16 drive backed by the TNFS server (read-only)
    - Second partition (16 MB, GEM, FAT16) added to the served root sector;
    the driver mounts it as the next drive letter (D:)
    - core0 connects Wi-Fi and mounts TNFS automatically at start-up, scans the
    whole tree (OPENDIR/READDIR/STAT) and assigns fixed cluster runs, so the
    FAT never changes under GEMDOS' cache
    - Boot sector, FATs and directories are generated per read; file data comes
    from TNFS OPEN/LSEEK/READ with a cached open handle
    - core1 hands virtual sector reads to core0 and waits; the boot sector is
    served by core1 itself so the driver boots without network
    - Long server names mapped to unique 8.3 names; files marked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
    [acsi.h, acsi_core1.c]
2026-09-30 Configuration over ACSI for the SideTNFS GEM app, fix skipped 0xFF bytes
    - config.c: SideTNFS config protocol v3 (drives, network, RTC, save,
    reboot, status) carried over vendor subcommands 5/6
    - settings.h: settings record with 8 drive slots, network and RTC
    fields; the 0.3 format is migrated into drive slot 0
    - Wi-Fi uses the configured country, auth mode and static IP settings
    - acsi_bus.pio: ignore /ACK for ~64 ns after putting a byte on the bus.
    Switching all data lines to 0xFF looked like a strobe and made the
    device skip a byte, corrupting larger programs loaded from C:
    - Flash reads are staged in RAM and streamed with high-priority DMA
    - CONFIG.TOS option 5 sends the TOS cras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
    [acsi.h, acsi2tnfs.c, acsi_core1.c]
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2026-09-30 Format C: as FAT12 and pick the FAT type from the cluster count
    C: has only 1000 clusters. EmuTOS (like DOS) treats a volume with fewer
    than 4085 clusters as FAT12, so it misread our FAT16 C: and could not
    follow cluster chains (AUTO programs failed to load). mkdisk.py now
    writes FAT12 for small volumes and the driver sets the BPB's 16-bit
    flag only for 4085 clusters or more.
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2026-09-30 Driver also sets the GEMDOS current drive so a cold boot starts from C:
    TOS 1.x initialises GEMDOS before the floppy and hard disk boot and sets
    the current drive from _bootdev at that moment (xsetdrv(bootdev) in
    osinit). After a cold boot _bootdev is still A:, and the AUTO folder and
    the desktop inherit that drive. After a reset _bootdev kept C: from the
    previous session, which is why only warm boots used C:. The driver now
    calls Dsetdrv as well, like the hard disk drivers do.
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2026-09-30 Driver resets _bootdev to A: on every warm reset
    TOS calls resvector early in a warm reset, before GEMDOS takes its
    current drive from _bootdev. Without this, a reset after a session with
    the adapter kept C: as boot drive even when the adapter was hidden (no
    driver, no C:), so neither A:\AUTO nor A:\DESKTOP.INF were used. The
    handler restores the previous resvector/resvalid, so it runs once.
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2026-10-01 Boot screen, network clock, version.txt and ACSI id 6 as default
    - version.txt is the one version number: CMake passes it to the firmware
    (FW_VERSION_STR, program version) and ninja runs atari/mkdisk.py, which
    writes atari/version.inc and assembles boot code, driver and CONFIG.TOS
    - Boot screen in SideTNFS style, fits 40 columns: version, URL, then
    [..]/[OK]/[KO]/[--] status lines for Wi-Fi, drives, time server and the
    date; a countdown of 30 s per step, "Press [ESC] to skip" below it
    (VT52 save/restore cursor). The boot sector only speaks on failure.
    - 1 s pause after every noteworthy message (failures, drive letter taken)
    - Network clock: the Pico keeps the time via NTP (resync e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
    [acsi.h, acsi2tnfs.c, acsi_core1.c]
2026-10-01 ACSI id from the configuration program, console key K for the clock
    - Config commands GET_ADAPTER (0x0481) and SET_ACSI_ID (0x0482): the new
    id is stored by the next SAVE_CONFIG but used only from the next reset
    or restart, because the Atari still talks to the current id
    - Console K switches the network clock on/off and syncs at once
    - mkdisk.py puts every file of atari/files on C:
    - C: gets the ACSITNFS.PRG build with the ACSI device id under
    Config > More
    [acsi.h, acsi2tnfs.c, acsi_core1.c]
2026-10-01 Mute the adapter after a C: rewrite until the Atari resets
    After console F the running Atari still has the old FAT and directories
    cached; its next write would corrupt C:. The adapter now answers nothing
    until the next reset. C: gets the updated ACSITNFS.PRG.
    [acsi.h, acsi2tnfs.c, acsi_core1.c]
2026-10-01 Remove CONFIG.TOS: ACSITNFS.PRG and the USB console cover everything
    CONFIG.TOS and the vendor subcommands only it used are gone: info text (0),
    led blink (1), set ACSI id (2), legacy network settings (3), network test
    (4) and the crash report receiver (7). The ACSI id is set in ACSITNFS.PRG
    or on the USB console, the network test is console N. Left: 5/6 for the
    configuration program, 8 drive letters and 9 network time for the driver.
    [acsi.h, acsi2tnfs.c, acsi_core1.c]
2026-10-01 Read-only system files on C:, updated at start-up, restored with R
    - mkdisk.py marks README.TXT and ACSITNFS.PRG read-only
    - sysfiles.c: a small FAT12/16 writer on core0. At every start the system
    files on C: are compared with the built-in image; a changed one (new
    firmware) is rewritten into free clusters, the user's own files stay.
    Console R also puts back a deleted system file.
    - After R, F or a start-up update the adapter stays silent until the
    Atari resets, and core1 drops its cached flash block on every reset
    and after core0 changed C:, so it never writes a stale copy back
    - READMEs: console keys and how the system files behave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
    [acsi.h, acsi2tnfs.c, acsi_core1.c]
2026-10-01 Media change: GEMDOS re-reads C: or a TNFS drive after the Pico changed it
    The firmware keeps a change counter per partition (C: after R, F or a
    start-up update of the system files; a TNFS drive after a rescan), random
    at start-up. hdv_mediach asks for them with vendor sub 10 and reports
    "changed" until GEMDOS fetches the BPB again: GEMDOS then drops the
    drive's buffers, also unwritten ones, logs it in again and restarts the
    call. No Atari reset needed any more after R or F. The adapter stays
    muted for everything but its vendor command until the driver has picked
    up a change of C:, so a stale FAT is never written.
    [acsi.h, acsi2tnfs.c, acsi_core1.c]
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2026-10-02 Drive letters up to P:, reads of up to 256 sectors from RAM
    TOS knows 16 drives: a TNFS drive at T: overran GEMDOS' drive table and
    Fsnext lost it. Driver, firmware and ACSITNFS.PRG now keep letters at
    C:..P:. EmuTOS reads 255 sectors per READ(6); above 128 the firmware
    streamed from flash and a stall shifted the data, so the buffer is now
    256 sectors. READMEs: FOLDR100 on TOS 1.x, EmuTOS mounts the drives itself.
    [acsi_core1.c]
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2026-10-04 ACSI_NET phase 1: NET_INFO, NET_CTRL (settings only), NET_TEST and NETTEST.TTP
    Vendor subs 0x20 NET_INFO and 0x21 NET_CTRL next to the existing ones;
    NET_CTRL only stores the Atari IP and mask (cleared at an Atari reset),
    nothing is filtered or bridged. 0x2f NET_TEST sends 1-3 sectors of a
    known pattern for testing short DMA reads. Console key w shows the state.
    NETTEST.TTP (atari/tools) finds the adapter, shows NET_INFO, runs the
    short read test with sector 0 reads in between and recognises firmware
    without the network function.
    [acsi.h, acsi2tnfs.c, acsi_core1.c]
2026-10-04 ACSI_NET phase 1: NETTEST logs to NETTEST.LOG; test report
    Short DMA reads (3 sectors programmed, 1-3 sent) passed 6900 times.
2026-10-04 ACSI_NET phase 2: frame bridge (NET_TX, NET_RX, filter, rings)
    The Atari shares the Pico's MAC with its own IP. While NET_CTRL has the
    bridge on, a filter in front of lwIP's netif input hands IPv4 and ARP for
    the Atari's IP to an 8-frame receive ring; NET_RX sends only the sectors
    a frame needs (1 when empty). NET_TX checks length and source MAC, drops
    frames for the Pico's own IP and queues the rest in a 4-frame ring that a
    when-pending worker in the cyw43 context sends; BUSY (status 8) when full.
    Filter and Wi-Fi performance mode are only installed while the bridge is
    on; an Atari reset turns it off and empties the rings. core1 never waits
    for core0. NETTEST A/L: ARP to the router, listen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
    [acsi.h, acsi_core1.c]
2026-10-04 Reads: hold each byte ~130 ns after /ACK rises (was ~50 ns)
    With ~50 ns the DMA chip now and then still latched the next byte:
    NETTEST itself loaded with LINK A6,#$ffec turned into #$ecec and
    crashed, and 16 KB file reads failed their checksums. With ~130 ns:
    5984 KB read from C: and a TNFS drive, 0 errors, 0 /ACK cross-check
    mismatches in 517 reads, same speed (11.4 ms per 16 KB from C:).
    NETTEST: R (file reads only), line-buffered log, key wait on a fatal
    error, reference = two reads that agree.
2026-10-04 Reads: hold each byte ~130 ns after /ACK rises (was ~50 ns)
    With ~50 ns the DMA chip now and then still latched the next byte: a
    program loaded from the adapter got LINK A6,#$ffec as #$ecec and
    5984 KB read from C: and a TNFS drive without an error, no /ACK
    cross-check mismatch in 1538 reads, same speed (11.4 ms per 16 KB).
    Found while testing on the acsi-net branch (8b52cbc).
    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
2026-10-04 ACSI_NET phase 3: ACSI_NET.STX skeleton
    STinG port driver (gcc -mshort, no C library, 2.9 KB): finds the
    adapter, checks NET_INFO, adds the port ACSI2TNFS; activating the port
    sends NET_CTRL with its IP and mask. The receive routine polls NET_RX
    from the STinG thread with flock taken by TAS (skipped when a disk
    command holds it) and only counts the frames; datagrams to send are
    dropped. ARP and IP follow in phase 4. STinG headers port.h/transprt.h
    from the STinG dev kit (as used by usbsting).
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2026-10-04 TNFS: mount again when the server dropped the session
    tnfsd drops sessions after 10 minutes without contact (and forgets all of
    them on a restart); every request then gets status 0xFF and the drive was
    dead until a Pico restart or console N. Now the Pico mounts again on 0xFF:
    requests with a path are repeated, reads and writes through a file handle
    open the file again once (a dead handle used to read as zeros). The temp
    file with the Atari's unsynced sectors is no longer truncated when it is
    opened again after a new session, and a sync during which the session
    changed is done again a second later.
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2026-10-05 TNFS: a drive that cannot be used shows NET_ERR.TXT with the reason
    Without Wi-Fi, without an answer from the server or when the mount is
    refused, the drive used to be empty. Now it holds one read-only file,
    NET_ERR.TXT, with the reason, the server and folder and what to do (as
    SideTNFS does); GEMDOS is told to read the drive again. A later
    successful connect (console N, restart) replaces it by the real folders.
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2026-10-05 Activity led: no longer lit by empty NET_RX polls
    STinG polls NET_RX 20-50 times a second, which made the led flicker all
    the time. It now lights for NET_RX only when a frame goes to the Atari.
    [acsi_core1.c]
2026-10-08 Notes: floppy interference, v2 check, v1 test plan
    The dev board's 3k3 pull-ups on /IRQ and /DRQ go to the board's own 5V
    and drag the lines down when it is off; the ST shares the data bus and
    /IRQ with the floppy controller. v2 already leaves them out. Plan:
    /OE pull-up, measure the ST's own pull-ups, then remove the 3k3s; v1
    needs a board setting in the firmware and pull-ups on its LS07 inputs.
2026-10-08 ACSI_NET.STX 00.07: take flock only when the whole word is 0
    TAS on $43e tests only the high byte, so the STX could take the DMA chip
    in the middle of a floppy operation: wrong directories on the floppy and
    aborted NET_RX commands on the Pico. Now the word is tested and set to -1
    with interrupts off. Tested on the ST: floppy fine with STinG loaded, and
    a download onto a floppy while using it was identical.
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2026-10-11 hardware/acsi-adapter: DB19 to IDC20 adapter
    The DB19 of v2 (19 loose pins) wired 1:1 to an IDC20 box header numbered
    per row, pin 20 not connected, like the Lotharek adapter that comes with
    the UltraSatan. Works with every board that takes the flat cable. The
    footprints are in the project's own footprints.pretty.
2026-10-11 C: as FAT16 with 4096 clusters, so HDDRIVER reads it right
    AHDI and HDDRIVER read every GEM partition as FAT16; our driver, EmuTOS
    and DOS pick FAT12 below 4085 clusters. The 1000-cluster FAT12 C: was
    therefore misread by HDDRIVER on the Mega STE: files larger than one
    cluster gave "An error occurred while reading the source file".
    C: is now FAT16, 1 sector per cluster, 4096 clusters; the 2123 clusters
    past the end of the flash are marked bad. The disk reports VFAT_START
    sectors without TNFS drives, and the TNFS partitions move from 4096 to
    8192. The changed layout rewrites C: once on the first start.
2026-10-11 TNFS drives answer at once while the adapter connects
    core0 connected Wi-Fi, NTP and scanned every TNFS tree in one block and
    served no Atari request meanwhile. Our driver waits for that at boot,
    HDDRIVER does not: its reads timed out ("Data on the disk in drive M:
    may be damaged"). A large tree took about 40 seconds.
    - net_sleep_ms() in the network wait loops serves requests for drives
    that are not ready (no network needed for those)
    - vscan_dir() serves every request between two READDIRs, when no TNFS
    request is in flight; drives that are ready keep working
    - a drive that is not ready yet shows NET_WAIT.TXT instead of nothing
2026-10-12 TNFS: read folders when the Atari first reads them (lazy)
    After mounting only the root is read. A folder is read from the server
    when the Atari first reads one of its sectors; its files get a cluster
    run of their size, its folders 8 clusters (254 entries). A large server
    no longer has to fit in the node table and the 16 MB of one partition:
    only what is looked at in one session does.
    - new runs only go into FAT sectors the Atari has not read since its
    reset (fseen): GEMDOS cannot have cached those
    - what does not fit shows as a deleted entry; never deleted on the server
    - an Atari reset syncs what was written, then reads every tree again from
    the root; meanwhile the Atari sees "not read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
2026-10-12 ACSI_NET.STX 00.08: port address from DEFAULT.CFG, wait for Wi-Fi
    With ACSI_IP (and ACSI_MASK) in DEFAULT.CFG the module sets the port's
    address and switches it on itself: STNGPORT.CPX in XControl is no longer
    needed. Without them nothing changes. At start-up it waits up to 30 s
    for the adapter's Wi-Fi (a key skips): under HDDRIVER STinG loads before
    the Pico has joined after power-on.
    PORTINFO.PRG (make PORTINFO.PRG): STinG's view of its ports, routes and
    the ACSI_IP it read.
2026-10-12 Console: Wi-Fi RSSI and TNFS retries in n
    n shows the Wi-Fi signal (RSSI) and how many TNFS requests needed a
    retry or got no answer at all since start; every time-out is logged
    ("no answer to 0x21 (try 1)"). To tell a weak Wi-Fi from a server that
    does not answer. w no longer claims a Wi-Fi power mode: power saving is
    off all the time.
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2026-10-12 C: system files: write cache of four flash blocks
    Every cluster of a system file touches its data block and a block of
    each FAT. With one cached block that was three erases per cluster: after
    a firmware update ACSITNFS.PRG (309 clusters) took about 50 s at
    start-up, without a console, and a start-up cut off half-way left FAT 2
    erased. Four blocks (least recently used goes) keep the FAT blocks in
    RAM while the data streams through; at the end the highest blocks are
    written first: data, root directory, FAT 2, FAT 1.
    Measured: ACSITNFS.PRG replaced in 2.3 s; FATs equal, no lost clusters.
2026-10-12 NETCLOCK.PRG; ACSI_NET.STX counts down while waiting for Wi-Fi
    NETCLOCK.PRG sets the Atari's clock from the adapter's network time
    (vendor sub 9), for the AUTO folder of a machine where our boot driver
    does not load (HDDRIVER on a Mega STE, a TT booting from its own disk).
    Like the driver it waits up to 30 s each for Wi-Fi and the time server,
    counting down, ESC skips; then Tsetdate, Tsettime and Settime.
    ACSI_NET.STX shows the same 30 s countdown instead of dots while the
    adapter joins Wi-Fi.
2026-10-13 Console: SD card test (c) and /OE pull-up test (o)
    sdcard.c brings a micro SD card up in SPI mode on SPI0 (GP2 CLK, GP3
    MOSI, GP4 MISO, GP5 CS, the v2 pin map), reads CID, CSD and blocks; the
    start of the block layer for the SD card drive. Console c shows type,
    size, the partition table and the FAT boot sector. Tested on the dev
    board: a 32 GB SDHC card, FAT32 from a PC, SPI at 12 MHz.
    Console o sets /OE (GP6) and DIR (GP7) of U1 for 20 us as after a reset
    (input with the internal pull-down) and reads them: with the 10k pull-up
    of v2 /OE must be high, U1 off. The dev board here has it as a pull-down
    (/OE low): to be fixed on that board only, v2 has the pull-up.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
2026-10-13 SD card drives, read-only (phase 1)
    A drive of type SD shows a folder of the micro SD card (its path, e.g.
    /hd) through the same virtual FAT16 as the TNFS drives: lazy loading,
    the FAT rule and reset work as before. FatFs R0.15a (third_party/fatfs,
    BSD-style licence; long names, exFAT) reads the card; sdcard.c is its
    disk I/O. SD drives come up at start-up before Wi-Fi and also without
    it; no card or no such folder: the drive shows SD_ERR.TXT. Console N
    mounts the card again. Writing is refused for now (phase 2).
    Tested on the ST: a 32 GB FAT32 card with /hd next to two TNFS drives,
    browsing and starting programs, card out and in again with N.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
2026-10-22 hardware/v2-cable: solder mask to copper clearance 0.005 mm
    The design rule as used for the order at JLCPCB (gerbers made on
    2026-10-12).
2026-10-24 hardware/v2-cable: TF-01A micro SD socket on the board, new layout
    The SD module is replaced by a TF-01A push-push socket (LCSC C91145) that
    sticks out 2.4 mm over the front edge, flush with the case front. Button,
    leds and mounting holes moved to fit the 3D-printed case.
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2026-10-24 hardware/v2-cable: drop unused library files, update schema.pdf
    The TF-01A symbol is stored in the schematic and the 2x10 pin header
    footprint is not used. Card1 now uses the footprint from the project
    library, so the project no longer needs a global "Micro SD card" library.
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2026-10-25 Firmware for v2 and v2-cable only
    The pin map of the v2 boards: D7..D0 on GP6..GP13, DIR GP14, /OE GP15,
    /IRQ and /DRQ through a 74LS07 (low = asserted), button GP26, power led
    GP0. The data PIO programs reverse the bits with "::" and the DMA uses
    byte 3 of the FIFO word; the IRQ/DRQ outputs are inverted in the GPIO.
    The dev board pin map and its overview are gone.
    Hidden mode now goes with the board's button. The BOOTSEL button is no
    longer read: that held core1 off for ~150 us every 100 ms, and the /ACK
    check of large reads then missed strobes.
    Tested on v2-cable with an ST (project-notities.md).
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2026-10-25 Leds: D1 disk activity, D2 status
    D1 (GP0) lights on every READ/WRITE and stays on 1 s after the last one,
    like the led of a hard disk. D2 (GP28) is on, and blinks while the adapter
    is hidden. The Pico's own led is no longer used.
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2026-10-25 Lazy loading phase 2a: a full drive starts afresh by itself
    When a folder does not fit (clusters, nodes or names used up, e.g. after
    Show Info walked the whole tree), and a fresh tree would help, the drive
    starts afresh from the root once it has been idle for 2 s and reports a
    media change. Only with our driver, which asks for the change counters
    (vendor sub 10): with AHDI, HDDRIVER and EmuTOS GEMDOS would keep its old
    FAT. Tested on v2-cable with an ST (project-notities.md).
2026-10-25 Console M: removable unit, so HDDRIVER sees a drive that started afresh
    With M on, INQUIRY reports a removable unit: HDDRIVER then asks TEST UNIT
    READY, and after a full drive started afresh the next one answers UNIT
    ATTENTION, so GEMDOS reads the drives again without a reset. Off by
    default: with AHDI a removable unit is logged in again and again, with
    the whole FAT read each time, and lazy loading stops. Our own driver works
    the same either way.
    The adapter now answers only LUN 0 (HDDRUTIL saw it as 1.0 to 1.7). The
    README explains empty folders, Show Info (it opens every folder) and what
    to do per driver. Tested on v2-cable: Mega STE with HDDRIVER (M on) and
    an ST with AHDI (M off).
    Co-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
2026-10-25 A full drive starts afresh only for drivers that hear of it
    With console M on, the adapter counted one TEST UNIT READY as a driver that
    reports media changes. EmuTOS sends one at boot and never again: the drive
    was then laid out afresh while EmuTOS kept its old FAT. A restart now needs
    3 or more TEST UNIT READYs since the reset (HDDRIVER sends one every few
    seconds). EmuTOS added to the table of what to do per driver. Tested on an
    ST with EmuTOS 1.1.1.
2026-10-25 Two builds, and one store of nodes shared by all drives
    Every build makes acsi2tnfs.uf2 (production) and acsi2tnfs-dev.uf2
    (A2T_DEV: logic analyser, /ACK cross-check of reads, longer STinG frame
    timeline, sector dumps). The production build spends that RAM on the
    trees of the network and SD drives: 2400 nodes instead of 1024.
    The nodes, names and cluster owners of all drives now come from one store,
    so a drive that is used much takes what the others leave. All trees start
    afresh together: at an Atari reset, or at the ceiling once every drive has
    been idle for 2 s. Tested on v2-cable with an ST: TOS 1.04 with our driver
    (Show Info, writes on the LAN and SD drives) and EmuTOS.
    Co-Authored-By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
2026-10-25 NTP rounds after start-up no longer hold the drives up
    When the time server did not answer, ntp_sync waited 3 x 2 s, and in that
    time only drives that were not ready yet were served: reads of the network
    drives took 3-6 s every 30 s, and HDDRIVER timed out once. At connect the
    time is still fetched while waiting (the drives are not ready, our driver
    waits for the time); later rounds send a request and look for the answer
    from net_poll. Tested on v2-cable with an ST (TOS 1.04).
    Bigger partitions (phase B) are not done: with TOS 1.x the FAT would get
    8-16 sectors instead of 64 and lazy loading would hit the ceiling sooner.
2026-10-25 New system files reach C: without R
    The settings sector now keeps the list of system files the firmware put on
    C:. At start-up a missing system file on that list was deleted on purpose
    and stays away (R brings it back); one that is not on it is new in this
    firmware and is added. The list is stored only when it changes. Tested on
    v2-cable with a test firmware that carried an extra file.
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
